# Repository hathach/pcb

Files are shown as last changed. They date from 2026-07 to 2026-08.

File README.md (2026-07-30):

# pcb — PCB projects home

One repo, Adafruit-style: every board lives in its own directory here,
alongside the shared knowledge, footprints, and tooling that future
boards reuse. Board pico2_trace_motherboard's original 50-commit build
history is preserved on branch `archive/pico2-original`.

## Layout

| Entry | What |
| --- | --- |
| `pico2_trace_motherboard/` | Board #1: Pico 2 SWD+ETM trace carrier + TinyUSB dev/test bench (RP2350, 2-layer). Ordered: JLCPCB **W2026073018593887**, 2026-07-30, 5 PCB / 2 assembled, $81.27. |
| `docs/pipeline.md` | The netlist-driven KiCad pipeline + gate battery + how to bootstrap board #2. |
| `docs/kicad-pcbnew-facts.md` | Verified KiCad 9 scripting landmines (pcbnew API, kicad-cli, footprints). |
| `docs/parts-palette.md` | LCSC/JLC-verified parts with tiers + JLC fee behavior. |
| `docs/PICO2_TRACE_PCB_HANDOFF.md` | Origin brief for board #1 (fly-wire measurements, requirements). |
| `lib/pcb.pretty/` | Audited shared footprints: USB-C C165948 lands (power-only + USB2-device renumbers), FTSH-110/105 1.27mm headers. Copy into each board's local `.pretty`. |
| `tools/jlc-cdp/` | Chrome-DevTools JLCPCB ordering driver + wizard-trap playbook. |
| `tools/board_semantic_compare.py` | Prove two `.kicad_pcb` are geometrically identical (regen gate). |
| `tools/align_md_tables.py` | Markdown table column aligner (house style). |

## Starting a new board

Read `docs/pipeline.md` — short version: copy `pico2_trace_motherboard/hw/`
wholesale, gut the board-specific tables, keep every helper and gate, seed
footprints from `lib/pcb.pretty/`, and regenerate-never-hand-nudge.

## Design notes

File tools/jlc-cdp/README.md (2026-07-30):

# jlc-cdp — drive JLCPCB ordering via Chrome DevTools Protocol

Minimal CDP driver used to place the pico2_trace_motherboard order
(W2026073018593887, 2026-07-30) when the Claude-in-Chrome extension was
wedged. Works against a dedicated Chrome instance so the main browser is
untouched.

## Setup

```bash
# one-time: clone the main profile so logins (JLCPCB, 1Password) come along
pkill -TERM -f '^/opt/google/chrome/chrome'; sleep 4
cp -a ~/.config/google-chrome ~/.cache/jlc-cdp-profile
rm -f ~/.cache/jlc-cdp-profile/Singleton*
google-chrome &                                     # main browser back
google-chrome --user-data-dir=$HOME/.cache/jlc-cdp-profile \
  --remote-debugging-port=9222 --no-first-run \
  --new-window https://cart.jlcpcb.com/shopcart/cart &

python3 -m venv venv && venv/bin/pip install websocket-client
```

## Usage

```bash
venv/bin/python cdp.py tabs                       # list pages
venv/bin/python cdp.py eval  '<js>'               # run JS in the JLC tab
venv/bin/python cdp.py nav   '<url>'
venv/bin/python cdp.py shot  out.jpg [quality]    # screenshot (viewport)
venv/bin/python cdp.py click <css-x> <css-y>      # trusted click
venv/bin/python cdp.py files '<selector>' /path…  # attach to <input type=file>
```

Targets the first tab whose URL contains `jlcpcb` (else the first page).

## JLC-wizard lessons (hard-won, 2026-07-30 session)

- Re-uploading gerbers inside Edit Order DETACHES the PCBA section —
  re-enable it via the `.switch-box.cursor-pointer` toggle, then re-set
  PCBA qty and Confirm Parts Placement (a Confirm modal follows).
- Saving after a gerber re-upload forks a NEW cart item (Y(n+1)) next to
  the old one — delete the stale group (`i.icon-remove_icon`, then the
  `el-popconfirm` Delete button).
- BOM/CPL re-upload: two `input[type=file]`s (BOM first); the
  "Process BOM & CPL" button needs a real (trusted) click at its rect.
- The Product Description cascader clears on every re-walk: open the
  `input[placeholder=Select]`, dispatch pointer/mouse event sequences on
  the `li` items (plain .click() does not work), category
  "Reserch\Education\DIY\Entertainment" → "Development Board - HS 847330".
- Element-UI chip selection state is unreliable to read from classes —
  verify with a screenshot; state probes can lie while the click landed.
- WebGL pages (placement viewer) stall Page.captureScreenshot; canvas
  toDataURL returns black (no preserveDrawingBuffer). Verify placement in
  the visible window or via JLC's paid Confirm-Parts-Placement service.
- CPL convention JLC ingests: KiCad board frame (y-down, footprint
  anchor, KiCad rotation). Do NOT convert to the gerber/pos.csv frame.
- Deselecting a matched BOM line does NOT remove its Extended loading
  fee; any THT line present brings back the ~$7 hand-solder+manual block.

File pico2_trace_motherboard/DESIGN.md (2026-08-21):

# Pico 2 SWD + ETM-Trace Motherboard — Design Spec

- **Status:** design approved, pending implementation (KiCad schematic + layout)
- **Date:** 2026-07-24
- **Target probe:** SEGGER J-Trace PRO Cortex-M (V2 today; V3+ for full-rate RP2350 streaming)
- **Target module:** Raspberry Pi **Pico 2** (RP2350A) — also mechanically/pin compatible with the original **Pico** (RP2040); the design must not break RP2040 use.

## 1. Purpose

A carrier "motherboard" that a Pico / Pico 2 plugs into. It does two jobs:

1. **Trace/debug adapter** — presents a proper ARM Cortex **Debug+ETM MIPI-20** connector (SWD + 4-bit parallel trace) to a SEGGER J-Trace, replacing the fly-wire rig whose measured limits are in `PICO2_TRACE_PCB_HANDOFF.md`. It also offers a plain 2×5 Cortex-Debug header and two 3-pin JST-SH debug jacks, so a plain J-Link or a Raspberry Pi Debug Probe can drive the same SWD.
2. **TinyUSB dev/test bench** — exercises TinyUSB on both USB back-ends: the RP2350 **native** USB controller (the module's micro-USB, device or OTG-host) and **PIO-USB** (a USB-A host port and a micro-B device port on GPIOs), plus the peripherals and observability needed to develop and debug them.

Prior art consulted: SEGGER STM32H7/STM32F407 Trace Reference Board schematics (calibre library), the existing `metro_m7_1011_trace` KiCad board, the Adafruit `MBAdafruitBoards` Eagle libraries, and the RP2350 / Pico 2 datasheets.

## 2. Goals & non-goals

**Goals**
- 2 layers max. Solid bottom ground plane for trace return.
- Socket carrier: Pico 2 removable; its micro-USB and BOOTSEL stay accessible (recovery flow depends on both).
- One-probe-at-a-time debug hub: J-Trace (MIPI-20), plain J-Link (2×5), or Pi Debug Probe (JST-SH), all reaching the Pico's SWD.
- Full-rate-capable trace routing (source-terminated, short, guarded) — beat the fly-wire seating lottery.
- Two PIO-USB roles (host + device) + native USB, with power flexible enough to run each case.
- Bench observability: USB probe points, host VBUS switching + current sense, UART console independent of the USB-under-test.

**Non-goals (explicitly excluded, YAGNI)**
- No microSD / MSC storage (dropped by decision).
- No I2S audio codec (UAC2), no Ethernet PHY (net class), no RGB/NeoPixel.
- No second PIO-USB *host* port (GPIO32/33 don't exist on RP2350A anyway).

## 3. Form factor & stackup

- **PCB:** 2-layer FR4, 1.6 mm. Top = components + all signal routing; **bottom = solid GND pour** (continuous under the entire trace group). Approx. 60 × 30 mm (may grow; not size-constrained).
- **Socket carrier, "double-female" (Cytron Maker-Pi-Pico style):** per side, an **inner** 1×20 female socket the Pico plugs into, plus an **outer** 1×20 female **breakout** row net-tied pin-for-pin, so every one of the 40 pins is available for jumper wires. Placed on the KiCad `Module:RaspberryPi_Pico_Common_THT` outline (correct 0.1″ pitch, 0.7″ row spacing, USB/BOOTSEL silk). Inner sockets = `Connector_PinSocket_2.54mm:PinSocket_1x20_P2.54mm_Vertical` ×2; outer breakout = same. Concrete socket part: Sullins PPTC201LFBN-RC or equiv.
- Pico 2 keeps male 0.1″ headers (pins down) and lifts out. Micro-USB + BOOTSEL overhang the board edge.

## 4. Connectors & jumpers (reference designators)

| Ref | Part | Purpose |
| --- | --- | --- |
| J1, J2 | 1×20 female socket ×2 (inner) | Pico 2 socket |
| J1B, J2B | 1×20 female socket ×2 (outer) | per-pin breakout |
| J3 | MIPI-20 Cortex Debug+ETM, 2×10 1.27 mm shrouded/keyed (Samtec ASP-152705-01 / FTSH-110-01-L-DV-K) | J-Trace: SWD + 4-bit ETM |
| J4 | JST-SH 1.0 mm 3-pin, right-angle | cable to the Pico 2 DEBUG port (brings SWD onto the board) |
| J5 | USB-A receptacle, THT right-angle | PIO-USB **host** port |
| J6 | 2×5 1.27 mm Cortex Debug (Conn_ARM_JTAG_SWD_10 / FTSH-105-01-L-DV-K) | plain J-Link: SWD only |
| J7 | JST-SH 1.0 mm 3-pin, right-angle | Raspberry Pi **Debug Probe** ("pico-debug") jack, mirrors J4 |
| J8 | USB Type-C receptacle, **power-only** (as-built 2026-07-30; was micro-B) | 5 V input for host-stack work |
| J9 | USB Type-C receptacle (as-built 2026-07-30; was micro-B) | PIO-USB **device** port |
| JP1 | 3-pin header + shunt | board 5 V source select: VBUS-net ↔ J-Trace 5 V |
| JP2, JP3 | 2-pin header + shunt (default fitted) | GP0 / GP6 GND **guard** jumpers |
| JP4 | 2-pin header + shunt (default fitted) | native VBUS-detect tap enable → GP16 (§9) |
| SW1 | tactile button, top-mount, medium | RUN reset |

Debug connectors J3/J4/J6/J7 grouped on one board edge so the shared SWD fan-out stays short.

## 5. Debug/trace signal maps

### 5.1 MIPI-20 (J3), per the SEGGER J-Trace pinout (image-authoritative; verified against SEGGER STM32H7 ref board)

| Pin | Net | Source | | Pin | Net | Source |
| --- | --- | --- | --- | --- | --- | --- |
| 1 | VTref | Pico 3V3_OUT (pin 36) | | 2 | SWDIO | JST-SH DEBUG (as-built: J7/J10, see §5.3) |
| 3 | GND | | | 4 | SWCLK | JST-SH DEBUG (as-built: J7/J10, see §5.3) |
| 5 | GND | | | 6 | SWO | **NC** (RP2350 has none) |
| 7 | KEY | NC | | 8 | TDI | **NC** |
| 9 | GND | (GNDDetect → GND, per SEGGER ref board) | | 10  | nRESET | RUN (pin 30) |
| 11  | **5V-Supply** | J-Trace 5 V → JP1 | | 12  | TRACECLK | GP1 (pin 2) via Rterm |
| 13  | **5V-Supply** | J-Trace 5 V → JP1 | | 14  | TRACEDATA0 | GP2 (pin 4) via Rterm |
| 15  | GND | | | 16  | TRACEDATA1 | GP3 (pin 5) via Rterm |
| 17  | GND | | | 18  | TRACEDATA2 | GP4 (pin 6) via Rterm |
| 19  | GND | | | 20  | TRACEDATA3 | GP5 (pin 7) via Rterm |

### 5.2 Cortex Debug 2×5 (J6) — plain J-Link

Signals identical to MIPI-20 pins 1–10, wired in parallel on the shared SWD net: 1 VTref, 2 SWDIO, 3 GND, 4 SWCLK, 5 GND, 6 SWO(NC), 7 KEY, 8 TDI(NC), 9 GND, 10 nRESET. No 5 V pin.

### 5.3 SWD source (as-built: J7 / J10 — see "As-built deltas")

As-built, the connector originally planned as J4 (a second JST-SH jack) was
never populated; its role is filled by **J7** (JST-SH 3-pin, pinout
**SWCLK / GND / SWDIO**, accepts a Raspberry Pi Debug Probe cable) and
**J10** (3-pin THT dupont header, same pin order). Both are cabled to the
Pico 2's own onboard JST-SH DEBUG port — J7 via a JST-SH-to-JST-SH cable,
J10 via a JST-SH-to-dupont cable (both ship with the Debug Probe) — and
both land on the shared SWDIO/SWCLK/GND net that feeds J3 pin 2/4 and J6
pin 2/4. **One probe connected at a time.**

### 5.4 Trace signal integrity

- **Source series termination 27 Ω** (0402) on TRACECLK + TRACEDATA0–3, placed at the Pico socket pins (the breakout tap is on the socket-side of Rterm, so Rterm isolates it from the line).
- Traces ≈ 0.3 mm, **runs < 30 mm**, CLK↔data length-matched within a few mm, no stubs. Not chasing exact 50 Ω (impractical on 2-layer 1.6 mm); solid bottom GND + short length + source termination is sufficient for the J-Trace PRO V2's real ceiling (in-spec 100 MHz TRACECLK, ~120 MHz tuned — measured: 120 MHz passes on this board; the "150 MHz" an earlier revision cited here is the V3/V4 product-page figure) — the ~40 MHz cliff recorded against the original fly-wire rig was a fly-wire signal-integrity limit, not a V2 hardware limit (see `docs/BRINGUP.md` "Trace bring-up ladder").
- GND stitching vias around the trace group. MIPI-20 within ~3 cm of the socket.
- **GP1–GP5 carry nothing else** — no pulls, LEDs, or loading beyond a via/breakout. The five outer breakout females for GP1–GP5 are silk-marked **"unplug while tracing"** (a wire there is a fat antenna on a 40–75 MHz line).
- **Guard pins:** GP0 (pin 1, directly against TRACECLK, no GND between) and GP6 (pin 9) each have a 2-pin **removable jumper to GND** (JP2/JP3, default fitted). Fitted = grounded guard (GND on both sides of TRACECLK); their breakout females double as scope/sniffer GND next to the trace bus. Removed = pin freed. Rule: with a guard fitted, keep that GPIO an input.

## 6. GPIO pin map (Pico/Pico 2, RP2350A header)

| GPIO | Function | Notes |
| ---- | --- | --- |
| 0 | GND guard (JP2) | pin 1, next to TRACECLK; jumper to GND, default on |
| 1 | TRACECLK | funcsel 9 (CORESIGHT); also default UART0 RX — **not routed to UART** |
| 2–5  | TRACEDATA0–3 | funcsel 9 |
| 6 | GND guard (JP3) | pin 9, next to trace block; jumper to GND, default on |
| 7 | spare | |
| 8 | I2C0 SDA (STEMMA-QT) | moved off GP6/7 to keep active signals away from trace |
| 9 | I2C0 SCL (STEMMA-QT) | |
| 10 | user LED | |
| 11 | DEV_DP pull-up enable (soft-connect) | drive high = attach (1.5 kΩ to DEV_DP), Hi-Z = detach; decision input = GP27 |
| 12 | UART0 TX (console) | remapped off GP0/1 → **full-duplex console during trace** |
| 13 | UART0 RX (console) | |
| 14 | user button | to GND |
| 15 | host VBUS fault | load-switch open-drain flag; `OVERCURR_DETECT`-capable pin |
| 16 | native VBUS-detect tap | `VBUS_DETECT`-capable; 8.2k/8.2k from VBUS net via JP-gate |
| 17 | host VBUS enable | load-switch enable; `VBUS_EN`-capable pin |
| 18 | PIO-USB device D+ (J9) | |
| 19 | PIO-USB device D− (J9) | |
| 20 | PIO-USB host D+ (J5) | |
| 21 | PIO-USB host D− (J5) | |
| 22 | spare | |
| 26 | VBUS current-sense (ADC) | shunt + INA181 amp output |
| 27 | J9 device VBUS-detect | plain GPIO, 8.2k/8.2k divider |
| 28 | spare | ADC-capable |

Module-internal pins (not on header, unusable by the carrier): GP23 (SMPS PS), GP24 (VBUS sense), GP25 (LED), GP29 (VSYS/3 ADC).

Placement rationale for USB-mux pins: GP15/16/17 sit on `OVERCURR_DETECT` / `VBUS_DETECT` / `VBUS_EN`-capable pins (funcsel `0x0a`, which rotates by GPIO mod 3), so the native controller's hardware VBUS enable/detect/overcurrent can be funcsel-tested later — while normally serving as plain GPIOs.

## 7. Power architecture

- **VBUS net = Pico pin 40** = the module's micro-USB VBUS = J8 power-USB = external-5V breakout injection. All one node (the micro-USB VBUS is an *input* as device / *output* as OTG host, so it must be a hard bidirectional tie — cannot be diode-isolated or switch-broken).
- **JP1 (3-pin)** selects the board 5 V: **USB side (VBUS net) ↔ J-Trace 5 V (MIPI-20 pins 11/13).**
  - `JP1 = USB`: board runs from the module micro-USB (device), or J8, or external-VBUS.
  - `JP1 = JTRACE`: J-Trace 5 V drives the VBUS net; the module micro-USB is freed to be an **OTG host** (its VBUS is now sourced from pin 40); Pico powered via pin 40 → onboard VBUS→VSYS diode → VSYS → 3V3.
- **Rule:** exactly one hard 5 V source on the VBUS net at a time (module-USB-from-PC, J8, external-VBUS, or J-Trace). JP1 keeps J-Trace off the USB side; the user avoids doubling the USB-side sources.
- **J-Trace 5 V is current-limited** (a few hundred mA) — hungry downstream devices → use J8 or a strong USB supply.
- The VBUS net also feeds the **PIO-USB host (J5) VBUS** through the host load switch (§8.1).
- **VSYS** remains reachable on the breakout female for independent bench powering — used when testing native VBUS-detect transitions (§9).

## 8. USB ports

### 8.1 PIO-USB host (J5) — GPIO20 (D+) / GPIO21 (D−)
- 22 Ω series (0 Ω option) at the GPIOs; **15 kΩ pulldowns** on D+/D− at the receptacle; **ESD array** (USBLC6-2SC6 class).
- **VBUS via a current-limited load switch** (TPS2051B / AP22653 / MIC2005 class): enable = GP17, open-drain fault = GP15, 10–22 µF bulk + 0.1 µF at the connector. (Replaces the earlier plain polyfuse; the switch's current limit + fault flag give host over-current control/observability.)
- **Probe points:** TP pads on D+/D− + GND at the port for the ataradov sniffer / scope.

### 8.2 PIO-USB device (J9; USB Type-C as-built 2026-07-30) — GPIO18 (D+) / GPIO19 (D−)
- Series R + **ESD array** on D+/D−.
- **1.5 kΩ D+ pull-up, firmware-driven soft-connect:** 1.5 kΩ from DEV_DP to **GP11**; firmware drives GP11 high (3.3 V) to present the pull-up ("attached") or reconfigures it to Hi-Z input to soft-disconnect, so the board only signals "attached" when a host's VBUS is present (board is often self-powered, so 3V3 is up regardless). Gate decision input is **GP27** VBUS-detect. (A gate FET driven from the VBUS-detect divider midpoint was rejected: as a source-follower it can only pull D+ to ~Vgate−Vth, below the FS-attach threshold.)
- **VBUS-detect:** 8.2 kΩ/8.2 kΩ divider from J9 VBUS → **GP27** (plain GPIO, read by the PIO-USB stack). Divider chosen so the pin sees ~2.5 V (logic-high, < 3.3 V so RP2040-safe, < 3.63 V so within the RP2350 unpowered-failsafe for hot-plug-while-off; R_bottom = 8.2 kΩ satisfies the RP2350-E9 external-pulldown requirement).
- Default **detect-only** (self-powered). Optional (DNP) diode from J9 VBUS to the VBUS net if bus-powered device operation is ever wanted.

### 8.3 Native USB (module micro-USB)
- Device (into a PC) or OTG host (§7, `JP1 = JTRACE`). VBUS = pin 40. VBUS-detect for the native *device* controller is handled on-module (GP24 SIO + R10/R1) / by `USB_PWR` override — nothing added.

## 9. Native VBUS-detect hardware test tap

To exercise the RP2350 native controller's **hardware** VBUS_DETECT (`SIE_STATUS.VBUS_DETECTED` + interrupt), not just the software override:
- **8.2 kΩ/8.2 kΩ divider from the VBUS net → GP16** (a `VBUS_DETECT`-capable pin, funcsel `0x0a`), through **JP4** (2-pin header, default fitted) to enable the tap (keeps GP16 free otherwise).
- Firmware sets GP16 funcsel = `0x0a`; the controller then senses VBUS in hardware.
- **Test methodology:** power the board from **VSYS** (breakout female), `JP1` off J-Trace and J8 unplugged, then plug/unplug the module micro-USB to a host to drive pin 40 (= VBUS net) high/low and confirm the detect + interrupt follow. (Powering from VBUS instead would make VBUS un-droppable without killing the board.)
- Note the RP2350 quirk this exercises: on the module, GP24 (wired to VBUS) funcsel `0x0a` = `OVERCURR_DETECT`, and GP25 (which can do `VBUS_DETECT`) is the LED with no VBUS — so the module can't hardware-detect VBUS on its own pins; this header tap is what makes the test possible.

## 10. Peripherals / bench aids

- **UART0 console header** — 3-pin TX/RX/GND on GP12/13 (funcsel `0x02` = UART0). Matches the SDK default `uart0`, full-duplex during trace.
- **STEMMA-QT / Qwiic I2C** — JST-SH 4-pin on I2C0 GP8/9 (Adafruit `STEMMAQT` footprint).
- **1 user button** (GP14 → GND), **1 user LED** (GP10), **1 power LED** on the 5 V rail.
- **VBUS current-sense** — high-side shunt (~0.1 Ω) + INA181/INA180 amp → GP26 (ADC). (Alt, DNP option: INA219 on the I2C bus — richer, frees GP26.)

## 11. Firmware / BSP implications (`hw/bsp/rp2040/boards/raspberry_pi_pico2`, branch `claude/add-etm-trace-skill`)
- UART0 remapped: `PICO_DEFAULT_UART=0`, `..._TX_PIN=12`, `..._RX_PIN=13`. GP0/GP1 no longer UART; GP1 = TRACECLK only.
- Trace on GP1–GP5 (funcsel 9) owned by the J-Link built-in RP2350 script; **no custom JLinkScript**. Keep GP1 unrouted to non-trace functions (satisfied).
- GP0 / GP6 are GND-guard pins: keep as inputs (do not drive).
- PIO-USB host on GP20/21; PIO-USB device on GP18/19.
- Host VBUS: enable GP17, fault GP15 (usable as plain GPIO or funcsel `VBUS_EN`/`OVERCURR_DETECT`).
- Native VBUS-detect test: GP16 funcsel `0x0a`.
- J9 device VBUS-detect on GP27; gate the D+ pull-up on it.
- Existing TRACE_ETM firmware (clears TIMER0/1 DBGPAUSE, TX-only console) still applies, except the console is now full-duplex on GP12/13.

## 12. Deliverables & files

Project root: `~/code/jtrace/pico2_trace_motherboard/` (its own git repo; siblings are per-board).
- KiCad 9 project (`.kicad_pro/.kicad_sch/.kicad_pcb`) + a local `.pretty` for converted Adafruit / metro footprints.
- BOM (`docs/BOM.csv`).
- One-page bring-up note (`docs/BRINGUP.md`).
- Final schematic PDF + bring-up note also archived to the calibre library when done.

Footprint sources: KiCad stock (MIPI-20 = `PinHeader_2x10_P1.27mm_Vertical_SMD` refined to FTSH-110/ASP-152705; 2×5 = `PinHeader_2x05_P1.27mm_Vertical_SMD`; USB-A, JST-SH, PinSocket, USB micro-B); Adafruit Eagle `.lbr` (STEMMA-QT, load switch, ESD, tactile) imported into the local `.pretty`; metro_m7 `.pretty` (boxed 2×5, JST-SH) for reuse.

## 13. Validation plan (per handoff, on the J-Trace rig, ~30 min)
1. Continuity + SEGGER demo: `~/code/jtrace/RaspBerryPi_RP2350_M33_0_TraceExample`.
2. Ladder blinky 48 → 80 MHz core (→120/150 on V3), one `etm_capture.py` each.
3. Dense data: TRACE_ETM cdc_msc ×3 per passing rung (USB-enumeration burst = the killer test).
4. Wire/line bisect on failure (`--trace-width 1/2/4`, `--trace-timing`).
5. Accept: 3/3 full-total captures at target clock; update `board.cmake` + `ozone/rp2350.jdebug` + the SKILL.md board row together.
6. USB bench checks: native device enum (cafe:*), PIO-USB host enum of a plugged device, PIO-USB device enum into a PC, native OTG host (JP1=JTRACE), host VBUS switch on/off + over-current flag, native hardware VBUS-detect (§9), UART0 console, I2C peripheral.

## 14. Open / DNP items
- Optional DNP 1×6 100-mil test header on the five trace nets (the outer breakout females already serve this).
- INA219-over-I2C as an alternative to the analog current-sense (DNP footprint).
- J9 bus-power diode (DNP).
- 22 Ω PIO-host series resistors may be populated 0 Ω if signalling is clean.

## As-built deltas (added post-implementation, do not edit the sections above)

This spec's intent is preserved above as originally approved. The board
is now implementation-complete and frozen at commit `6d67559` in the
`kicad-build` branch; the divergences below are where the built board
departs from what this document specifies. Treat `docs/BRINGUP.md` as
the as-built source of truth for behavior, and `docs/BOM.csv`/
`fab/MANIFEST.txt` for what's actually orderable.

- **§3 Form factor**: board is **92 × 64 mm**, not the "approx. 60 × 30 mm
  (may grow)" placeholder. Bottom is **not** a solid GND pour — see
  `docs/BRINGUP.md` "Board summary" for the measured F.Cu/B.Cu split
  (F.Cu is the near-plane layer; B.Cu carries ~49% of signal routing and
  is fragmented into pour islands).
- **§3/§4 Socket carrier**: the inner Pico sockets are **not** separate
  `J1`/`J2` refs — that pair of land patterns is a single footprint
  under the ref **`PICO`** (stock `Module:RaspberryPi_Pico_Common_THT`).
  `J1`/`J2` never existed as populated parts.
- **§4 Connectors**: `J4` (the second JST-SH SWD cable-in jack) was
  **removed**; its role is filled by **`J10`**, a 3-pin THT dupont
  header (SWCLK/GND/SWDIO), added instead — see §5.3 above, corrected
  in place.
- **§4 `J5`**: built as an **SMD** GCT USB1046 (signal pads) + 2 THT
  mechanical mounting posts, not the THT right-angle part originally
  specified.
- **§4 `J3`/`J6`**: use locally-converted footprints
  (`pico2_trace:FTSH-110-01-DV` / `FTSH-105-01-DV`) drawn from the
  Samtec FTSH mechanical drawings for pad geometry, but `docs/BOM.csv`
  sourcing prefers a **generic 1.27 mm-pitch SMD shrouded-header clone**
  (LCSC-stocked) over the premium Samtec part, which is kept only as
  the documented alternate — see `docs/PARTS.md` §5.
- **§5.1/§5.3 SWD source**: fixed in place above (was "J4", now
  "J7/J10").
- **§7 Power architecture**: `JP1 = JTRACE` no longer just powers the
  host port — it now feeds the **Pico itself** through the added
  `D_VSYS` Schottky diode-OR into `VSYS`, instead of the originally
  specified hard tie between J-Trace's 5 V pins and pin 40/`VBUS_NET`.
  See `docs/BRINGUP.md` "Power rules" for the full as-built behavior
  (this is a safer arrangement than the hard tie this section
  describes, not a regression).
- **§14 DNP test header**: the optional DNP 1×6 100-mil trace test
  header was **removed outright** (not just left DNP) on signal-
  integrity grounds — it would have sat as a stub on the length-matched
  trace bundle, which §5.4 itself forbids ("no other loading"). The
  outer breakout females still serve the same probing purpose.
- **Four parts added in `6d67559`**, none in this spec: `D_VSYS`
  (the VSYS feed above), `C_P3V3_1`/`C_P3V3_2` (P3V3 decoupling),
  `C_HSW_IN` (load-switch input bypass). See `docs/BRINGUP.md`
  "As-built additions" for placement and the two GND-pour-island fixes
  they required.
- **§4 `J8` (2026-07-30, at order time)**: the power-only micro-B was
  replaced by a **USB Type-C receptacle** (HRO TYPE-C-31-M-12 land,
  LCSC C165948, JLC Basic) with **`R_CC1`/`R_CC2`** 5.1 kΩ CC
  pull-downs added (a compliant Type-C source presents no VBUS without
  Rd). Same electrical role (5 V into `VBUS_NET`), same flush-lip
  position on the top edge. One deliberate quirk: the connector's
  second VBUS pad column (pins A9/B4) is **board-NC** — the footprint's
  NPTH alignment peg geometrically blocks every legal escape from that
  column, and the mating plug parallels all four VBUS beams anyway, so
  the fed A4/B9 column (2 × 1.25 A contacts) carries the input with
  full margin. Board regenerated from scratch by the `hw/` pipeline
  (proven byte-equivalent first); DRC/ERC/netlist-parity/pour gates all
  green.
- **§4 `J9` (2026-07-30, same order session)**: the PIO-USB device
  micro-B was also replaced by a **USB Type-C receptacle** (same HRO
  land, LCSC C165948) with **`R_CC3`/`R_CC4`** Rd pull-downs (a Type-C
  host does not detect a device without them). The USB2 D+/D- pad pairs
  (A6/B6, A7/B7) are bridged on-board (interleaved pads force a
  two-layer weave); SBU and the second VBUS column are NC. The
  VBUS-detect divider (`R_J9VD_T/B`) moved from beside the old micro-B
  to the open band SOUTH of the connector. Same gates re-run, all
  green.

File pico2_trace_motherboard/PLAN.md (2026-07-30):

# Pico 2 Trace Motherboard — Implementation Plan

> **For agentic workers:** REQUIRED SUB-SKILL: Use superpowers:subagent-driven-development (recommended) or superpowers:executing-plans to implement this plan task-by-task. Steps use checkbox (`- [ ]`) syntax for tracking.

**Goal:** Produce a manufacturable KiCad 9 project (schematic + 2-layer PCB, DRC-clean, with gerbers/BOM/bring-up note) for the Pico 2 SWD+ETM trace motherboard specified in `DESIGN.md`.

**Architecture:** Connectivity is authored **once** as a Python single-source-of-truth (`hw/netlist.py`: a parts table + a nets table transcribed from `DESIGN.md`). That model (a) drives `pcbnew` scripting to instantiate footprints, nets, board outline, stackup, net classes, placement, the SI-critical routing, and the ground pour, and (b) emits a KiCad `.net` netlist used for ERC/BOM cross-checks and to draw the schematic. Verification is by `kicad-cli sch erc`, `kicad-cli pcb drc --format json` (parsed in Python — never grep stdout), and Python assertions over the model/board. The visual schematic is drawn in eeschema from the netlist + the Adafruit reference schematics; Task 1 first attempts to automate it via SKiDL's `KICAD9` target in a venv, and if that yields a KiCad-9-clean schematic it supersedes the manual draw.

**Tech Stack:** KiCad 9.0.2 (`kicad-cli`, `pcbnew` Python API), Python 3 + pytest, KiCad stock symbol/footprint libraries, Adafruit `MBAdafruitBoards` Eagle libraries (reference), a project venv for optional schematic automation.

## Verified environment facts (from review, KiCad 9.0.2 — obey these)

- `Module:RaspberryPi_Pico_Common_THT` has 40 THT pads numbered **"1"–"40" by physical header pin** (1–20 left column, 21–40 right). This footprint **is** the inner-socket land pattern — do **not** add separate inner-socket footprints on top of it.
- `pcbnew.SaveBoard` does **not** persist net classes (they live in `.kicad_pro`) — after setting them call `pcbnew.GetSettingsManager().SaveProject()`.
- `ZONE_FILLER(b).Fill()` **segfaults on an in-memory board** — only fill a board freshly `LoadBoard`-ed from disk.
- `kicad-cli pcb drc --exit-code-violations` returns **exit 5** on *any* violation including warnings and `unconnected_items` and the empty-board `invalid_outline`. Gate on a **parsed JSON report**, not the exit code or stdout text.
- `--schematic-parity` is a **bare boolean flag** (no `=yes/no`); parity needs a fully-annotated schematic with footprint↔symbol UUID links that pcbnew-scripted footprints don't have — treat parity as advisory and rely on the Task-9 netlist compare instead.
- `VECTOR2I.Distance()` raises `TypeError`; use `(p1 - p2).EuclideanNorm()`. `GetUnconnectedCount(False)` requires the arg. `pcbnew.AddHole` does not exist (use `MountingHole` footprints). `b.GetNetClasses()` iterates **wxString keys** (`{str(k) for k in b.GetNetClasses()}`). `LoadBoard` returns `None` (no raise) on a bad path — assert non-None. DRC violation exit code is **5**, never 1.

## Global Constraints

- **2 layers max**, FR4 1.6 mm. Bottom copper = continuous GND pour under the whole trace group.
- Target modules: **Pico 2 (RP2350A) and original Pico (RP2040)** — nothing may exceed RP2040 limits (no bare 5 V on a GPIO; VBUS-sense uses an 8.2 k/8.2 k divider).
- **Trace nets (GP1–GP5):** 27 Ω source series at the socket pins, runs < 30 mm, CLK↔data length-matched within a few mm, no other loading; MIPI-20 within ~3 cm of the socket. GP0/GP6 are GND-guard pins (removable jumpers).
- Pin map, connector list, and net topology are **exactly** as in `DESIGN.md` §4–§10 — that document is authoritative; this plan implements it. **All 40 Pico pins** get a net (function nets, or breakout-only nets) — none may be left unassigned.
- Every table written into any doc is column-aligned (`tools/align_md_tables.py`).
- Deliverables land in `~/code/jtrace/pico2_trace_motherboard/`; final schematic PDF + bring-up note also archived to the calibre library.

## File structure

| Path | Responsibility |
| --- | --- |
| `pico2_trace.kicad_pro` | KiCad project file (generated by `SaveBoard`/`SaveProject` — never hand-write) |
| `pico2_trace.kicad_sch` | Schematic (root + hierarchical sheets) |
| `pico2_trace.kicad_pcb` | Board |
| `pico2_trace.pretty/` | Local footprint library (custom shroud footprints) |
| `sym/pico2_trace.kicad_sym` | Local symbol library (Pico module, MIPI-20, etc.) |
| `hw/__init__.py` | Makes `hw/` a package (import + `python3 -m hw.x` both work) |
| `hw/netlist.py` | Single source of truth: `PARTS` + `NETS`; helpers; emits `.net` |
| `hw/fp_lib.py` | Footprint resolution table (part class → `library:footprint`) |
| `hw/build_board.py` | `pcbnew` driver: footprints, nets, stackup, classes, outline |
| `hw/place.py` | Placement coordinate table |
| `hw/route_trace.py` | `pcbnew` driver: SI-critical routing + GND pour |
| `hw/checks.py` | pytest assertions + `--compare-netlists` + `--drc-gate` helpers |
| `tools/align_md_tables.py`  | (exists) markdown table aligner |
| `docs/BOM.csv` | Bill of materials (generated) |
| `docs/BRINGUP.md` | One-page bring-up note |
| `fab/` | Generated gerbers, drill, position files, 3D render |

---

### Task 1: Project scaffold, toolchain verification, SKiDL spike

**Files:** Create `pico2_trace.kicad_pcb` (with placeholder outline), `fp-lib-table`, `sym-lib-table`, `hw/__init__.py`; create `.venv/` (gitignored); modify `.gitignore` (add `.venv/`, `fab/`).

**Interfaces:** Produces a valid project `kicad-cli` accepts and a recorded `SCHEMATIC_MODE ∈ {auto, gui}` in `docs/BRINGUP.md`.

- [ ] **Step 1: Create the board (with a placeholder outline so DRC is meaningful) + lib tables**

```bash
cd ~/code/jtrace/pico2_trace_motherboard && mkdir -p pico2_trace.pretty sym hw fab docs && touch hw/__init__.py
python3 - <<'PY'
import pcbnew
b = pcbnew.BOARD()
# placeholder 65x34 mm Edge.Cuts rectangle (Task 11 replaces it)
for (x1,y1,x2,y2) in [(0,0,65,0),(65,0,65,34),(65,34,0,34),(0,34,0,0)]:
    s=pcbnew.PCB_SHAPE(b); s.SetShape(pcbnew.SHAPE_T_SEGMENT); s.SetLayer(pcbnew.Edge_Cuts)
    s.SetStart(pcbnew.VECTOR2I(pcbnew.FromMM(x1),pcbnew.FromMM(y1)))
    s.SetEnd(pcbnew.VECTOR2I(pcbnew.FromMM(x2),pcbnew.FromMM(y2))); b.Add(s)
b.SetCopperLayerCount(2)
pcbnew.SaveBoard("pico2_trace.kicad_pcb", b)   # also writes a full .kicad_pro/.kicad_prl
print("board saved")
PY
printf '(fp_lib_table\n  (lib (name "pico2_trace")(type "KiCad")(uri "${KIPRJMOD}/pico2_trace.pretty")(options "")(descr ""))\n)\n' > fp-lib-table
printf '(sym_lib_table\n  (lib (name "pico2_trace")(type "KiCad")(uri "${KIPRJMOD}/sym/pico2_trace.kicad_sym")(options "")(descr ""))\n)\n' > sym-lib-table
```
Do **not** hand-write `.kicad_pro` — `SaveBoard` produced a complete one.

- [ ] **Step 2: Baseline DRC (JSON, parsed — establishes the gate pattern)**

```bash
kicad-cli pcb drc --format json -o /tmp/drc.json pico2_trace.kicad_pcb >/dev/null 2>&1
python3 -c "import json;v=json.load(open('/tmp/drc.json'))['violations'];print('violations:',[x['type'] for x in v])"
```
Expected: `violations: []` (placeholder outline present, empty board). If you skipped the outline you'd instead see `['invalid_outline']` at exit 5 — that is the reason for the placeholder.

- [ ] **Step 3: SKiDL spike — actually generate a KiCad-9 schematic (not just `import skidl`)**

```bash
python3 -m venv .venv && . .venv/bin/activate
pip install -q skidl kinet2pcb kinparse 2>&1 | tail -2 || echo "PIP_FAILED"
KICAD9_SYMBOL_DIR=/usr/share/kicad/symbols python3 - <<'PY' 2>&1 | tail -6
try:
    import skidl
    from skidl import Part, Net, set_default_tool, KICAD9, generate_schematic
    set_default_tool(KICAD9)
    r1=Part("Device","R",value="8.2k",footprint="Resistor_SMD:R_0402_1005Metric")
    n=Net("N1"); n += r1[1]
    generate_schematic()          # writes ./*.kicad_sch
    print("SKIDL_GEN_OK", __import__('glob').glob('*.kicad_sch'))
except Exception as e:
    print("SKIDL_UNAVAILABLE", type(e).__name__, e)
PY
deactivate
```

- [ ] **Step 4: Smoke-test any generated schematic + record the decision**

If Step 3 printed `SKIDL_GEN_OK`, run `kicad-cli sch erc <that>.kicad_sch; echo exit=$?` — if ERC runs (exit 0/5, not a parse crash) set `SCHEMATIC_MODE=auto`, else `gui`. If Step 3 failed (`PIP_FAILED`/`SKIDL_UNAVAILABLE`) set `SCHEMATIC_MODE=gui`. Write the mode + evidence into `docs/BRINGUP.md` under `## Toolchain`. (Known SKiDL caveats to note: flat output, crude placement, output filename fixed to `./*.kicad_sch`, custom symbols must pre-exist.)

- [ ] **Step 5: Commit** — `git add -A && git commit -m "scaffold: KiCad project + placeholder outline + SKiDL spike result"`

---

### Task 2: Local footprint & symbol libraries

**Files:** Create `hw/fp_lib.py`; custom footprints in `pico2_trace.pretty/`; `sym/pico2_trace.kicad_sym`.

**Interfaces:** Produces `FP: dict[part_class -> (lib, footprint)]` resolving every part class in `PARTS`; a symbol lib covering custom parts.

Footprint sourcing (KiCad stock unless noted; Adafruit `.lbr`/`.sch` are references only):

| Part class | Footprint | Source |
| --- | --- | --- |
| `pico_socket` (PICO) | `Module:RaspberryPi_Pico_Common_THT` (40 THT pads = inner sockets) | stock (IS the socket land pattern — BL-1) |
| `breakout_1x20` (J1B,J2B) | `Connector_PinSocket_2.54mm:PinSocket_1x20_P2.54mm_Vertical` | stock |
| `mipi20` (J3) | `pico2_trace:FTSH-110-01-DV` (2×10 1.27, keyed shroud) | derive from `PinHeader_2x10_P1.27mm_Vertical_SMD` |
| `cortex10` (J6) | `pico2_trace:FTSH-105-01-DV` (2×5 1.27, keyed) | derive from `PinHeader_2x05_P1.27mm_Vertical_SMD` |
| `jst_sh3` (J4, J7) | `Connector_JST:JST_SH_SM03B-SRSS-TB_1x03-1MP_P1.00mm_Horizontal` | stock |
| `jst_sh4` (J_STEMMA) | `Connector_JST:JST_SH_SM04B-SRSS-TB_1x04-1MP_P1.00mm_Horizontal` | stock (= Adafruit STEMMA-QT) |
| `usb_a` (J5) | `Connector_USB:USB_A_Molex_67643_Horizontal` | stock |
| `usb_microb` (J8, J9) | `Connector_USB:USB_Micro-B_Molex_47346-0001` | stock |
| `hdr_1x03` (J_UART, JP1) | `Connector_PinHeader_2.54mm:PinHeader_1x03_P2.54mm_Vertical` | stock |
| `hdr_1x02` (JP2,JP3,JP4) | `Connector_PinHeader_2.54mm:PinHeader_1x02_P2.54mm_Vertical` | stock |
| `loadswitch` (U_HSW) | `Package_TO_SOT_SMD:SOT-23-5` | stock; ref `adafruit_power.lbr` |
| `esd6` (ESD_H, ESD_D) | `Package_TO_SOT_SMD:SOT-23-6` (USBLC6-2SC6) | stock |
| `isense` (U_ISNS, INA181) | `Package_TO_SOT_SMD:SOT-23-5` | stock |
| `fet3` (Q_DPU) | `Package_TO_SOT_SMD:SOT-23` (D+ pull-up gating FET) | stock (fixes G-5) |
| `button` (SW1) | `Button_Switch_SMD:SW_SPST_B3S-1000` | stock; ref `adafruit_electromech.lbr` |
| `testpoint` (TP1..TP3) | `TestPoint:TestPoint_Pad_D1.5mm` | stock (fixes G-3) |
| `mounthole` | `MountingHole:MountingHole_3.2mm_M3` | stock (fixes BL-10) |
| `r0402`,`c0402`,`led0603`,`shunt` | stock `Resistor_SMD:R_0402_1005Metric`, `C_0402_1005Metric`, `LED_SMD:LED_0603_1608Metric`, `R_1206_3216Metric` | stock |

- [ ] **Step 1:** Write `hw/fp_lib.py` with `FP = {...}` (one entry per row).
- [ ] **Step 2:** Create the two shroud footprints in `pico2_trace.pretty/` by copying the stock 1.27 mm SMD pin-header `.kicad_mod` and adding a keyed-shroud silk/courtyard + pin-1 marker (keep pad numbering 1–20 / 1–10).
- [ ] **Step 3: Verify every footprint resolves**

```bash
python3 - <<'PY'
import os
from hw.fp_lib import FP
for cls,(lib,fp) in FP.items():
    p = f"pico2_trace.pretty/{fp}.kicad_mod" if lib=="pico2_trace" else f"/usr/share/kicad/footprints/{lib}.pretty/{fp}.kicad_mod"
    assert os.path.exists(p), f"MISSING {cls}: {p}"
print("all", len(FP), "footprint classes resolve")
PY
```
Expected: `all N footprint classes resolve` (fix MISSING via `ls /usr/share/kicad/footprints/<lib>.pretty/`).

- [ ] **Step 4:** Author custom symbols in `sym/pico2_trace.kicad_sym` (40-pin Pico module by physical pin; MIPI-20; 2×5 Cortex). This is scripted s-expr authoring, **not** a GUI step; verify with `kicad-cli sym export svg sym/pico2_trace.kicad_sym -o /tmp/sym.svg` (must not error). Stock symbols cover R/C/LED/USB/JST/FET/SOT.
- [ ] **Step 5: Commit** — `git commit -am "lib: footprint resolution map + shroud footprints + custom symbols"`

---

### Task 3: Connectivity model — parts + helper functions

**Files:** Create `hw/netlist.py` (`PARTS` + helpers); `hw/checks.py::test_parts`.

**Interfaces / Produces:**
- `PARTS: dict[ref -> Part(ref, value, fp_class, pins:dict[padname -> netname|None], nc:set[padname], dnp:bool)]`.
- `net_pins(net) -> set[(ref, pad)]` — all pads on a net.
- `series_between(net_a, net_b, r_ref=None) -> bool` — True iff a single 2-pin resistor bridges `net_a` and `net_b` (any R if `r_ref is None`, else exactly that ref).
- `divider_ratio(top_net, mid_net) -> (r_top_ohms, r_bot_ohms)` — follows `top_net`→R→`mid_net` and `mid_net`→R→`GND`, returning the two resistor values; transparently traverses a fitted jumper (e.g. JP4) in the top leg.
- `PINMAP: dict[gpio_int -> label_str]` — GPIO→function label ("TRACECLK","TD0","GUARD","I2C0_SDA","LED_USER","BTN_USER","NATIVE_VBUS_DET",…), derived from `PARTS["PICO"].pins`.

- [ ] **Step 1:** Write `PARTS` for every component in `DESIGN.md` §4/§6: `PICO` (fp_class `pico_socket`, pins "1".."40"); breakout `J1B`,`J2B` (`breakout_1x20`); `J3`–`J9`, `J_UART`, `J_STEMMA`, `JP1`–`JP4`, `SW1`; `U_HSW`, `ESD_H`, `ESD_D`, `U_ISNS`, `Q_DPU`, `R_SHUNT`; `Rt1`–`Rt5` (27 Ω), the 22 Ω USB series, 15 kΩ pulldowns, 1.5 kΩ pull-up, the four 8.2 kΩ divider resistors, LED resistors; `TP1`–`TP3`; the user/power LEDs. Mark DNP parts (`dnp=True`, fixes G-7): `U_INA219_ALT`, `D_J9_BUSPWR`, `J_TRACE_TP` (1×6). Implement the four helper functions.
- [ ] **Step 2: Write the failing test**

```python
# hw/checks.py
from hw.netlist import PARTS
from hw.fp_lib import FP
def test_parts():
    need = {"PICO","J1B","J2B","J3","J4","J5","J6","J7","J8","J9","J_UART","J_STEMMA",
            "JP1","JP2","JP3","JP4","SW1","U_HSW","Q_DPU","U_ISNS","TP1","TP2","TP3"}
    assert need <= set(PARTS), f"missing refs: {need - set(PARTS)}"
    assert len(PARTS["PICO"].pins) == 40
    for ref,p in PARTS.items():
        assert p.fp_class in FP, f"{ref}: unknown fp_class {p.fp_class}"
```

- [ ] **Step 3:** `python3 -m pytest hw/checks.py::test_parts -q` → FAIL, iterate to PASS. **Step 4:** commit `"netlist: parts table + graph helpers"`.

---

### Task 4: Power & ground nets (all Pico power/ground pins)

**Files:** Modify `hw/netlist.py`; `hw/checks.py::test_power_nets`.

**Produces:** `GND, VBUS_NET, V5_JTRACE, VSYS, P3V3, HOST_VBUS`, plus nets for Pico pins **35 (ADC_VREF)** and **37 (3V3_EN)** (fixes G-2).

- [ ] **Step 1:** Per `DESIGN.md` §7/§8.1: JP1 selects `VBUS_NET`↔`V5_JTRACE`; `VBUS_NET`→`U_HSW` VIN, `HOST_VBUS`=`U_HSW` VOUT→J5 VBUS (+bulk C); MIPI-20 pins 11/13→`V5_JTRACE`; PICO "40"→`VBUS_NET`, "39"→`VSYS`, "36"→`P3V3`, "35"→`AREF`, "37"→`P3V3_EN`; power LED on `VBUS_NET`; all grounds (PICO 3/8/13/18/23/28/33/38; MIPI-20 3/5/9/15/17/19; every connector GND)→`GND`.
- [ ] **Step 2: Failing test**

```python
def test_power_nets():
    from hw.netlist import net_pins, PARTS
    assert net_pins("V5_JTRACE") >= {("J3","11"),("J3","13"),("JP1","1")}
    assert ("J5","VBUS") in net_pins("HOST_VBUS") and ("U_HSW","VOUT") in net_pins("HOST_VBUS")
    assert ("PICO","40") in net_pins("VBUS_NET")
    for pad in ("35","37"):                       # no orphan power pins (G-2)
        assert PARTS["PICO"].pins[pad] is not None, f"PICO pin {pad} unassigned"
```

- [ ] **Step 3:** run → fix. **Step 4:** commit `"netlist: power & ground nets (incl. pins 35/37)"`.

---

### Task 5: Debug & trace nets

**Files:** Modify `hw/netlist.py`; `hw/checks.py::test_trace_nets`.

**Produces:** `SWDIO, SWCLK, NRESET, VTREF, TRACECLK, TD0..TD3`, source-side `GP1..GP5`.

- [ ] **Step 1:** Per `DESIGN.md` §5 (with the corrected `series_between` signature): SWDIO/SWCLK from J4+J7 fan to J3-2/4 and J6-2/4; `NRESET`=PICO "30"→J3-10, J6-10, SW1; `VTREF`=PICO "36" region net→J3-1, J6-1. Trace: PICO "2"=`GP1`→Rt1→`TRACECLK`→J3-12; "4"/"5"/"6"/"7"=`GP2..GP5`→Rt2..Rt5→`TD0..TD3`→J3-14/16/18/20. Guards: JP2 (GP0↔GND), JP3 (GP6↔GND).
- [ ] **Step 2: Failing test**

```python
def test_trace_nets():
    from hw.netlist import net_pins, series_between
    for gp,td,rt,pin in [("GP1","TRACECLK","Rt1","12"),("GP2","TD0","Rt2","14"),
                         ("GP3","TD1","Rt3","16"),("GP4","TD2","Rt4","18"),("GP5","TD3","Rt5","20")]:
        assert series_between(gp, td, rt), f"{rt} not in series {gp}->{td}"
        assert ("J3",pin) in net_pins(td)
    for probe in ("SWDIO","SWCLK"):
        refs = {r for r,_ in net_pins(probe)}
        assert {"J3","J4","J6","J7"} <= refs, f"{probe} not on all debug conns: {refs}"
    assert ("SW1","1") in net_pins("NRESET")
```

- [ ] **Step 3:** run → fix. **Step 4:** commit `"netlist: debug & trace nets"`.

---

### Task 6: USB host, USB device, VBUS-detect taps

**Files:** Modify `hw/netlist.py`; `hw/checks.py::test_usb_nets`.

**Produces:** `HOST_DP,HOST_DM` (GP20/21), `DEV_DP,DEV_DM` (GP18/19), `NATIVE_VBUS_DET` (GP16), `DEV_VBUS_DET` (GP27), `J9_VBUS`, and the D+ gating FET wiring.

- [ ] **Step 1:** Per `DESIGN.md` §8/§9: host J5 D+=GP20/D−=GP21 via 22 Ω, 15 kΩ pulldowns to GND, `ESD_H`; TP1/TP2/TP3 on `HOST_DP`/`HOST_DM`/`GND` (fixes G-3); host VBUS via `U_HSW` (EN=GP17, FLG=GP15). Device J9 D+=GP18/D−=GP19 via series, `ESD_D`; 1.5 kΩ D+ pull-up switched by `Q_DPU` gated on `DEV_VBUS_DET`; `J9_VBUS`→8.2k/8.2k→`DEV_VBUS_DET`(GP27). Native tap: `VBUS_NET`→JP4→8.2k/8.2k→`NATIVE_VBUS_DET`(GP16). Shunt `R_SHUNT` in `HOST_VBUS`→`U_ISNS`→`ISENSE`(GP26).
- [ ] **Step 2: Failing test** (net names now consistent with `PINMAP`)

```python
def test_usb_nets():
    from hw.netlist import net_pins, series_between, divider_ratio
    assert divider_ratio("VBUS_NET","NATIVE_VBUS_DET") == (8200,8200)   # via JP4
    assert divider_ratio("J9_VBUS","DEV_VBUS_DET") == (8200,8200)
    assert series_between("GP20","HOST_DP")                              # 22R series (any R)
    assert ("U_HSW","EN") in net_pins("HOST_VBUS_EN") and ("U_HSW","FLG") in net_pins("HOST_VBUS_FLT")
    assert {("TP1",_) for _ in [1]} & set() or ("TP1","1") in net_pins("HOST_DP")   # probe point present
    assert ("Q_DPU","G") in net_pins("DEV_VBUS_DET")                     # gating FET controlled by detect
```

- [ ] **Step 3:** run → fix. **Step 4:** commit `"netlist: USB host/device, VBUS-detect taps, probe points, D+ gate FET"`.

---

### Task 7: Peripherals, breakout ties, full pin-map lock

**Files:** Modify `hw/netlist.py`; `hw/checks.py::{test_pinmap,test_breakout}`.

**Produces:** console/I2C/LED/button nets; the **J1B/J2B breakout pin-for-pin ties** (fixes G-1); completed `PINMAP`.

- [ ] **Step 1:** Per `DESIGN.md` §6/§10: UART0 GP12(TX)/GP13(RX)→`J_UART`; I2C0 GP8(SDA)/GP9(SCL)→`J_STEMMA`; user LED GP10→R→`GND`; user button GP14→`GND`; GP0/GP6=guards; GP7/11/22/28 breakout-only.
- [ ] **Step 2: Breakout ties** — for `n` in 1..40: set `J1B` pad `n` **and** `J2B` pad `n` (whichever row that physical pin lands on) to the **same net as `PICO` pad `n`**. Implement as a loop over `PARTS["PICO"].pins`.
- [ ] **Step 3: Failing tests**

```python
def test_pinmap():
    from hw.netlist import PINMAP
    expect = {0:"GUARD",1:"TRACECLK",2:"TD0",3:"TD1",4:"TD2",5:"TD3",6:"GUARD",
              8:"I2C0_SDA",9:"I2C0_SCL",10:"LED_USER",12:"UART0_TX",13:"UART0_RX",
              14:"BTN_USER",15:"HOST_VBUS_FLT",16:"NATIVE_VBUS_DET",17:"HOST_VBUS_EN",
              18:"DEV_DP",19:"DEV_DM",20:"HOST_DP",21:"HOST_DM",26:"ISENSE",27:"DEV_VBUS_DET"}
    for gp,fn in expect.items():
        assert PINMAP[gp]==fn, f"GP{gp}: {PINMAP.get(gp)} != {fn}"

def test_breakout():
    from hw.netlist import PARTS
    pico=PARTS["PICO"].pins
    for n in map(str,range(1,41)):
        b = PARTS["J1B"].pins.get(n) or PARTS["J2B"].pins.get(n)
        assert b == pico[n] and b is not None, f"breakout pad {n} not tied to PICO {n}"
```

- [ ] **Step 4:** run → fix until both pass. **Step 5:** commit `"netlist: peripherals + breakout ties + pin-map lock"`.

---

### Task 8: Emit KiCad netlist + connectivity lint

**Files:** Modify `hw/netlist.py` (`emit_netlist`); `hw/checks.py::test_lint`; output `pico2_trace.net`.

- [ ] **Step 1:** `emit_netlist(path)` writes `(export (version "E") (components…) (nets…))` from `PARTS`/`NETS`, skipping `dnp` parts' population but keeping refs.
- [ ] **Step 2: Failing lint**

```python
def test_lint():
    from hw.netlist import PARTS, NETS
    for name,pins in NETS.items():
        assert len(pins) >= 2, f"net {name} has {len(pins)} pin(s)"
    for ref,p in PARTS.items():
        for pad,net in p.pins.items():
            assert net is not None or pad in p.nc, f"{ref}.{pad} unconnected (not in nc)"
```

- [ ] **Step 3:** run → fix (mark true NC: MIPI-20 "6"/"7"/"8", J8 D+/D−). **Step 4:** `python3 -c "import hw.netlist as n; n.emit_netlist('pico2_trace.net')"` then `test $(grep -c '(net ' pico2_trace.net) -gt 30`. **Step 5:** commit `"netlist: emit .net + lint"`.

---

### Task 9: Schematic (ERC-clean, netlist-matched)

**Files:** Create `pico2_trace.kicad_sch` (+ hierarchical sheets).

- [ ] **Step 1 (auto):** if `SCHEMATIC_MODE=auto`, run the venv SKiDL generator (`set_default_tool(KICAD9)`, `KICAD9_SYMBOL_DIR` set) to emit `.kicad_sch`; note it writes `./skidl.kicad_sch` and is flat — move/rename to `pico2_trace.kicad_sch`.
- [ ] **Step 1 (gui):** if `SCHEMATIC_MODE=gui`, draw four hierarchical sheets in eeschema (power / debug_trace / usb / periph) using `sym/pico2_trace.kicad_sym` + stock symbols, following `stemmaqt_shift.sch`, `adafruit_power.lbr`, `adafruit_electromech.lbr`; label nets with exact `NETS` names.
- [ ] **Step 2: ERC** — `kicad-cli sch erc --exit-code-violations pico2_trace.kicad_sch -o /tmp/erc.rpt; echo exit=$?` → report shows 0 errors (intentional-NC warnings OK).
- [ ] **Step 3: Netlist parity (the authoritative cross-check, not pcb schematic-parity)**

```bash
kicad-cli sch export netlist -o /tmp/sch.net pico2_trace.kicad_sch
python3 hw/checks.py --compare-netlists /tmp/sch.net pico2_trace.net   # prints "netlists match" or the diff
```
Expected: `netlists match`.

- [ ] **Step 4:** `kicad-cli sch export pdf -o docs/schematic.pdf pico2_trace.kicad_sch`. **Step 5:** commit `"sch: ERC-clean schematic matched to netlist + PDF"`.

---

### Task 10: PCB — instantiate footprints, nets, net classes, stackup

**Files:** Create `hw/build_board.py`.

- [ ] **Step 1:** `build_board.py`: `b=pcbnew.LoadBoard("pico2_trace.kicad_pcb"); assert b is not None`. For each non-DNP `PARTS` entry: `fp=pcbnew.FootprintLoad(dir, name); fp.SetReference(ref); b.Add(fp)`; create nets via `ni=pcbnew.NETINFO_ITEM(b,net); b.Add(ni)`; `pad.SetNet(...)` per `p.pins`. `b.SetCopperLayerCount(2)`. `pcbnew.SaveBoard(...)`.
- [ ] **Step 2: Net classes (persisted via SaveProject, per BL-4)**

```python
ds = b.GetDesignSettings(); ns = ds.m_NetSettings
def nc(name,w,c):
    k=pcbnew.NETCLASS(name); k.SetTrackWidth(pcbnew.FromMM(w)); k.SetClearance(pcbnew.FromMM(c)); ns.SetNetclass(name,k)
nc("Power",0.5,0.2); nc("Trace",0.3,0.25)
for n in ["GND","VBUS_NET","V5_JTRACE","VSYS","P3V3","HOST_VBUS"]: ns.SetNetclassPatternAssignment(n,"Power")
for n in ["TRACECLK","TD0","TD1","TD2","TD3"]: ns.SetNetclassPatternAssignment(n,"Trace")
pcbnew.SaveBoard("pico2_trace.kicad_pcb", b)
pcbnew.GetSettingsManager().SaveProject()      # <-- required or classes are lost
```

- [ ] **Step 3: Verify**

```bash
python3 hw/build_board.py && python3 - <<'PY'
import pcbnew
b=pcbnew.LoadBoard("pico2_trace.kicad_pcb"); assert b
fps={f.GetReference() for f in b.GetFootprints()}
assert {"PICO","J1B","J3","J5","J9","JP1","SW1","TP1"} <= fps, fps
classes={str(k) for k in b.GetNetClasses()}        # wxString keys (BL-4b)
print("footprints",len(fps),"nets",b.GetNetCount(),"classes",classes)
assert "Trace" in classes and "Power" in classes
PY
```
Expected: footprints present, `GetNetCount()==len(NETS)+1`, classes include Trace+Power. **Step 4:** commit `"pcb: footprints, nets, net classes (persisted), 2-layer stackup"`.

---

### Task 11: PCB — board outline, mounting holes, Pico socket edge

**Files:** Modify `hw/build_board.py` (replace the Task-1 placeholder outline).

- [ ] **Step 1:** Redraw a ~65 × 34 mm `Edge_Cuts` outline (rounded corners); add 4× `MountingHole:MountingHole_3.2mm_M3` footprints (fixes BL-10 — no `AddHole`); place `PICO` with its USB/BOOTSEL end at a board edge (keepout notch so the module clears).
- [ ] **Step 2: Verify outline closed + size**

```bash
python3 - <<'PY'
import pcbnew
b=pcbnew.LoadBoard("pico2_trace.kicad_pcb"); assert b
edges=[d for d in b.GetDrawings() if d.GetLayer()==pcbnew.Edge_Cuts]; assert edges,"no edge cuts"
bb=b.GetBoardEdgesBoundingBox(); print("board mm:", round(pcbnew.ToMM(bb.GetWidth()),1), round(pcbnew.ToMM(bb.GetHeight()),1))
assert {"MH1","MH2","MH3","MH4"} <= {f.GetReference() for f in b.GetFootprints()}
PY
```
Expected: ≈ 65 × 34 mm, 4 mounting holes. **Step 3:** commit `"pcb: outline, mounting holes, Pico socket edge"`.

---

### Task 12: PCB — constrained placement + trace silk

**Files:** Create `hw/place.py`; modify `hw/build_board.py`.

- [ ] **Step 1:** `POS = {ref:(x,y,rot)}`: J3 within 30 mm of PICO trace pins (2/4/5/6/7 side); J4/J6/J7 grouped on that edge; Rt1–Rt5 hard against the socket trace pins; JP2/JP3 flanking; J1B/J2B outboard of each socket row; J5/J8/J9 on the opposite edge (load switch + ESD by J5, TP1–3 at the port); J_STEMMA/J_UART/button/LED on the free edge; JP1 near the power pins.
- [ ] **Step 2: Trace silk (fixes G-4)** — add `PCB_TEXT` "unplug while tracing" on the silk near the GP1–GP5 breakout pads.
- [ ] **Step 3: Apply + verify no courtyard overlaps (JSON report, not stdout grep — fixes BL-2/BL-9)**

```bash
python3 hw/build_board.py --place
kicad-cli pcb drc --format json -o /tmp/drc.json pico2_trace.kicad_pcb >/dev/null 2>&1
python3 -c "import json;v=json.load(open('/tmp/drc.json'))['violations'];c=[x['type'] for x in v if x['type'] in('courtyards_overlap','holes_co_located')];print('placement violations:',c);assert not c"
```
Expected: `placement violations: []`.

- [ ] **Step 4: Verify trace-pin → MIPI-20 span < 30 mm (EuclideanNorm — fixes BL-7)**

```bash
python3 - <<'PY'
import pcbnew
b=pcbnew.LoadBoard("pico2_trace.kicad_pcb"); assert b
def pad(ref,pn):
    f=b.FindFootprintByReference(ref); return next(p.GetPosition() for p in f.Pads() if p.GetNumber()==pn)
d=pcbnew.ToMM((pad("PICO","2")-pad("J3","12")).EuclideanNorm())
print("CLK span mm:", round(d,1)); assert d < 30
PY
```
Expected: span < 30 mm. **Step 5:** commit `"pcb: constrained placement + trace silk"`.

---

### Task 13: PCB — route the SI-critical nets

**Files:** Create `hw/route_trace.py`.

- [ ] **Step 1:** Route TRACECLK+TD0–TD3 as short top-layer `PCB_TRACK` runs socket-pin → Rt → MIPI-20 on the `Trace` class; keep parallel + length-equalized (small trombone if needed). Route SWDIO/SWCLK/NRESET/VTREF to J3+J6. `SaveBoard`.
- [ ] **Step 2: Verify matched + short**

```bash
python3 - <<'PY'
import pcbnew
b=pcbnew.LoadBoard("pico2_trace.kicad_pcb"); assert b
def length(net):
    nc=b.GetNetcodeFromNetname(net)
    return pcbnew.ToMM(sum(t.GetLength() for t in b.GetTracks() if t.GetNetCode()==nc))
L={n:round(length(n),1) for n in ["TRACECLK","TD0","TD1","TD2","TD3"]}
print(L); assert max(L.values())-min(L.values())<3 and all(v<30 for v in L.values())
PY
```
Expected: all < 30 mm, spread < 3 mm. **Step 3:** commit `"pcb: length-matched trace bundle + SWD"`.

---

### Task 14: PCB — route power, USB pairs, guards, and finish bulk nets

**Files:** Modify `hw/route_trace.py`.

- [ ] **Step 1:** Route power nets (Power class, wide); route each USB D± pair tightly coupled GPIO-series-R → ESD → receptacle; tie JP2/JP3 guard pins to `GND`. `SaveBoard`.
- [ ] **Step 2: Interactive finish (the one non-scripted step, done here BEFORE the DRC gate — fixes BL-3 ordering)** — in pcbnew GUI (or Freerouting via exported `.dsn`) route the remaining low-speed peripheral nets (I2C, UART, LED, button, ISENSE) and the breakout rows. Record it in `docs/BRINGUP.md`.
- [ ] **Step 3: Verify unconnected count trends to zero (arg required — fixes BL-8)**

```bash
python3 - <<'PY'
import pcbnew
b=pcbnew.LoadBoard("pico2_trace.kicad_pcb"); assert b; b.BuildConnectivity()
un=b.GetConnectivity().GetUnconnectedCount(False)
print("unconnected pads:", un)
PY
```
Expected: `0` after Step 2 (or a listed remainder you consciously defer). **Step 4:** commit `"pcb: route power, USB pairs, guards; finish bulk nets"`.

---

### Task 15: PCB — bottom ground pour + stitching

**Files:** Modify `hw/route_trace.py`.

- [ ] **Step 1 (fill only on a file-loaded board — fixes FR-1 segfault):**

```python
import pcbnew
b=pcbnew.LoadBoard("pico2_trace.kicad_pcb"); assert b     # MUST be loaded from disk, not in-memory
gnd=b.GetNetcodeFromNetname("GND")
for layer in (pcbnew.B_Cu, pcbnew.F_Cu):
    z=pcbnew.ZONE(b); z.SetLayer(layer); z.SetNet(b.FindNet(gnd))
    z.SetOutline(<board_outline_polygon>); b.Add(z)
# add GND stitching vias in the trace region here
pcbnew.ZONE_FILLER(b).Fill(b.Zones())
pcbnew.SaveBoard("pico2_trace.kicad_pcb", b)
```

- [ ] **Step 2: Verify bottom GND filled**

```bash
python3 - <<'PY'
import pcbnew
b=pcbnew.LoadBoard("pico2_trace.kicad_pcb"); assert b
z=[z for z in b.Zones() if z.GetNetname()=="GND" and z.GetLayer()==pcbnew.B_Cu]
assert z and z[0].GetFilledArea()>0, "bottom GND not filled"
print("bottom GND filled mm2:", round(pcbnew.ToMM(pcbnew.ToMM(z[0].GetFilledArea())),1))  # double-ToMM = area in mm^2
PY
```
Expected: nonzero area. **Step 3:** commit `"pcb: bottom GND pour + stitching vias"`.

---

### Task 16: Full DRC gate (JSON-parsed, error-severity)

**Files:** `hw/checks.py::drc_gate`.

- [ ] **Step 1: Run DRC to JSON and gate in Python (never exit-code/stdout — fixes BL-3/BL-5)**

```bash
kicad-cli pcb drc --format json -o docs/drc.json pico2_trace.kicad_pcb >/dev/null 2>&1
python3 - <<'PY'
import json
v=json.load(open("docs/drc.json"))
errs=[x for x in v["violations"] if x.get("severity")=="error"]
un=v.get("unconnected_items",[])
print("errors:",len(errs),"unconnected:",len(un))
for x in errs[:20]: print(" -",x["type"],x.get("description",""))
assert not errs and not un, "DRC not clean"
print("DRC CLEAN")
PY
```
Expected: `DRC CLEAN`. Warnings are reviewed and either fixed or explicitly waived in `docs/BRINGUP.md`; **parity is advisory** (Task 9's netlist compare is the real check).

- [ ] **Step 2:** fix any errors in `place.py`/`route_trace.py`, re-run. **Step 3:** commit `"pcb: DRC clean"`.

---

### Task 17: Fabrication outputs, BOM, 3D render, bring-up note

**Files:** `docs/BOM.csv`, `docs/BRINGUP.md`, `fab/*`, `docs/board.png`.

- [ ] **Step 1: Gerbers + drill + position**

```bash
kicad-cli pcb export gerbers -o fab/ pico2_trace.kicad_pcb
kicad-cli pcb export drill   -o fab/ pico2_trace.kicad_pcb
kicad-cli pcb export pos -o fab/pos.csv --format csv --units mm pico2_trace.kicad_pcb
```
Expected: `fab/` has `.gbr`/`.drl`/`pos.csv`.

- [ ] **Step 2: BOM** — `kicad-cli sch export bom -o docs/BOM.csv pico2_trace.kicad_sch` (auto mode) or generate from `PARTS` (gui mode); mark DNP parts DNP.
- [ ] **Step 3: 3D render** — `kicad-cli pcb render -o docs/board.png --side top --quality high pico2_trace.kicad_pcb`
- [ ] **Step 4: Bring-up note** — write `docs/BRINGUP.md`: `## Toolchain` (Task-1 result), power-up order, JP1–JP4 defaults, the §9 native-VBUS-detect test recipe, the trace validation ladder (`DESIGN.md` §13), and the Task-14 interactive-routing record.
- [ ] **Step 5:** archive `docs/schematic.pdf` + `docs/BRINGUP.md` to the calibre library. **Step 6:** commit `"fab: gerbers, drill, pos, BOM, 3D render, bring-up note"`.

---

## Self-review notes (author)

- **Review fixes folded in:** BL-1 (PICO=Module footprint, no separate inner sockets) · BL-2/BL-9 (DRC via parsed JSON, not stdout grep / bad flag) · BL-3/BL-5 (DRC gate = JSON error-severity + unconnected, interactive finish before the gate, placeholder outline) · BL-4 (`SaveProject()` + `{str(k) …}`) · BL-6/FR-3 (SKiDL spike uses `kinet2pcb`/`kinparse`, `KICAD9`, actually calls `generate_schematic`) · BL-7 (`EuclideanNorm`) · BL-8 (`GetUnconnectedCount(False)`) · BL-10 (MountingHole footprints) · FR-1 (fill only on file-loaded board) · FR-4 (helpers defined in Task 3, consistent signatures) · FR-6 (`hw/__init__.py`). Gaps: G-1 (breakout ties, Task 7 Step 2) · G-2 (pins 35/37) · G-3 (probe TPs) · G-4 (trace silk) · G-5 (D+ gate FET fp) · G-6 (J_UART/J_STEMMA refs) · G-7 (DNP parts enumerated).
- **Spec coverage:** §3→T2/11/12, §4→T2/3, §5→T5/13, §6→T7, §7→T4/14, §8→T6/14, §9→T6, §10→T7/14, §11 BSP→BRINGUP (firmware, out of PCB scope), §12→T17, §13→BRINGUP, §14→T3 (DNP parts).
- **Known non-automated steps:** Task 14 Step 2 (bulk low-speed routing) and, if the Task-1 spike fails, Task 9 gui schematic draw — both flagged; all SI-critical work is scripted and verified first.

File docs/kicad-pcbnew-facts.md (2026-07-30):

# KiCad 9.0.2 scripting — verified facts (obey these)

Hard-won on pico2_trace_motherboard (2026-07); every item was hit for real.
Re-verify only if the KiCad version changes.

## pcbnew API landmines

- `pcbnew.SaveBoard` does **not** persist net classes (they live in
  `.kicad_pro`) — after setting them call
  `pcbnew.GetSettingsManager().SaveProject()`.
- `ZONE_FILLER(b).Fill()` **segfaults on an in-memory-mutated board** — only
  fill a board freshly `LoadBoard`-ed from disk, in its own process.
- `BOARD.Remove()` on a populated board corrupts it — design scripts to be
  idempotent (skip-if-present) instead of removing and re-adding.
- `VECTOR2I.Distance()` raises `TypeError`; use `(p1 - p2).EuclideanNorm()`.
- `GetUnconnectedCount(False)` requires the arg.
- `pcbnew.AddHole` does not exist — use `MountingHole` footprints.
- `b.GetNetClasses()` iterates **wxString keys**:
  `{str(k) for k in b.GetNetClasses()}`.
- `LoadBoard` returns `None` (no raise) on a bad path — assert non-None.
- `PCB_VIA.GetWidth()` needs a layer argument in v9.
- Board-level silk text is not exposed as `PCB_TEXT` via SWIG in all paths —
  parse `gr_text` from the file when auditing silk.
- Footprint rotation: for 0402 passives, rot 90 puts pad 1 **south**,
  rot 270 puts it **north** (probe, never assume).

## kicad-cli

- `pcb drc --exit-code-violations` returns **exit 5** on *any* violation
  including warnings, `unconnected_items`, and the empty-board
  `invalid_outline`. Gate on a **parsed `--format json` report**, never exit
  codes or stdout text.
- `--schematic-parity` is a bare boolean flag and needs footprint↔symbol
  UUID links that scripted footprints don't have — treat as advisory; rely
  on a netlist compare instead.
- Gerber export emits drawing items in container order — a regenerated
  board produces textual gerber diffs with identical geometry. Compare
  semantically (`tools/board_semantic_compare.py`), not textually.

## Stock footprint facts

- `Module:RaspberryPi_Pico_Common_THT` = the inner-socket land pattern, 40
  THT pads numbered "1"–"40" by physical pin. Do not add separate inner
  sockets on top of it.
- `PinSocket_1x20_P2.54mm_Vertical` (and the PinHeader THT families) anchor
  at **pin 1**; the `_SMD_Pin1Left` variants anchor at the row centre —
  re-derive placement when switching.
- Schematic generators keyed to numeric pads require local renumbered
  copies of any stock footprint with alphanumeric pads (USB-C `A1..B12`,
  etc.) — see `lib/pcb.pretty/` for audited examples.

## WebGL / browser caveats (JLC viewers)

- Heavy WebGL pages stall CDP `Page.captureScreenshot`; canvas
  `toDataURL` returns black without `preserveDrawingBuffer`. Verify
  placement in a visible window or via JLC's Confirm-Parts-Placement
  service.

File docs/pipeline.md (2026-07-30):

# Netlist-driven KiCad pipeline — how to start the next board

The reference implementation is `pico2_trace_motherboard/hw/` (proven: the
board regenerates from an empty file byte-equivalently, survived a
three-reviewer pre-order audit, and shipped as JLC W2026073018593887).

## Architecture

One Python model drives everything:

```
hw/netlist.py     PARTS (Part dataclass: ref/value/fp_class/pins/nc/dnp/padmap)
                  + net assignments + graph helpers (series_between,
                  divider_ratio, net_pins) + emit_netlist() -> .net
hw/fp_lib.py      part class -> (library, footprint) resolution table
hw/build_board.py pcbnew driver: footprints, net wiring (per-pad assert),
                  outline, mounting holes, netclasses (+ SaveProject!)
hw/place.py       placement coordinate table + silk labels
hw/route_trace.py probe-based routing (helpers: _pad/_pos/_add_track/
                  _add_via/_add_path_once/_track_exists)
hw/pour.py        GND zones both layers + stitching vias; fill in own process
hw/gen_sch.py     schematic generator (generic N-pin symbols, ERC-clean)
                  -- REQUIRES numeric pad names everywhere
hw/checks.py      pytest gates + --compare-netlists (semantic differ)
```

## Bootstrapping board #2

1. `mkdir <board> && cd <board> && git init`; copy `hw/` wholesale from
   pico2_trace_motherboard plus `fp-lib-table`, `sym-lib-table`,
   `.gitignore`, `tools/align_md_tables.py`.
2. Gut the board-specific content: PARTS/net tables in `netlist.py`, the
   POS/FUNC_LABELS tables in `place.py`, every routing function in
   `route_trace.py` below the helper layer, the via lists in `pour.py`,
   the assertions in `checks.py`.
3. Keep: all helpers, the pipeline `main()`s, the gate structure,
   `gen_sch.py` untouched.
4. Shared audited footprints: point `fp-lib-table` at a local `.pretty`
   seeded from `~/code/pcb/lib/pcb.pretty/` (copy, keep the board
   self-contained).
5. Regenerate loop (identical for every board):

```bash
rm <board>.kicad_pcb && python3 -c "import pcbnew; pcbnew.SaveBoard('<board>.kicad_pcb', pcbnew.NewBoard('<board>.kicad_pcb'))"
python3 hw/build_board.py --place
python3 hw/route_trace.py
python3 hw/pour.py && python3 hw/pour.py --fill
```

## Gate battery (run after every change)

1. DRC: `kicad-cli pcb drc --format json` → parse JSON; record the board's
   own warning baseline explicitly; unconnected must be 0.
2. `python3 -m pytest hw/checks.py -q` — put net-level regression guards
   here (e.g. `series_between("J8_CC1","GND","R_CC1")`).
3. Netlist parity: `emit_netlist()` + `python3 -m hw.gen_sch` +
   `kicad-cli sch export netlist` + `hw/checks.py --compare-netlists`.
4. GND-pour union-find: ring-sampled (radius+0.45mm) over vias + tracks +
   pads edge classes; must be exactly 1 component. Centre-point sampling
   false-negatives on thermal gaps — always ring-sample.
5. Regen-equivalence when refactoring scripts:
   `python3 ~/code/pcb/tools/board_semantic_compare.py old.kicad_pcb new.kicad_pcb`
   → must print IDENTICAL.

## Non-negotiables learned the expensive way

- Regenerate, never hand-nudge: any hand edit dies on the next regen.
- Read `docs/kicad-pcbnew-facts.md` before writing any pcbnew script.
- Probe pad positions in routing code (`_pos(_pad(...))`) — never
  hardcode a pad position that the footprint defines.
- Multi-pad numbers (shield legs, stacked USB-C contacts) are legal and
  useful; `_pad()` returns the first match — select deterministically
  when it matters.
- Before ordering: adversarial multi-agent review of (a) footprint pad
  maps vs datasheet, (b) live-board pad→net dump, (c) BOM/CPL/gerber
  package freshness. Template: pico2_trace_motherboard commit `0218f22`'s
  audit. The user clicks Pay.

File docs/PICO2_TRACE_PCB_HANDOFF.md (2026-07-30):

# Handoff: Pico 2 SWD + ETM-Trace Adapter PCB

Design a small PCB that a Raspberry Pi Pico 2 plugs into (or that plugs onto a
Pico 2) and presents a single ARM Cortex **Debug+ETM MIPI-20** connector
(Samtec FTSH-110, 0.05") carrying SWD + 4-bit parallel trace to a SEGGER
J-Trace. It replaces a fly-wire rig whose measured limits are documented
below — every number in this handoff was obtained on real hardware
(J-Trace PRO Cortex-M **V2**, nickname `jtrace`, Pico 2, TinyUSB cdc_msc).

## Why

Fly-wires cap the usable trace clock far below the chip's capability and
degrade with every handling cycle. Community consensus (Raspberry Pi forum
t=383655) and SEGGER's Pico 2 KB page agree: full-rate RP2350 trace needs a
proper trace board. SEGGER also state RP2350 streaming trace requires
**J-Trace PRO V3.0+**; our V2 measurements below are consistent with that.

## Electrical map (validated end-to-end on this rig)

RP2350 trace is **fixed** to these GPIOs (funcsel 9, bank 0 — no alternatives):

| Signal | RP2350 GPIO | Pico 2 40-pin header pin | MIPI-20 pin |
|---|---|---|---|
| TRACECLK | GPIO1 | 2 | 12 |
| TRACEDATA0  | GPIO2 | 4 | 14 |
| TRACEDATA1  | GPIO3 | 5 | 16 |
| TRACEDATA2  | GPIO4 | 6 | 18 |
| TRACEDATA3  | GPIO5 | 7 | 20 |
| SWDIO | dedicated | 3-pin JST-SH DEBUG conn (center-right) | 2 |
| SWCLK | dedicated | 3-pin JST-SH DEBUG conn  | 4 |
| nRESET | RUN | 30 | 10 |
| VTref 3V3 | 3V3_OUT | 36 | 1 |
| GND | any GND | 3, 8, 13, 18, 23, 28, 38 | 3,5,9,11,13,15,17,19 |
| SWO | — none on RP2350 — leave MIPI-20 pin 6 NC | | 6 (NC) |

- MIPI-20 pin 7 is the connector key (NC), pin 8 NC (no TDI).
- **Route nRESET**: the bring-up relied on hardware pin reset (RESETPIN) to
  recover from states SYSRESETREQ cannot; J-Trace must be able to yank RUN.
- SWD comes from the Pico 2's JST-SH DEBUG connector (SWCLK/GND/SWDIO) — a
  JST-SH-3 footprint + short cable, or pogo pins, or solder pads. Do NOT
  share the trace ground return path exclusively; give SWD its own ground.

## Signal-integrity requirements (from measured failures)

Trace port is **DDR**: data on both edges of TRACECLK = clk_sys/2 (datasheet:
"the TPIU is a DDR output at half of clk_sys"). At the 150 MHz default that
is 75 MHz TRACECLK, 150 Mtransfer/s per pin, ~600 Mb/s total on 4 bits.

Measured on fly-wires (what the PCB must beat):

| TRACECLK | Result on fly-wires |
|---|---|
| 24 MHz (48 MHz core) | solid, any seating, full-width dense data |
| 30–36 MHz (60–72 core) | seating lottery: one seating did 72 5/5, the next failed |
| 40 MHz (80 core) | idle code only; dense data dies (width 4). Width 1 passes dense |
| 42+ MHz (84+ core) | dead at any sample timing (±6 ns global AND per-pin), any pad drive (2–12 mA, slow/fast slew), any width, any SWD speed — instant decode failure |

Failure modes to design against:
1. **Transition-density sensitivity**: deaths correlate with the USB
   enumeration burst (max data-line switching). One weak line (D1 in our
   rig, twice) drags the whole port down; per-line quality matters.
2. **Crosstalk/ground-return**: unshielded bundle without interleaved
   grounds was the core defect. The MIPI-20's alternating ground pins must
   be honored with a solid plane and short return loops.
3. **Edge rate**: J-Link programs the trace pads to 0x56 = 4 mA, slow slew,
   schmitt, pull-down, IE — and re-programs them at **every resume**, so the
   PCB must work with 4 mA/slow drive into its load. Do not design for a
   boosted drive; firmware pad overrides get overwritten mid-session.

Layout guidance (designer to verify): 50 Ω single-ended microstrip over a
continuous ground plane; series termination (~22–33 Ω, placed at the RP2350
end — i.e., as close to the Pico 2 header pins as the adapter can get) on
TRACECLK and D0–D3; length-match CLK vs data within a few mm (UI at 75 MHz
DDR is 6.7 ns — generous, but the fly-wire experience says don't spend the
margin); no stubs (the Pico 2 header pin itself is already a stub — keep
adapter traces minimal); keep the MIPI-20 within ~3 cm of the header.
SEGGER's own Pico 2 flywire guide and their trace-adapter reference designs
are the prior art to check.

## Probe constraints — set expectations

- **J-Trace PRO V2 (current rig)**: hard cliff just above 40 MHz TRACECLK
  regardless of signal quality levers we could test. On a clean PCB, expect
  reliable **width-4 dense-data at 40 MHz TRACECLK (80 MHz core)** — the PCB
  removes the seating lottery and the per-line weakness, not the cliff.
- **J-Trace PRO V3+** (SEGGER-required for RP2350 streaming): design target
  is full **75 MHz TRACECLK / 150 MHz core** (and the chip is commonly
  overclocked to 180 → 90 MHz TRACECLK; leave SI margin for it).
- SWD verified fine at 25 MHz (and 50 MHz) on the current rig; the PCB
  should treat 50 MHz SWD as routine.

## Firmware/BSP interface (already in the TinyUSB branch `claude/add-etm-trace-skill`)

- `-DTRACE_ETM=1` builds pin clk_sys via `board.cmake`
  (`hw/bsp/rp2040/boards/raspberry_pi_pico2/board.cmake`) — currently 48 MHz
  (fly-wire-safe). With the PCB, bump to 80 MHz on V2 (`SYS_CLK_KHZ=80000`,
  VCO 1440 MHz, postdiv 6/3) or 150 MHz on V3 (drop the block entirely).
  The clock must be pinned **from crt0** — any clock change after trace
  arms desyncs the decoder mid-stream.
- J-Link's **built-in** RP2350 script owns all chip-side trace config
  (ETM/funnel/TPIU/pin mux + pads) and re-arms at every resume. Never use a
  custom JLinkScript on RP2350 (it silently replaces the built-in one →
  "Required trace components for pin trace not found", zero trace).
- Firmware does only two things under TRACE_ETM (`hw/bsp/rp2040/family.c`):
  clears TIMER0/1 DBGPAUSE (else sleep_ms hangs after debug sessions) and
  keeps the UART console TX-only (GPIO1 = default UART0 RX = TRACECLK; the
  PCB must likewise not route GPIO1 to anything).
- GPIO1–5 must be completely free on the adapter: no pull resistors, no
  LEDs, no test-point loading beyond a via.

## Validation plan (run on this rig, ~30 min)

Tools already in the repo (`.claude/skills/etm-trace/`, use the skill):

1. Continuity + SEGGER demo sanity: `~/code/jtrace/RaspBerryPi_RP2350_M33_0_TraceExample`.
2. Ladder: idle counting-loop blinky at 48 → 80 (→ 120/150 if V3), one
   capture each: `etm_capture.py --board raspberry_pi_pico2 --probe jtrace
   --elf <blinky> --core-clock <N>`.
3. Dense data: TRACE_ETM cdc_msc ×3 at each passing rung (USB enumeration
   burst is the killer test; `lsusb -d cafe:` must stay up).
4. Wire/line bisect if anything fails: `--trace-width 1` (CLK+D0) vs `2` vs
   `4` isolates a bad line; per-line deskew exists via
   `--trace-timing d0,d1,d2,d3` (ps).
5. Accept: 3/3 default-flag captures with full totals at the target clock,
   then update `board.cmake` + `ozone/rp2350.jdebug` (VAR_TRACE_CORE_CLOCK)
   + the SKILL.md board table row together — they must agree.

## Deliverables

- Schematic + layout (KiCad preferred; schematics land in the calibre
  library when done), BOM, and a one-page bring-up note.
- Form factor decision (ask the user): (a) socket carrier the Pico 2 plugs
  into (two 1×20 female headers), (b) shield that plugs onto a
  male-pinned Pico 2, or (c) castellated-solder daughterboard. Keep the
  Pico 2's USB connector and BOOTSEL button accessible — the recovery flow
  (J-Link erase → BOOTSEL 2e8a:000f → picotool) depends on both.
- Optional extras worth asking about: JST-SH DEBUG passthrough, RUN button,
  a 100 mil test header on the five trace nets (unloaded — DNP by default).

## Reference material

- RP2350 datasheet (calibre library): TPIU DDR statement, funcsel 9 table,
  pads (0x56 decode: IE|4mA|schmitt|PDE|slow).
- SEGGER KB "Raspberry Pi Pico 2": V3.0+ requirement, "proper trace board".
- Forum thread forums.raspberrypi.com t=383655: community fly-wire failures
  at 75 MHz, pad-drive tuning advice, Digilent capture attempts.
- github.com/czietz/etm-trace-rp2350: DMA-based capture alternative (no
  pins) — useful cross-check that ETM config itself is sane.
- TinyUSB branch `claude/add-etm-trace-skill` (LOCAL): commits 11a4dd11d,
  d2df67187, f1b89b5b3, 55f5948eb, 01aa79c00 tell the full story; SKILL.md
  board note has the condensed lessons.

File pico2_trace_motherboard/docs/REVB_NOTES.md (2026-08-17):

# REV B — change log and open items

**REV A is the fabricated hardware** (JLCPCB `W2026073018593887`, 2026-07-30,
5 PCB / 2 assembled). Those boards are on the bench and match git tag
**`rev-a-pico2`**. The working tree has since advanced to REV B, which has
**not been ordered**. The silkscreen revision string tracks this
(`hw/place.py: BOARD_REV_TEXT`), so the two are never confusable in hand.

## Fixed in REV B

### J5 USB-A mouth was 6.61 mm inboard of the board edge

Found on the REV A hardware at bring-up. The receptacle opening sat 6.61 mm
inside the x=92 edge (F.Fab east 85.39), leaving a ledge of bare board in
front of it, so a cable's overmold fouls before the plug seats. Only pour
and two stitching vias occupied that strip, so REV A boards can be rescued
by filing a notch from x≈85.4 to the edge across y≈11–29 (no signals, no
mounting holes there — MH2 is at y=4, J9 at y=40–50).

Root cause: J5's anchor was derived from its **pad rows** (to line up with
the R_HDP/R_HDM/TP/ESD_H chain at y=19.0/21.0) and the mouth-to-edge
dimension was never asserted. J8 and J9 were placed with explicit flush-lip
arithmetic; J5 predated that convention. Nothing caught it: DRC has no such
rule, and the pre-order checklist's "openings must face off the board edge"
was a human eyeball on the fab's render.

Fix: anchor `78.615 → 85.225` (its own anchor→F.Fab-east offset is 6.775,
so 92.00 − 6.775). Mouth now lands exactly at 92.00. The change is
surgical — semantic diff vs `rev-a-pico2` shows **only**: J5 moved, 7
tracks re-routed on HOST_DP/HOST_DM/HOST_VBUS, one GND stitching via
relocated (78.0,22.0)→(75.0,26.0) because J5's HOST_DM pad landed 1.0 mm
from it, and the REV silk string.

Regression guard added: `hw/checks.py::test_edge_connector_mouths` asserts
every edge-facing receptacle's F.Fab mouth is within 1.0 mm of its board
edge. Verified non-vacuous — it fires on REV A's J5 (6.61 mm) and passes
J8/J9 (0.45 mm each).

## Cost reduction for the next order — where the money actually is

Board **area is not a lever**: JLC's 2-layer prototype price is one flat
tier up to 100 × 100 mm, and 92 × 64 mm sits inside it. The REV A invoice
line was `PCB $2.00` for 5 pieces, with `Panel: $0.00` and
`Large Size: $0.00`. Shrinking the outline saves exactly $0.

The real drivers, from the REV A quote (PCBA $79.47 of the $81.27 total):

| Line item | REV A  | Lever |
| --- | --- | --- |
| Extended components fee | $42.98 | ~15 Extended lines × ~$3 — swap lines to Basic |
| Components (26 items, ×2)  | $17.65 | scales with assembly qty |
| Setup + stencil | $9.71  | fixed per order — amortize over more boards |
| Hand-solder + manual (THT) | $7.01  | fixed once any THT line is assembled |

**Biggest lever — assemble 5 instead of 2.** The setup, stencil and the
whole $42.98 Extended fee are charged *per order*, not per board. Quoted
during the REV A session: qty 2 = $82.17 ($41.09/board), qty 5 = $105.43
($21.09/board). Nearly half the per-board cost for 28% more money.

**Second lever — Extended → Basic swaps.** Candidates to re-check on the
live parts page at order time (tiers drift; verify, don't assume):

| Line | Current | Note |
| --- | --- | --- |
| 27R 0402 (RT1–RT5) | C25100 | plain E24 value — a Basic 0402 27R is likely available |
| 8.2k 0402 (VBUS dividers) | C413094 | Basic C25924 was industry-dry at REV A time; re-check  |
| LED green 0603 | C12624 | JLC stocks Basic 0603 LEDs; hue may differ |
| 1x20 socket / headers | C124410 / C124376 / C124375 | check Basic THT equivalents with identical land |

Do **not** chase these: the 0.1 Ω 1206 shunt (C844896 — tolerance feeds
current-sense accuracy), the B3S-1000 button (C2733655 — land-pattern
specific), and the ICs/connectors (USBLC6, INA180, TPS2051B, USB-C, USB-A,
JST-SH, 1.27 mm headers), which have no Basic equivalents.

## Open advisories (from the pre-order audit, not defects)

- **DEV_DP bridge asymmetry** — J9's D+ orientation bridge is ~6.3 mm over
  two vias on B.Cu while D− is a ~3.1 mm F.Cu rail, because the Type-C
  D+/D− pad pairs interleave. Irrelevant at PIO-USB full speed; would
  matter at 480 Mbps.
- **VBUS_NET necks to 0.2 mm for 3.4 mm at J8** — forced by the 0.25 mm gap
  to the adjacent netless pad. Fine below ~1.5 A; widen the B.Cu side or
  add a parallel via if the bench load grows.
- **J8/J9 mouths sit 0.45 mm inside their edges** (the connector body, not
  the courtyard, is what's flush). No problem observed on REV A hardware;
  the new guard's 1.0 mm tolerance accepts it deliberately.
- **`PICO1`/`PICO2` exist only in the BOM/CPL**, not on the board or silk —
  they are the two halves of the single `PICO` socket footprint, split so
  JLC assembles both 1×20 rows. An assembler cannot locate them by silk.
  Consider real per-row footprints in a future revision.
- **U_INA219_ALT, D_J9_BUSPWR, C_NRESET are DNP by design** and correctly
  absent from the JLC BOM. The empty footprints on REV A hardware are
  expected, not assembly errors. Host current sensing runs through the
  populated R_SHUNT → U_ISNS (INA180A1, ×20) → GP26 path, scale 2.0 V/A.

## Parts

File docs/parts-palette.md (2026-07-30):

# Verified parts palette (LCSC / JLCPCB)

Every part below was sourced, tier-checked, and assembled (or explicitly
audited) for pico2_trace_motherboard, JLC order W2026073018593887
(2026-07-30). Stock and tier drift — the live parts page arbitrates — but
these are proven starting points. Basic tier = no per-line loading fee;
Extended ≈ $3/line.

## Connectors

| Part | LCSC | Tier  | Notes |
| --- | --- | ----- | --- |
| USB Type-C 16P receptacle | C165948 | Basic | HRO TYPE-C-31-M-12; audited lands in `lib/pcb.pretty/` (PWR + DEV renumbers); 5A across paralleled VBUS beams |
| USB-A receptacle (host) | C6307429 | Ext | GCT USB1046, SMD signals + 2 THT posts |
| JST-SH 3-pin horizontal | C160403 | Ext | debug-probe jack (SM03B-SRSS-TB) |
| JST-SH 4-pin horizontal | C51940130 | Ext | STEMMA-QT (XYECONN clone, measured fit); C160404 = JST genuine alt |
| 2x10 1.27mm bare header | C41360882 | Ext | XUNPU, measured fit for FTSH-110 land (MIPI-20); Samtec C20728453 +$16 |
| 2x5 1.27mm bare header | C3975188 | Ext | HCTL, measured fit for FTSH-105 land; Samtec C448647 +$7 |
| 1x20 socket 2.54 THT | C124410 | Ext | Ckmtw B-2200S20P; carrier sockets |
| 1x03 / 1x02 header THT | C124376 / C124375 | Ext | Ckmtw jumper/UART/SWD headers |

## ICs

| Part | LCSC | Tier | Notes |
| --- | --- | ---- | --- |
| TPS2051B load switch | C24593  | Ext  | host VBUS switching, active-high EN, FLG |
| INA180A1 sense amp | C122228 | Ext  | 20V/V, with 0.1Ω 1206 shunt C844896 |
| USBLC6-2SC6 ESD | C7519 | Ext  | ST genuine; UMW clone C2687116 (pin1 unverified) |

## Passives / misc (0402 unless noted)

| Value | LCSC | Tier  | Notes |
| --- | --- | ----- | --- |
| 100n 16V | C1525 | Basic | C307331 Samsung 50V alt |
| 22u 0805 | C45783 | Basic | |
| 22R | C25092 | Basic | USB series |
| 27R | C25100 | Ext | trace source-series |
| 1k / 1.5k | C11702 / C25867 | Basic | |
| 5.1k | C25905 | Basic | Type-C CC Rd (±10% allowed by spec) |
| 8.2k | C413094 | Ext | Panasonic; Basic C25924 was industry-dry |
| 15k / 100k | C25756 / C25741 | Basic | |
| LED 0603 green | C12624 | Ext | C2289 = yellow-green hue alt |
| B3S-1000 button | C2733655 | Ext | C180420 = same part, other packaging |
| B5819W schottky SOD-123 | C8598 | Basic | diode-OR feeds |
| 1N4148W SOD-123 | — | — | DNP bus-power option slot |

## JLC fee behavior (proven 2026-07-30)

- Deselecting a matched BOM line does NOT remove its Extended loading fee.
- ANY THT line present brings back the hand-solder (~$3.6) + manual
  assembly (~$2.6-3.4) block — partial THT deselection saves almost
  nothing once one THT line is in.
- Economic PCBA requires green solder mask (red had no compatible
  material type).
- PCBA qty 2 vs 5 is chosen in the assembly form / cart, not the PCB qty.

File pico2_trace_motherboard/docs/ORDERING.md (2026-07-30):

# JLCPCB Ordering Guide — Pico 2 Trace Motherboard REV A

Full assembly (SMT + through-hole). Board revision: see `fab/MANIFEST.txt`
(authoritative source rev + zip sha256 — the Type-C swaps of 2026-07-30
superseded the original `6d67559` freeze). The three upload files are staged
in `~/Desktop/jlcpcb-order/` and live in the repo at
`fab/pico2_trace_gerbers.zip`, `docs/BOM_jlc.csv`, `docs/CPL_jlc.csv`.

## 1. PCB quote

1. jlcpcb.com → **Order now** → drag `pico2_trace_gerbers.zip` onto the upload box.
2. Wait for the preview render, then confirm it detected: **2 layers, 92 × 64 mm**,
   rounded-rect outline, 4 mounting holes.
3. Settings (everything not listed stays default):

| Setting | Value | Note |
| --- | --- | --- |
| Base material | FR-4 | |
| Layers | 2 | auto |
| PCB Qty | 5 | minimum/cheapest tier |
| Thickness | **1.6 mm** | design assumes it |
| Outer copper weight | **1 oz** | trace ampacity was computed for 1 oz |
| Surface finish | HASL (lead-free) | ENIG optional, cosmetic |
| Via covering | Tented | |
| Solder mask / silk  | any colour | green ships fastest |
| Remove order number | "Specify location" is free | or pay to remove |

## 2. PCB Assembly

1. Toggle **PCB Assembly**. Assembly side = **Top** (all 55 placements are top-side).
   Assembly qty **2 or 5** (2 = JLC minimum, halves part cost; 5 = all boards).
   If the UI distinguishes Economic vs Standard: these THT parts are listed by
   JLC as wave-solder compatible under both — accept whatever it selects, the
   live price is authoritative.
2. Next page → upload **BOM** = `BOM_jlc.csv`, **CPL** = `CPL_jlc.csv`.
3. **Parts matching page** — all 28 lines carry verified LCSC numbers and
   should auto-match. Check these specifically:
   - **Low-stock risks** (numbers seen at lookup, 2026-07-29): J_STEMMA
     `C160404` (~59), J5 GCT USB-A `C6307429` (~54). If any shows
     out-of-stock:
     deselect that line and hand-solder it later, or use JLC **Global
     Sourcing** for it.
   - J3/J6 are **genuine Samtec** (`C20728453` / `C448647`, ~$5–8 ea). A cheap
     1.27 mm SMD keyed clone is acceptable ONLY if its drawing checks out:
     SMD termination (not THT), body small enough for the 0.67–0.70 mm
     neighbour gaps, keyed shroud.
   - ~20 Extended lines ⇒ ~$3/reel one-time setup ≈ $60. To trim, deselect
     connector lines and hand-solder those (each deselect saves $3 + part cost).
4. **Component placement preview — the critical screen.** JLC's rotation
   conventions differ from KiCad's; their preview is authoritative. Verify
   against `docs/board renders` / the repo renders:
   - `U_HSW`, `U_ISNS` (SOT-23-5), `ESD_H`, `ESD_D` (SOT-23-6): pin-1 corner.
   - `D_VSYS`, `D_J9_BUSPWR` (SOD-123): **cathode bar must match the silk bar**.
     D_VSYS cathode faces VSYS (toward the Pico row); D_J9_BUSPWR cathode
     faces VBUS_NET (away from J9).
   - `LED_PWR`, `LED_USER` (0603): cathode toward its GND resistor side.
   - `J5`/`J8`/`J9` receptacles: openings must face OFF the board edge.
   - `PICO1`/`PICO2`/`J1B`/`J2B` sockets and all pin headers: symmetric,
     rotation mechanically harmless — just confirm they sit ON their rows.
   Rotate anything wrong in their editor (it saves per-order).
5. Solder-paste/stencil and other assembly defaults: accept.

## 3. Checkout

- Review the order summary: bare-PCB ≈ $2–5, assembly fee + parts + Extended
  setup fees on top; shipping choice is yours.
- Save to cart → **you** click Buy/Pay.

## 4. Order separately (not assembly items)

| Item | Note |
| --- | --- |
| 4× jumper shunts, 2.54 mm | JP1–JP4 (fit JP2/JP3/JP4 by default; JP1 to taste) |
| JST-SH cable | JST-SH→dupont (for J10) or JST-SH→JST-SH (for J7); ships with RPi Debug Probe |
| M3 screws/standoffs ×4 | MH1–MH4 |

Assembly-config history (2026-07-29/30 order sessions): deselecting ALL THT
header lines cut the Economic PCBA quote $82.17 → $71.63 per 2 boards (parts
−$3.53, hand-solder labor −$3.58, manual assembly −$3.43; lead time 2-3 d →
1-2 d; the $42.98 Extended-parts fee did NOT change — JLC charges it on
matched lines regardless of deselection). Interim config had sockets in
and pin headers out ($83.27); final user decision: **EVERYTHING assembled**
(headers-out saved only ~$1.4 once the sockets' labor fees were back — "not
worthy"). With both Type-C swaps the full-assembly PCBA landed at **$79.47**
per 2 boards, cheaper than the original all-micro-B config ($82.17).

All are LCSC items too — add to the same cart to combine shipping.

## 5. After ordering

- Ordered 2026-07-30: **W2026073018593887** (Y14, 5 PCB / 2 assembled,
  $81.27) — recorded in `fab/MANIFEST.txt`.
- On arrival: `docs/BRINGUP.md` — first-power checklist, jumper table, then
  the trace bring-up ladder (48 → 80 → 120 → 150 MHz core).

## 6. Order-time part decisions (stock fluctuates — the live parts page arbitrates)

BOM primaries are the preferred parts. If the parts page shows a primary
out-of-stock, search the fallback (magnifier icon on that row). Prefer
primary whenever both are buyable.

| Line | Primary (preferred) | Fallback (verified) | Rule |
| --- | --- | --- | --- |
| J3 2x10 1.27mm | C41360882 XUNPU (measured fit) | C20728453 Samtec (+$16) | primary; Samtec only if XUNPU dry (360) |
| J6 2x5 1.27mm | C3975188 HCTL (measured fit) | C448647 Samtec (+$7) | primary |
| 100n 0402 | C1525 (Basic) | C307331 Samsung 50V (Basic) | either |
| 22u 0805 | C45783 (Basic) | C6119898 HRE (Ext) | primary if buyable |
| 22R 0402 | C25092 (Basic) | C114765 Yageo (Ext) | primary if buyable |
| 1.5k 0402 | C25867 (Basic) | C114759 Yageo (Ext) | primary if buyable |
| 15k 0402 | C25756 (Basic) | C114761 Yageo (Ext) | primary if buyable |
| 100k 0402 | C25741 (Basic) | C60491 Yageo (Ext) | primary if buyable |
| 1k 0402 | C11702 (Basic) | C106235 Yageo (Ext) | primary if buyable |
| 8.2k 0402 | C413094 Panasonic (Ext) | C25924 (Basic, if recovered) | fallback preferred if back in stock |
| ESD SOT-23-6 | C7519 ST genuine (Ext) | C2687116 UMW clone (Ext, pin-1 unverified) | primary |
| LED 0603 green | C12624 (Ext) | C2289 yellow-green (Ext, hue differs) | primary |
| Buttons B3S-1000 | C2733655 Omron (Ext) | C180420 Omron B3S-1000P (same land) | either (same part, diff packaging) |
| 1x03 header | C124376 Ckmtw (Ext) | C49257 BOOMELE (Ext) | either |
| 1x20 socket x4 | C124410 Ckmtw (Ext) | C2905423 Kinghelm 8.5mm (Ext) | either |
| Type-C J8/J9 | C165948 HRO (Basic, measured)  | any TYPE-C-31-M-12-land clone | primary (both ports since 2026-07-30) |
| STEMMA | C51940130 XYECONN (measured) | C160404 JST genuine (if recovered) | either; genuine preferred if buyable |

## 7. Live-session substitutions (2nd parts-page snapshot, 11 flagged rows)

The UI's part picker (magnifier per row) shows live warehouse stock inline —
it outranks every external lookup. Universal escape: DESELECT the row and
hand-solder that part (recommended outright for J8/J9 — no verified clone).

| Flagged row | Take in picker |
| --- | --- |
| 100n C1525 | C307331 (Samsung 50V, Basic) or any 0402 X7R 100n |
| 22R C25092 | C114765 Yageo |
| 15k C25756 | C114761 Yageo |
| 1k C11702 | C106235 Yageo |
| 8.2k C413094 | search "8.2k 0402 1%", any in stock |
| LED C12624 | any green 0603 (C2289 = yellow-green hue) |
| ESD C7519 | C2687116 UMW clone |
| 1x03 C124376 | C49257 BOOMELE |
| Sockets C124410  | C2905423 Kinghelm 8.5mm |
| Buttons C2733655 | C180420 Omron B3S-1000P (same land) |
| J8/J9 C165948 | any exact TYPE-C-31-M-12 land-pattern part |

Before substituting, hover one ⚠ icon: if the tooltip says "confirm"/"check"
rather than out-of-stock, those rows may only need their checkbox ticked.

## 8. Micro-B → USB Type-C swaps (2026-07-30, pre-order board changes)

Both micro-B ports were rebuilt as USB Type-C before ordering (LCSC
**C165948**, HRO TYPE-C-31-M-12, JLC **Basic** — cheaper than the Molex
micro-B it replaces; no micro-B remains on the board):

- **J8** (5V-IN, power-only) + `R_CC1`/`R_CC2` 5.1 kΩ Rd pull-downs (LCSC
  **C25905**, Basic; any in-stock 5.1k 0402 substitutes — the Type-C spec
  allows ±10%). Without Rd a compliant Type-C source supplies no VBUS.
- **J9** (PIO-USB device port) + `R_CC3`/`R_CC4` Rd (host never detects a
  device without them). The USB2 D+/D− pad pairs are bridged on-board; the
  VBUS-detect divider `R_J9VD_T`/`R_J9VD_B` moved to the band south of the
  connector.

Each swap regenerated the fab zip + BOM_jlc/CPL_jlc — re-upload ALL THREE
files when re-ordering; older Y-revisions in the JLC cart predate these
changes. Gates at each regeneration: DRC 0 unconnected + the 2 known silk
warnings only, checks 7/7, ERC warnings-only, model↔schematic netlists
match, GND pour union-find = 1 component.

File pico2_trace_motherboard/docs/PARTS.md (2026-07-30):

# Parts Evaluation Notes

Per user directive: reuse Adafruit components for similar circuits where
possible (source: `MBAdafruitBoards/SCHEMATIC_LAYOUT_RULES_AND_TOOLS.md`,
read + extracted during Task 14). This note records the three circuit
blocks surveyed against Adafruit's typical part choices, the sourcing
policy that survey pulled in, and a fab-cost alternate for the Samtec
debug-header shrouds. Verdicts below were ruled during the survey and are
carried into `hw/netlist.py`/`hw/fp_lib.py` as committed; this file just
documents *why*.

## 1. Host-VBUS load switch: TPS2051B (kept) vs Adafruit's AP22802

| Part | Vendor | Package  | Open-drain fault/flag output | Verdict |
| --- | --- | --- | --- | --- |
| TPS2051B | TI | SOT-23-5 | Yes (`FLG`, active-low) | **Kept** — used as `U_HSW` |
| AP22802  | Diodes Inc. | SOT-23-5 | No — `EN`/`IN`/`OUT`/`GND` only | Rejected |

AP22802 is the load switch Adafruit uses in most of their own USB-host/hub
boards, and is otherwise a fine fit (current-limited, thermal-shutdown,
same SOT-23-5 footprint as `U_HSW`'s `loadswitch` fp_class). It was
rejected here because it has no fault/flag pin: DESIGN §8.1 requires GP15
to read the host port's over-current condition (open-drain fault flag),
which is a hard functional requirement, not a nice-to-have. TPS2051B (and
the TPS2052B/TPS2053B family, and AP2211/MIC2005-class parts with a flag
output) keep that pin; AP22802-class parts don't. **TPS2051B stays.**

## 2. USB ESD protection: USBLC6-2SC6 (kept) vs Adafruit's PRTR5V0U2X

| Part | Vendor | Package  | D+/D− pin layout | Verdict |
| --- | --- | --- | --- | --- |
| USBLC6-2SC6 | ST | SOT-23-6 | Flow-through (`IO1`/`IO1B` opposite sides)  | **Kept** — used as `ESD_H`/`ESD_D` |
| PRTR5V0U2X  | NXP | SOT-23-6 | Not flow-through (I/O in and out same side) | Documented alt, not used |

Both are common USB2 ESD-protection arrays in the same SOT-23-6 footprint
(`esd6` fp_class); PRTR5V0U2X is the part Adafruit reaches for most often.
USBLC6-2SC6 was kept because its pinout lets the D+/D− trace pass straight
through the package (see the `_ESD_PADMAP` comment in `hw/netlist.py`:
`IO1`/`IO1B` are the same internal channel, i.e. feed-through pads) instead
of doubling back to the same side — better signal integrity at USB2 full/
high speed, with no cost or availability penalty. PRTR5V0U2X remains a
documented alternate (drop-in footprint-compatible) if USBLC6-2SC6 ever
goes out of stock.

## 3. VBUS current sense: INA180 (analog, populated) + INA219 adopted as a realized DNP option

The populated part (`U_ISNS`, INA180A1DBVR, SOT-23-5, analog output to
GP26/ADC) is unchanged — DESIGN §10 already names INA180/INA181 as the
default. The survey's job here was the DNP alternative: INA219 (I2C
current/power monitor) is Adafruit's signature current-sense part (they
sell it as a standalone breakout and use it across many of their own
boards), and DESIGN §10/§14 already called it out as an optional
I2C-bus alternative that frees GP26. Task 14b **adopted** it as a fully
realized DNP part (`U_INA219_ALT`) instead of the earlier placeholder
(borrowed `isense` footprint, all 5 pins no-connect):

| Aspect | Before (Task 3-14a) | After (Task 14b) |
| --- | --- | --- |
| Footprint | `isense` (SOT-23-5) stand-in — wrong package | `sot23-8` (`Package_TO_SOT_SMD:SOT-23-8`) — real INA219 package |
| Pins | All 5 pins `nc` | All 8 pins wired (IN+/IN− across `R_SHUNT`, GND/VS on the rails, SDA/SCL on I2C0, A0/A1 grounded → address 0x40) |
| `dnp` | `True` | `True` (unchanged — never populated) |

Pinout source: TI SBOS448 (INA219 datasheet), Figure 8-1, "DCN Package
8-Pin SOT-23, Top View": pad1=IN+, pad2=IN−, pad3=GND, pad4=VS, pad5=SCL,
pad6=SDA, pad7=A0, pad8=A1; address-pin table (same datasheet) gives 0x40
for A0=A1=GND.

## 4. Sourcing policy: LCSC-first, JLC Basic-parts priority

Per the fab-cost user directive: prefer parts that are easy to find and
cheap to source. Concretely, for every part choice going forward:

- Check LCSC stock/price first, before any other distributor.
- Prefer JLCPCB "Basic Parts" library selections over "Extended" parts —
  Basic parts carry no per-part assembly fee on a JLC SMT order.
- This is the same priority order Adafruit's own rulebook (§13) recommends
  for its community-manufacturable boards, which is why it's adopted here
  alongside the Adafruit component-reuse survey above.
- None of the three parts surveyed above are blocked by this policy —
  TPS2051B, USBLC6-2SC6, and INA219 (DNP) are all common, multi-distributor
  parts with LCSC stock under multiple manufacturers' equivalents.

## 5. Samtec FTSH ↔ cheap LCSC 1.27 mm keyed-shroud alternate (J3/J6)

`J3` (MIPI-20) and `J6` (Cortex Debug 10) use locally-converted footprints
(`pico2_trace:FTSH-110-01-DV` / `pico2_trace:FTSH-105-01-DV`, `hw/fp_lib.py`)
drawn from Samtec's FTSH-110-01-*-DV / FTSH-105-01-*-DV mechanical
drawings — Samtec parts are the known-good reference for pad geometry and
keying, so the *footprint* stays Samtec-drawn. For BOM sourcing, though,
Samtec is a premium/low-volume-friendly distributor; generic 1.27 mm-pitch
keyed/shrouded box headers (2×10 for J3, 2×5 for J6) from other
manufacturers are commonly stocked on LCSC at a fraction of the cost and
are pin/mechanically compatible with the same footprint, since the shroud
keying and 1.27 mm pitch are the only geometric constraints that matter
for our pads. Carried forward from Task 2's review note: **verify the
chosen LCSC alternate's pad drawing against the Samtec drawing before
fab** (mechanical fit, not just pinout) — this is a Task 17 BOM action
(picking and recording the specific LCSC part number), not resolved here.

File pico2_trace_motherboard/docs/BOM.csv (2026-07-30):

Ref(s) | Qty | Value | Footprint | Type(SMT/THT) | DNP | Notes
C_HSW_IN, C_HVBUS_100n, C_P3V3_1, C_P3V3_2 | 4 | 100 nF / 16V | Capacitor_SMD:C_0402_1005Metric | SMT | No | 100 nF/16V 0402 decoupling/bypass caps, four instances: C_HVBUS_100n (HOST_VBUS bulk-cap companion at J5), C_P3V3_1 (near PICO pin 36/3V3), C_P3V3_2 (at J_STEMMA's 3V3 tap), C_HSW_IN (at U_HSW pin 5/IN, TI-recommended). Generic commodity part; JLC Basic-preferred (Extended Preferred, then Extended, only if no Basic match); LCSC P/N C1525 (see docs/PARTS.md SS4).
C_HVBUS_BULK | 1 | 22 µF / 10V | Capacitor_SMD:C_0805_2012Metric | SMT | No | Generic commodity part; JLC Basic-preferred (Extended Preferred, then Extended, only if no Basic match); LCSC P/N C6119898 (HRE CGA0805X5R226M160MT, 22uF/16V X5R -- MANDATORY swap, genuine Samsung C45783 (22uF/25V X5R) is out of stock; 16V rating still clears the 10V design requirement with margin, just less margin than the outgoing 25V part; see .superpowers/sdd/task-22-report.md SS11).
C_NRESET | 1 | 100 nF / 16V | Capacitor_SMD:C_0402_1005Metric | SMT | Yes | DO NOT POPULATE. Reset-debounce cap across SW1/NRESET; board works without it. Fit only if RUN-button contact bounce is observed in practice.
D_J9_BUSPWR | 1 | 1N4148W | Diode_SMD:D_SOD-123 | SMT | Yes | DO NOT POPULATE. Optional J9-VBUS -> board-VBUS bus-power diode (anode on J9_VBUS); only needed if J9 should ever power the board from a bus-powered-device host. Default is J9 detect-only, self-powered board.
D_VSYS | 1 | B5819W | Diode_SMD:D_SOD-123 | SMT | No | Always populated. Diode-ORs the JP1-selected board rail (VBUS_SEL) into the Pico's VSYS pin, so JP1=JTRACE powers the Pico via VSYS while leaving pin 40/VBUS_NET free for the module's own micro-USB to act as an OTG host. Combined with the Pico's own internal VBUS→VSYS Schottky this forms a diode-OR: no jumper/cable combination can back-feed either supply. ~0.3V drop on VSYS is harmless (Pico VSYS accepts 1.8-5.5V). Generic commodity part; JLC Basic-preferred (Extended Preferred, then Extended, only if no Basic match); LCSC P/N C8598 (see docs/PARTS.md SS4).
ESD_D, ESD_H | 2 | USBLC6-2SC6 | Package_TO_SOT_SMD:SOT-23-6 | SMT | No | ST USBLC6-2SC6 or pin-identical equiv, SOT-23-6. Flow-through pinout required (IO1/IO1B same channel, IO2/IO2B same channel) -- do not substitute a non-flow-through ESD array (e.g. PRTR5V0U2X) without re-verifying the pin function mapping. Generic commodity part; JLC Basic-preferred (Extended Preferred, then Extended, only if no Basic match); LCSC P/N C2687116 (UMW USBLC6-2SC6, cost-swapped from genuine ST C7519 -- same MPN/flow-through pinout, ~$0.13/ea cheaper, both Extended tier; see docs/PARTS.md SS4 and .superpowers/sdd/task-22-report.md SS4).
J10 | 1 | SWD | Connector_PinHeader_2.54mm:PinHeader_1x03_P2.54mm_Vertical | THT | No | THT 2.54mm pin header, 3-pin header, dupont SWD (SWCLK/GND/SWDIO), same order as J7. JLC-assembled (THT hand-solder service) -- see docs/BOM_jlc.csv (LCSC C124376, Ckmtw B-2100S03P-A110); hand-soldering by the user only applies if ordering bare boards. Shunt/jumper cap sourced separately (generic, ~$0.05 each, user-purchased -- not a JLC assembly item). GND pads use thermal relief.
J1B, J2B | 2 | BREAKOUT | Connector_PinSocket_2.54mm:PinSocket_1x20_P2.54mm_Vertical | THT | No | Outer breakout row (per-pin access), 1x20 THT female socket, 2.54mm pitch. JLC-assembled (THT hand-solder service) -- see docs/BOM_jlc.csv (LCSC C124410, Ckmtw B-2200S20P-A120). The hand-solder note below only applies if ordering bare boards.
J3 | 1 | MIPI-20 | pico2_trace:FTSH-110-01-DV | SMT | No | Primary: generic 1.27mm-pitch SMD shrouded box header (2x10, 20-pin), ~$0.50-1.50 on LCSC. Alternate: Samtec FTSH-110-01-L-DV-K (~$5-8), the part the footprint is drawn from. Three checks before ordering: (1) MUST be SMD, not THT -- many cheap 1.27mm shrouded headers are THT and will not fit this land pattern at all; (2) shroud/plastic body size varies between clones -- ours is dimensioned from the FTSH-110, a larger body can foul neighbouring connectors on the debug edge. Measured mechanical margin: J6↔J10 courtyard gap is 0.700 mm and J10↔J7 is 0.670 mm, so an oversize clone shroud will foul its neighbours. (3) prefer the keyed shroud so the J-Trace ribbon cannot be inserted backwards. Land: pads 2.4 x 0.74mm, pin pitch 1.27mm, pad-row centres 3.90mm apart. Do not pin a specific LCSC part number here -- verify against the Samtec drawing before ordering (docs/PARTS.md SS5). Keyed shroud requirement dropped (2026-07-29): plain unshrouded 1.27mm SMD header now acceptable, so cheap clones were re-evaluated -- but every in-stock candidate found (BOOMELE 1.27-2*10P, XUNPU PH1.27-02-10PWS) carries a listing-attribute \Row Spacing: 1.27mm\" | far short of our required 3.90mm row-centre spacing; none could be verified to land on our copper. Verified LCSC part unchanged: C20728453 (Samtec FTSH-110-01-L-DV-K-TR) | genuine | in stock (see docs/PARTS.md SS5 and .superpowers/sdd/task-22-report.md SS2)."
J5 | 1 | USB-A HOST | Connector_USB:USB_A_Receptacle_GCT_USB1046 | SMT | No | GCT USB1046 or pin/footprint-compatible equiv: SMD signal pads + 2 THT mounting posts (mechanical only, hand-solder after reflow or with the THT parts). Pad 5 (both mounting-post instances) is tied to GND. Generic commodity part; JLC Basic-preferred (Extended Preferred, then Extended, only if no Basic match); LCSC P/N C6307429 (see docs/PARTS.md SS4).
J6 | 1 | CORTEX-10 | pico2_trace:FTSH-105-01-DV | SMT | No | Primary: generic 1.27mm-pitch SMD shrouded box header (2x5, 10-pin), ~$0.50-1.50 on LCSC. Alternate: Samtec FTSH-105-01-L-DV-K (~$5-8), the part the footprint is drawn from. Three checks before ordering: (1) MUST be SMD, not THT -- many cheap 1.27mm shrouded headers are THT and will not fit this land pattern at all; (2) shroud/plastic body size varies between clones -- ours is dimensioned from the FTSH-110, a larger body can foul neighbouring connectors on the debug edge. Measured mechanical margin: J6↔J10 courtyard gap is 0.700 mm and J10↔J7 is 0.670 mm, so an oversize clone shroud will foul its neighbours. (3) prefer the keyed shroud so the J-Trace ribbon cannot be inserted backwards. Land: pads 2.4 x 0.74mm, pin pitch 1.27mm, pad-row centres 3.90mm apart. Do not pin a specific LCSC part number here -- verify against the Samtec drawing before ordering (docs/PARTS.md SS5). Keyed shroud requirement dropped (2026-07-29): plain unshrouded 1.27mm SMD header now acceptable, so cheap clones were re-evaluated -- but every in-stock candidate found (HCTL PZ127-2-05-S/2-10-S family) carries a listing-attribute \Row Spacing: 1.27mm\" | far short of our required 3.90mm row-centre spacing; none could be verified to land on our copper. Verified LCSC part unchanged: C448647 (Samtec FTSH-105-01-L-DV-K-TR) | genuine | in stock (see docs/PARTS.md SS5 and .superpowers/sdd/task-22-report.md SS2)."
J7 | 1 | JST-SH-3 DEBUG_PROBE | Connector_JST:JST_SH_SM03B-SRSS-TB_1x03-1MP_P1.00mm_Horizontal | SMT | No | JST SM03B-SRSS-TB or equiv, right-angle, 1.0mm pitch. Pinout SWCLK/GND/SWDIO -- mates with a Raspberry Pi Debug Probe cable. Generic commodity part; JLC Basic-preferred (Extended Preferred, then Extended, only if no Basic match); LCSC P/N C160403 (genuine, still in stock -- a cheaper HCTL HC-1.0-3PWT clone (C2845362) was investigated but its mechanical-tab pad-edge alignment vs. the genuine SM03B-SRSS-TB drawing could not be independently confirmed and conflicting claims arose across research passes, so kept genuine per the no-guess rule since this line isn't stock-forced; see docs/PARTS.md SS4 and .superpowers/sdd/task-22-report.md SS3).
J8 | 1 | USB-C PWR | pico2_trace:USB_C_PWR_HRO_TYPE-C-31-M-12 | SMT | No | USB Type-C receptacle, power-only 5V input (micro-B -> Type-C swap 2026-07-30). HRO TYPE-C-31-M-12 land pattern; D+/D-/SBU NC; second VBUS column (A9/B4) board-NC -- plug parallels all four VBUS beams, A4/B9 alone carries the input. LCSC P/N C165948 (JLC Basic).
R_CC1, R_CC2, R_CC3, R_CC4 | 4 | 5.1 kΩ | Resistor_SMD:R_0402_1005Metric | SMT | No | Type-C CC Rd pull-downs, J8 power port + J9 device port (UFP, ±10% tolerance per spec -- any 1%/5% 0402 5.1k works). LCSC P/N C25905.
J9 | 1 | USB-C DEV | pico2_trace:USB_C_DEV_HRO_TYPE-C-31-M-12 | SMT | No | USB Type-C receptacle, PIO-USB device port (micro-B -> Type-C swap 2026-07-30). HRO TYPE-C-31-M-12 land; D+/D- pad pairs bridged on board; SBU + second VBUS column NC. LCSC P/N C165948 (JLC Basic).
JP1 | 1 | 5V SEL | Connector_PinHeader_2.54mm:PinHeader_1x03_P2.54mm_Vertical | THT | No | THT 2.54mm pin header, 3-pin header + shunt, board 5V source select (silk 5V SEL / JTRACE / VBUS). With D_VSYS added, JTRACE now also powers the Pico via VSYS -- see docs/BRINGUP.md "Power rules". JLC-assembled (THT hand-solder service) -- see docs/BOM_jlc.csv (LCSC C124376, Ckmtw B-2100S03P-A110); hand-soldering by the user only applies if ordering bare boards. Shunt/jumper cap sourced separately (generic, ~$0.05 each, user-purchased -- not a JLC assembly item). GND pads use thermal relief.
JP2 | 1 | GP0 GUARD | Connector_PinHeader_2.54mm:PinHeader_1x02_P2.54mm_Vertical | THT | No | THT 2.54mm pin header, 2-pin header + shunt, GP0 GND guard, default fitted. JLC-assembled (THT hand-solder service) -- see docs/BOM_jlc.csv (LCSC C124375, Ckmtw B-2100S02P-A110); hand-soldering by the user only applies if ordering bare boards. Shunt/jumper cap sourced separately (generic, ~$0.05 each, user-purchased -- not a JLC assembly item). GND pads use thermal relief.
JP3 | 1 | GP6 GUARD | Connector_PinHeader_2.54mm:PinHeader_1x02_P2.54mm_Vertical | THT | No | THT 2.54mm pin header, 2-pin header + shunt, GP6 GND guard, default fitted. JLC-assembled (THT hand-solder service) -- see docs/BOM_jlc.csv (LCSC C124375, Ckmtw B-2100S02P-A110); hand-soldering by the user only applies if ordering bare boards. Shunt/jumper cap sourced separately (generic, ~$0.05 each, user-purchased -- not a JLC assembly item). GND pads use thermal relief.
JP4 | 1 | VBUS_DET EN | Connector_PinHeader_2.54mm:PinHeader_1x02_P2.54mm_Vertical | THT | No | THT 2.54mm pin header, 2-pin header + shunt, native VBUS-detect tap enable, default fitted. JLC-assembled (THT hand-solder service) -- see docs/BOM_jlc.csv (LCSC C124375, Ckmtw B-2100S02P-A110); hand-soldering by the user only applies if ordering bare boards. Shunt/jumper cap sourced separately (generic, ~$0.05 each, user-purchased -- not a JLC assembly item). GND pads use thermal relief.
J_STEMMA | 1 | STEMMA-QT | Connector_JST:JST_SH_SM04B-SRSS-TB_1x04-1MP_P1.00mm_Horizontal | SMT | No | JST SM04B-SRSS-TB or equiv, right-angle, 1.0mm pitch, Adafruit STEMMA-QT/Qwiic pinout (GND/3V3/SDA/SCL). Generic commodity part; JLC Basic-preferred (Extended Preferred, then Extended, only if no Basic match); LCSC P/N C51940130 (XYECONN XY-SM04B-SRSS-TB -- MANDATORY swap, genuine JST C160404 is out of stock; confirmed 4-pin/1.0mm-pitch/right-angle SMD match and MPN explicitly mirrors the genuine JST part number (drop-in-clone naming convention); mechanical/ground-tab pad-edge alignment vs. the genuine drawing was claimed favorable in one research pass and unfavorable for a rival HCTL candidate in another, with conflicting numbers between passes -- tabs are mechanical/ground-only, not signal-critical, so accepted with residual doubt flagged; visually check tab solder coverage on arrival. See docs/PARTS.md SS4 and .superpowers/sdd/task-22-report.md SS4).
J_UART | 1 | UART0 | Connector_PinHeader_2.54mm:PinHeader_1x03_P2.54mm_Vertical | THT | No | THT 2.54mm pin header, 3-pin header, UART0 console TX/RX/GND. JLC-assembled (THT hand-solder service) -- see docs/BOM_jlc.csv (LCSC C124376, Ckmtw B-2100S03P-A110); hand-soldering by the user only applies if ordering bare boards. Shunt/jumper cap sourced separately (generic, ~$0.05 each, user-purchased -- not a JLC assembly item). GND pads use thermal relief.
LED_PWR, LED_USER | 2 | LED | LED_SMD:LED_0603_1608Metric | SMT | No | 0603 LED, colour to taste (suggest green=power, any=user). LED_PWR sits on VBUS_SEL, so it now indicates whichever rail JP1 has selected. Generic commodity part; JLC Basic-preferred (Extended Preferred, then Extended, only if no Basic match); LCSC P/N C12624 (see docs/PARTS.md SS4).
PICO | 1 | Pico2 | Module:RaspberryPi_Pico_Common_THT | THT | No | This footprint IS the pair of inner sockets the Pico 2 plugs into: 2x 1x20 THT female socket strips, 2.54mm pitch. JLC-assembled (THT hand-solder service) -- since JLC's CPL needs one designator per physical part, this footprint's two rows are ordered as separate placements PICO1 (pads 21-40 row) and PICO2 (pads 1-20 row) in docs/BOM_jlc.csv/CPL_jlc.csv (LCSC C124410, Ckmtw B-2200S20P-A120). Hand-soldering by the user only applies if ordering bare boards.
R_DDM, R_DDP, R_HDM, R_HDP | 4 | 22 Ω | Resistor_SMD:R_0402_1005Metric | SMT | No | Generic commodity part; JLC Basic-preferred (Extended Preferred, then Extended, only if no Basic match); LCSC P/N C114765 (YAGEO RC0402FR-0722RL, ±1% 0402 -- MANDATORY swap, genuine UNI-ROYAL C25092 went out of stock during this pass; see .superpowers/sdd/task-22-report.md SS10).
R_DPU | 1 | 1.5 kΩ | Resistor_SMD:R_0402_1005Metric | SMT | No | Generic commodity part; JLC Basic-preferred (Extended Preferred, then Extended, only if no Basic match); LCSC P/N C114759 (YAGEO RC0402FR-071K5L, ±1% 0402 -- MANDATORY swap, genuine UNI-ROYAL C25867 went out of stock during this pass; see .superpowers/sdd/task-22-report.md SS10).
R_HDM_PD, R_HDP_PD | 2 | 15 kΩ | Resistor_SMD:R_0402_1005Metric | SMT | No | Generic commodity part; JLC Basic-preferred (Extended Preferred, then Extended, only if no Basic match); LCSC P/N C25756 (see docs/PARTS.md SS4).
R_HVEN_PD | 1 | 100 kΩ | Resistor_SMD:R_0402_1005Metric | SMT | No | Generic commodity part; JLC Basic-preferred (Extended Preferred, then Extended, only if no Basic match); LCSC P/N C60491 (YAGEO RC0402FR-07100KL, ±1% 0402 -- MANDATORY swap, genuine UNI-ROYAL C25741 went out of stock during this pass (its sister SKU C25086 also OOS); see .superpowers/sdd/task-22-report.md SS10).
R_J9VD_B, R_J9VD_T, R_NVD_B, R_NVD_T | 4 | 8.2 kΩ | Resistor_SMD:R_0402_1005Metric | SMT | No | Generic commodity part; JLC Basic-preferred (Extended Preferred, then Extended, only if no Basic match); LCSC P/N C413094 (Panasonic ERJ2RKF8201X, ±1% 0402 -- MANDATORY swap, genuine Basic-tier C25924 went out of stock with a 30-unit shortfall and no in-stock Basic 8.2k/0402 alternative exists industry-wide; this is Extended tier, unavoidable; see .superpowers/sdd/task-22-report.md SS1).
R_LED_PWR, R_LED_USER | 2 | 1 kΩ | Resistor_SMD:R_0402_1005Metric | SMT | No | Generic commodity part; JLC Basic-preferred (Extended Preferred, then Extended, only if no Basic match); LCSC P/N C106235 (YAGEO RC0402FR-071KL, ±1% 0402 -- MANDATORY swap, genuine UNI-ROYAL C11702 went out of stock during this pass; see .superpowers/sdd/task-22-report.md SS10).
R_SHUNT | 1 | 0.1 Ω (1%, current-sense shunt) | Resistor_SMD:R_1206_3216Metric | SMT | No | Generic commodity part; JLC Basic-preferred (Extended Preferred, then Extended, only if no Basic match); LCSC P/N C844896 (see docs/PARTS.md SS4).
Rt1, Rt2, Rt3, Rt4, Rt5 | 5 | 27 Ω | Resistor_SMD:R_0402_1005Metric | SMT | No | Generic commodity part; JLC Basic-preferred (Extended Preferred, then Extended, only if no Basic match); LCSC P/N C25100 (see docs/PARTS.md SS4).
SW1 | 1 | RESET | Button_Switch_SMD:SW_SPST_B3S-1000 | SMT | No | SMD tactile switch (e.g. B3S-1000 or equiv), low-profile top-actuated. Generic commodity part; JLC Basic-preferred (Extended Preferred, then Extended, only if no Basic match); LCSC P/N C2733655 (see docs/PARTS.md SS4).
SW_USER | 1 | USER | Button_Switch_SMD:SW_SPST_B3S-1000 | SMT | No | SMD tactile switch (e.g. B3S-1000 or equiv), low-profile top-actuated. Generic commodity part; JLC Basic-preferred (Extended Preferred, then Extended, only if no Basic match); LCSC P/N C2733655 (see docs/PARTS.md SS4).
TP1 | 1 | TP | TestPoint:TestPoint_Pad_D1.5mm | N/A (bare pad) | No | Bare copper test pad -- no part to order.
TP2 | 1 | TP | TestPoint:TestPoint_Pad_D1.5mm | N/A (bare pad) | No | Bare copper test pad -- no part to order.
TP3 | 1 | TP | TestPoint:TestPoint_Pad_D1.5mm | N/A (bare pad) | No | Bare copper test pad -- no part to order.
U_HSW | 1 | TPS2051B | Package_TO_SOT_SMD:SOT-23-5 | SMT | No | TI TPS2051B, SOT-23-5 (DBV), needs the open-drain FLG fault output (rules out AP22802-class switches with no flag pin -- see docs/PARTS.md SS1). Generic commodity part; JLC Basic-preferred (Extended Preferred, then Extended, only if no Basic match); LCSC P/N C24593 (see docs/PARTS.md SS4).
U_INA219_ALT | 1 | INA219 | Package_TO_SOT_SMD:SOT-23-8 | SMT | Yes | DO NOT POPULATE. Alternate I2C current/power monitor (address 0x40, A0/A1 grounded), parallels U_ISNS across the same shunt -- fit instead of (not in addition to a working) U_ISNS if the analog path is undesired; frees GP26. See docs/PARTS.md SS3.
U_ISNS | 1 | INA180A1DBVR | Package_TO_SOT_SMD:SOT-23-5 | SMT | No | TI INA180A1DBVR, SOT-23-5, Pinout A (no external REF pin). Confirm the exact suffix when ordering -- other INA180/181 grades share the package but not always the pinout. Generic commodity part; JLC Basic-preferred (Extended Preferred, then Extended, only if no Basic match); LCSC P/N C122228 (see docs/PARTS.md SS4).
(extra) DEBUG CABLE | 1 | JST-SH<->dupont or JST-SH<->JST-SH | N/A (accessory) | N/A (accessory) | No | Ordering extra, not on the PCB and NOT a JLC assembly item -- user-purchased. Cables the Pico's own onboard JST-SH debug port out to whichever board-side SWD connector is in use: JST-SH-to-dupont for J10, or JST-SH-to-JST-SH for J7. Only one is needed. Both ship with the Raspberry Pi Debug Probe; either is also a common standalone LCSC/Adafruit item.
(extra) JUMPER SHUNTS | 4 | 2.54mm shunt/jumper cap | N/A (accessory) | N/A (accessory) | No | Ordering extra, not on the PCB and NOT a JLC assembly item -- user-purchased. One 2.54mm shunt per JP1-JP4 (JP1 is 3-pin, JP2-JP4 are 2-pin -- any generic 2.54mm shunt fits both). Generic, ~$0.05 each; a handful of spares are cheap insurance.
(extra) MH1-MH4 HARDWARE | 4 | M3 screw + standoff | N/A (accessory) | N/A (accessory) | No | Ordering extra, not on the PCB and NOT a JLC assembly item -- user-purchased. M3 screws/standoffs (or nuts) for the 4 mounting holes MH1-MH4; length/standoff height depends on the enclosure, not specified here.
(extra) SOCKET STRIPS | 4 | 1x20 2.54mm THT female socket | N/A (accessory) | N/A (accessory) | No | Superseded now that full assembly is JLC-ordered: the 4 total 1x20 THT female socket strips (2 populate the PICO footprint's inner sockets as PICO1/PICO2, 2 populate J1B/J2B's outer breakout row) are JLC-assembled parts (LCSC C124410, see docs/BOM_jlc.csv) -- not a separate user purchase. This line is kept only as a historical cross-reference for bare-board orders; no action needed when ordering the fully-assembled board.

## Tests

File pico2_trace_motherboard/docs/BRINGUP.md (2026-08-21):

# Pico 2 Trace Motherboard — Bring-Up Note

## Board summary

92.0 × 64.0 mm (`Edge.Cuts` centreline; the 92.1 × 64.1 mm figure quoted
in earlier drafts is the bounding box, 0.1 mm bigger on each axis because
the outline is drawn with a 0.1 mm-wide stroke that extends 0.05 mm past
the centreline on every side), 2-layer FR4, 1.6 mm. Design-complete,
DRC-clean (0 unconnected; see "First-power checklist" below for the 2
accepted pre-existing silk violations).

**"Top = all signal routing, bottom = solid GND pour" is not what got
built — corrected here.** Measured directly off the board (`pcbnew`,
per-net/per-layer track length):

- **F.Cu is the one that's nearly a solid plane**: 3657.30 mm² of GND
  pour, 3430.96 mm² of it (94%) in one single island. Component
  placement and the five trace signals (`TRACECLK`/`TD0`–`TD3`) also
  live here.
- **B.Cu carries roughly half of all signal routing** — 1090.63 mm of
  the board's 2229.53 mm total track length (48.9%), including several
  of the "important" nets: `P3V3` 223.53 mm, `VBUS_NET` 131.19 mm,
  `NRESET` 99.81 mm, `VBUS_SEL` 80.25 mm, `I2C0_SDA`+`I2C0_SCL` 148.02 mm
  combined, `SWDIO` 67.39 mm. B.Cu's GND pour is correspondingly
  fragmented — 3730.16 mm² split across 18 islands, the largest only
  2328.38 mm² (62%) — a patchwork, not a plane.
- **What does hold**: the five trace nets are **100% F.Cu, with the
  nearest non-trace B.Cu track 1.27 mm away** (an `NRESET` segment) —
  zero B.Cu tracks pass within 1 mm of the bundle. The trace group's
  return-path reference is intact even though the "solid bottom plane"
  framing for the rest of the board was wrong.

| Ref | Purpose |
| --- | --- |
| `PICO` | Pico 2 / Pico socket (2× inner 1×20 THT female, hand-soldered) |
| `J1B`, `J2B` | Per-pin breakout rows, pin-for-pin with the Pico header |
| `J3` | MIPI-20 Cortex Debug+ETM — SEGGER J-Trace (SWD + 4-bit parallel trace) |
| `J5` | USB-A receptacle — PIO-USB **host** port (GP20/21) |
| `J6` | Cortex Debug 2×5 — plain J-Link (SWD only, no trace) |
| `J7` | JST-SH 3-pin — Raspberry Pi Debug Probe ("pico-debug") jack |
| `J8` | USB **Type-C**, power-only — 5 V input for host-stack work |
| `J9` | USB **Type-C** — PIO-USB **device** port (GP18/19) |
| `J10` | 3-pin dupont header — SWD (SWCLK/GND/SWDIO) |
| `J_UART` | UART0 console (GP12 TX / GP13 RX / GND) |
| `J_STEMMA` | STEMMA-QT / Qwiic I2C0 (GP8 SDA / GP9 SCL) |
| `JP1`–`JP4`  | Jumpers — see the jumper table below |
| `SW1` | RUN reset button |
| `SW_USER` | User button (GP14 → GND) |
| `TP1`–`TP3`  | Probe points on the PIO-USB host D+/D−/GND |
| `MH1`–`MH4`  | M3 mounting holes |

## Jumper settings

| Jumper | Silk | Fitted position  | Meaning |
| --- | --- | --- | --- |
| `JP1`  | `5V SEL` / `JTRACE` / `VBUS` | `1-2` = `JTRACE` | J-Trace's MIPI-20 5 V pins power `VBUS_SEL` — **and, via `D_VSYS`, the Pico itself** (`VBUS_SEL`→`D_VSYS`→`VSYS`); pin 40/`VBUS_NET` stays free, so the module's own micro-USB can act as an **OTG host** |
| | | `2-3` = `VBUS` | The board's own `VBUS_NET` (module micro-USB / J8 / ext-5 V) powers `VBUS_SEL` and the Pico (via pin 40, as before) — **this is the 5 V source select** |
| `JP2`  | `GUARD GP0` | fitted (default) | GP0 tied to GND (grounded guard next to TRACECLK) |
| | | removed | GP0 freed for other use |
| `JP3`  | `GUARD GP6` | fitted (default) | GP6 tied to GND (grounded guard next to the trace block) |
| | | removed | GP6 freed for other use |
| `JP4`  | `VBUS DET` | fitted (default) | Enables the native VBUS-detect tap (VBUS_NET → divider → GP16) |
| | | removed | GP16 freed, tap disconnected |

## Power rules

- **Exactly one hard 5 V source on `VBUS_NET` at a time.** `VBUS_NET` is
  a single hard-tied node (Pico pin 40 = module micro-USB VBUS = J8 =
  external-5 V injection) — it cannot be diode-isolated or
  switch-broken, so doubling up sources on it (e.g. the module's own
  micro-USB plugged into a PC *and* J8 powered) is a real short between
  two supplies. This is unchanged by the additions below.
- **`D_VSYS` (added, always populated)** diode-ORs the JP1-selected rail
  (`VBUS_SEL`) into the Pico's `VSYS` pin, in parallel with the Pico
  module's own internal VBUS→VSYS Schottky. The two diodes form a
  genuine diode-OR into `VSYS`: whichever supply (module micro-USB via
  pin 40, or the JP1-selected rail via `D_VSYS`) is actually present
  wins, and neither can back-feed the other — **no jumper position or
  cable combination can make two supplies fight**, which is a safer
  arrangement than the original `DESIGN.md` §7 spec (a hard tie between
  J-Trace 5 V and `VBUS_NET`). The ~0.3 V Schottky forward drop on
  `VSYS` is harmless — the Pico's `VSYS` input accepts 1.8–5.5 V.
- **`JP1 = JTRACE`**: J-Trace's MIPI-20 5 V pins feed `VBUS_SEL` (and,
  through the host load switch, `J5`) **and now power the Pico via
  `D_VSYS`→`VSYS`**, while `VBUS_NET`/pin 40 stays free — which **frees
  the Pico's own micro-USB to act as an OTG host** (its VBUS is then
  sourced from pin 40 instead of being an input).
- **`JP1 = VBUS`**: the board runs from the module micro-USB (device),
  J8, or an external-VBUS injection; `VBUS_SEL` and `VBUS_NET` are the
  same node in this position (shorted by the jumper), so `D_VSYS` and
  the Pico's own internal diode simply conduct in parallel from the same
  source — harmless. J-Trace's 5 V pins are disconnected from
  `VBUS_SEL`.
- J-Trace's 5 V rail is current-limited (a few hundred mA) — for
  anything power-hungry downstream, use J8 or a strong USB supply
  instead.
- `LED_PWR` (the power LED) sits on `VBUS_SEL`, so it indicates
  whichever rail JP1 has selected — **this reading is now correct** for
  both jumper positions, since JP1=JTRACE actually powers the whole
  board (Pico included) rather than just the host port.

## As-built additions (commit `6d67559`)

Four parts added, none of them change any existing net's *function*,
only add feed/bypass paths:

- **`D_VSYS`** (B5819W Schottky, SOD-123): pad 1 (cathode) = `VSYS`,
  pad 2 (anode) = `VBUS_SEL`. See "Power rules" above.
- **`C_P3V3_1`**, **`C_P3V3_2`** (100 nF/16 V, 0402): `P3V3` → `GND`
  decoupling — one near Pico pin 36 (the 3V3 output), one at
  `J_STEMMA`'s 3V3 tap.
- **`C_HSW_IN`** (100 nF/16 V, 0402): `HOST_5V_IN` → `GND`, at `U_HSW`
  pin 5 (IN) — TI's recommended input bypass for the TPS2051B load
  switch.
- **`J5` pad 5** (the USB-A receptacle's 2 mechanical mounting-post
  pads) is now tied to `GND` (previously unconnected) — proper shield
  grounding for the host port.

Adding the 4 new footprints reshaped the ground pour enough to strand
**two GND-pour islands** from the main plane (caught by DRC
`unconnected_items`, not by visual inspection — see the comments around
`_STITCH_VIAS_FRAGMENT_FIX`/`_STITCH_VIAS_PAD_ESCAPE` in `hw/pour.py`
for the full graph-connectivity diagnosis). Healed with:
- a stitching via at `(45.39, 32.0)` — grounds copper directly under the
  seated Pico module, near PICO pin 23;
- a 3-segment F.Cu bridge stub with transition vias at `(52.0, 15.0)`
  and `(49.205, 16.9)` — near `J_STEMMA`/`J_UART`/`R_NVD`/`C_P3V3_2`.

Both mechanisms live in `hw/pour.py` (`_STITCH_VIAS_FRAGMENT_FIX`,
`_GND_STUBS`, `_STITCH_VIAS_PAD_ESCAPE`). Verified with a union-find
over all GND copper (vias, same-layer tracks, and pads, since THT/plated
pads bridge F.Cu↔B.Cu just like vias do): **connected components = 1**
(38 F.Cu+B.Cu islands, 7387.46 mm² combined).

## The 5 SWD entry points

Five connectors reach the same shared SWDIO/SWCLK/GND net: `J3` (MIPI-20),
`J6` (Cortex 2×5), `J7` (JST-SH), `J10` (3-pin dupont) — plus the Pico's own
onboard JST-SH debug port, which is the *source* the other four fan out
from, not a redundant sixth entry point.

- **One probe at a time.** All four board-side connectors are wired in
  parallel on the same net — driving two probes simultaneously is a bus
  fight, not a "pick either" situation.
- **`J10` or `J7` must be cabled to the Pico's own onboard JST-SH debug
  port for any of the four connectors to reach the target at all.** The
  board only fans the SWD signals *out*; nothing on the board generates
  them. Without that one jumper cable in place, `J3`/`J6`/`J7`/`J10` are
  all dead.
- The Pico's onboard debug port is JST-SH 1.0 mm — so a `J10` (dupont) →
  Pico cable needs a **JST-SH-to-dupont** cable (this ships with the
  Raspberry Pi Debug Probe). A `J7` → Pico cable is JST-SH-to-JST-SH
  (also ships with the Debug Probe).

## Assembly notes

- **Full assembly (SMT + THT) is the chosen JLC ordering option.** JLCPCB's
  hand-soldering ("plug-in") service places the THT parts — the Pico
  socket rows (`PICO1`/`PICO2`), `J1B`, `J2B`, `JP1`–`JP4`, `J_UART`,
  `J10` — alongside the SMT reflow parts in one JLC assembly order. See
  `docs/BOM_jlc.csv`/`docs/CPL_jlc.csv` for the full assembly BOM/CPL and
  `docs/BOM.csv` for per-part sourcing notes.
- The hand-solder list below now only applies **if ordering bare boards**
  (no assembly service) instead:
  - All THT parts (`PICO` socket, `J1B`, `J2B`, `JP1`–`JP4`, `J_UART`,
    `J10`, + `J5`'s 2 mechanical mounting posts) would be hand-soldered by
    the user — see `docs/BOM.csv` for per-part sourcing.
- GND pads on THT parts use thermal relief spokes rather than a solid
  copper flood, so they solder normally with a hand iron (a solid-flood tie
  into the ground plane would act as a heatsink and make hand-soldering
  those pads difficult or impossible) — this also helps JLC's hand-solder
  line for the same reason.
- Everything else is SMT, reflow or hand-soldered as the assembler prefers.
- If JLC's ordering UI forces **Standard** (not Economic) PCBA once THT
  parts are in the BOM, that's expected on some JLC configurations —
  proceed with Standard. (JLCPCB's own parts-library listing for the three
  new THT connectors marks them wave-solder-compatible under both Economic
  and Standard PCBA, so Economic may also be offered; either way, confirm
  whichever assembly type JLC selects at checkout.)

## First-power checklist

1. **Visual inspection** — no solder bridges, especially on the 1.27 mm
   `J3`/`J6` shroud pads and the 0.1 Ω `R_SHUNT` (1206). Confirm the 2
   accepted `silk_edge_clearance` DRC violations are cosmetic only (silk
   text clipped by the board edge — re-verify with `kicad-cli pcb drc
   --format json` if in doubt; expect exactly those 2 and 0 unconnected).
2. **Continuity check** — VBUS_NET, GND, P3V3 not shorted to each other
   before powering.
3. Seat the Pico (or Pico 2) in the socket, `JP1 = VBUS`, `JP2`/`JP3`
   fitted (guards on), `JP4` fitted (VBUS-detect tap enabled).
4. Power from the module's own micro-USB (device, from a PC). Confirm the
   power LED (`LED_PWR`) lights.
5. Probe `P3V3` at a breakout pin — expect 3.3 V.
6. Attach a probe to `J7` or `J10` (cabled to the Pico's onboard debug
   port, per above) and read the SWD target ID (e.g.
   `JLinkExe -device RP2350 -if SWD -speed 4000` → `id`, or `openocd`
   equivalent). Confirms SWD fan-out end to end before trusting `J3`/`J6`.
7. Confirm USB enumeration: plug the module micro-USB into a PC and check
   `lsusb`/Device Manager for the expected VID:PID of whatever firmware is
   loaded.

## Trace bring-up ladder

**This section supersedes stale guidance in `DESIGN.md`.** The J-Trace PRO
V2 is **in-spec to 100 MHz TRACECLK, ~120 MHz achievable with sampling-delay
tuning** (SEGGER's own published V2 best; the 150 MHz on current product
pages is V3/V4 hardware). The ~40 MHz cliff recorded in the
original fly-wire handoff (`PICO2_TRACE_PCB_HANDOFF.md`) was a *fly-wire
signal-integrity limit, not a probe limit*. This PCB (source-terminated,
short, GND-guarded — see DESIGN.md §5.4) should be pushed well past that
old cliff.

Run the ladder at **48 → 80 → 120 → 150 MHz core** (TRACECLK = core/2, so
24/40/60/75 MHz TRACECLK), capturing at each rung with the repo's
`etm-trace` skill:

1. Idle blinky first at each rung — confirms the link is alive before
   loading it.
2. Then `TRACE_ETM` `cdc_msc` at each passing rung — **the USB enumeration
   burst is the killer test** (dense, bursty trace data; far more demanding
   than blinky's steady low rate).
3. On failure, bisect with `--trace-width 1/2/4` and `--trace-timing` (per
   DESIGN.md §13's validation plan) before concluding the rung is bad —
   narrow the fault to a specific trace line or a timing margin instead of
   a blanket "clock too high."
4. Accept a rung at 3/3 full-total captures; record the final achieved
   rate here and in the `etm-trace` skill's board table.

### Result (2026-08-21, first bring-up)

**PASS at 180 MHz core / 90 MHz TRACECLK, width 4** — beyond the ladder's
top rung, on the same J-Trace PRO V2. The one required setting is **data
sampling +5 ns** (`Project.SetTraceTiming (5000, 5000, 5000, 5000)`,
committed in the TinyUSB ozone reference): under the cdc_msc enumeration
burst the eye passes at +4000..+5000 ps (3/3 each) and is dead at
<= +3000 ps; TD=0 (the fly-wire's working value at 24 MHz TRACECLK) does
not decode at 90 MHz. Zero overflow across all passing runs, 15M
fetches/10 s full-quality profiles. Intermediate rungs (80/120/150) were
skipped — 48 smoke-passed, then straight to the 180 MHz goal.

Known flake: an occasional *instant* unknown-packet death (offset
~0x10-0x6C) right as the stream arms, while the bootrom still runs on its
boot clock — retry the capture; it is not a board or timing fault. The
"Known SI limitation" below (J1B return-path gaps) never surfaced: no
mid-stream decode failures in any accepted run.

### TRACECLK ceiling (2026-08-21, same session)

The headroom ladder was run the same day: **120 MHz TRACECLK (240 MHz
core, vreg 1.15 V) is the maximum** — cdc_msc 3/3 at TD +3500 with 12 mA
fast-slew pads asserted pre-PLL-switch. **>= 125 MHz TRACECLK is a hard
probe wall**: 125/130/140/150 MHz TRACECLK all failed at every sample
delay (full-UI 500 ps sweep at 125), at trace width 1, and with fast
pads — a razor edge between 120 (≈2 ns open eye) and 125 MHz (closed)
consistent with the V2's real capability, not with this board's SI (which
the wall's sharpness exonerates: board-limited eyes close gradually).
Post-hoc spec check: SEGGER's in-spec max trace clock is 100 MHz, and
their only published faster V2 number is "up to 120 MHz ... with a slight
adjustment of sampling delays in J-Trace PRO V2" (J-Trace Isolator page)
— this rig reproduced that number exactly; the "150 MHz" this document's
earlier revision attributed to the V2 is the V3/V4 product-page figure.
A V3+ probe is the lever if >120 MHz TRACECLK is ever truly needed. The
board itself is clean at every rate the probe can sample.

### Fly-wire-era workaround re-validation (2026-08-21, same day)

Treating every fly-wire-era result as untrusted, each firmware workaround
was A/B-tested on this board (cdc_msc enumeration burst, 3/3 acceptance):

- **TIMER DBGPAUSE clear — removed.** Captures profile healthy running
  firmware without it; the fly-wire-era "sleep_ms spins forever" wedge
  does not reproduce on good hardware.
- **12 mA fast-slew trace pads — removed.** Default pads pass 3/3 at the
  same +1 ns sampling with a *wider* idle eye (−1000..+2000 ps).
- **"Runtime clock switch kills trace" — confirmed, refined.** A
  board_init-time 120→156 MHz step silently truncates the capture at the
  switch (decode ends inside `check_sys_clock_khz`, no decoder error,
  3/3) — hence the clock stays pinned from crt0.

Final firmware trace footprint on RP2350: one conditional (TX-only UART
console, GPIO1 = TRACECLK). Everything else is J-Link's built-in device
script plus the committed Ozone reference (156 MHz, +1 ns sampling).

## Known SI limitation (document honestly)

The bottom GND pour has **~0.9–1.2 mm gaps directly beneath all five trace
signals** where they cross `J1B`'s through-hole row: 1.7 mm THT pads at
2.54 mm pitch leave ~0.22 mm of pour between pads, below the 0.2 mm minimum
fill thickness, so the zone filler prunes that band rather than leaving a
sliver of unsupported copper.

This forces a return-path detour around each gap. Worst case is **TD2 at
≈5.25 mm**; TRACECLK/TD0 are ≈0.15–0.2 mm; TD1/TD3 are ≈2.7 mm. Assessed
**acceptable**: the crossing is perpendicular to the trace bundle (not a
running-parallel gap), and the worst-case detour is ~30 ps against 1–2 ns
signal edges. **Listed here as suspect #1 if high-rate trace decode fails**
— the fix, if ever needed, is to relocate or thin the `J1B` breakout row so
it no longer crosses the trace group.

Separately: the 2-layer stackup means **no controlled 50 Ω impedance**
anywhere on the board (a 4-layer stackup would be needed for that). The
trace runs are electrically short (~24 mm, ~144 ps one-way) so reflections
are dominated by the 27 Ω source termination at the Pico socket pins, not
by the uncontrolled-impedance trace geometry.

## Pre-fab checklist

Confirm before ordering:

- [ ] `J3`/`J6` shrouded-header sourcing: the chosen part is **SMD, not
      THT** — many cheap 1.27 mm shrouded headers are THT and will not fit.
- [ ] `J3`/`J6` shroud body size checked against the FTSH-110/FTSH-105
      drawing the footprint is dimensioned from — a larger clone body can
      foul neighbouring connectors on the debug edge (measured margin:
      `J6`↔`J10` courtyard gap is 0.700 mm, `J10`↔`J7` is 0.670 mm).
- [ ] `J3`/`J6` shroud is **keyed** so the J-Trace ribbon cannot be
      inserted backwards.
- [x] Board ≤100 mm on its longest edge (92.1 mm bbox / 92.0 mm
      centreline) — qualifies for JLC's cheap prototype tier.
- [x] 2-layer.

## Firmware / BSP interface

GPIO map (`hw/bsp/rp2040/boards/raspberry_pi_pico2`, see DESIGN.md §6/§11
for the full rationale):

| Function | GPIO(s) |
| --- | --- |
| Trace (TRACECLK/TD0–3, funcsel 9) | GP1–GP5 |
| GND guards (`JP2`/`JP3`) | GP0, GP6 |
| UART0 console (TX/RX) | GP12, GP13 |
| I2C0 (STEMMA-QT, SDA/SCL) | GP8, GP9 |
| PIO-USB host (D+/D−, `J5`) | GP20, GP21 |
| PIO-USB device (D+/D−, `J9`) | GP18, GP19 |
| `DEV_DP_PU_EN` — device D+ pull-up soft-connect | GP11 |
| Native VBUS-detect tap | GP16 |
| J9 device VBUS-detect | GP27 |

> GP27 threshold note (2026-07-30 review): with J9 unplugged, driving
> DEV_DP high (or enabling the GP11 pull-up) back-feeds `J9_VBUS` to
> ~2.6 V through ESD_D's I/O→VBUS steering diode, putting ~1.3 V on
> GP27. Treat "VBUS present" as `GP27 ≥ ~2 V` (divider gives 2.5 V at
> a real 5 V VBUS), never "nonzero".
| Host VBUS enable                                | GP17       |
| Host VBUS fault (open-drain)                    | GP15       |
| `ISENSE` — VBUS current-sense (ADC)             | GP26       |
| User LED                                        | GP10       |
| User button                                     | GP14       |

Keep GP0/GP6 as inputs whenever their guard jumper is fitted (driving them
against a grounded guard is a short). GP1–GP5 carry nothing else — no
pulls, LEDs, or other loading beyond the trace path.

`GP15` (`HOST_VBUS_FLT`) is the load switch's open-drain fault output
with **no external pull-up on the board** — the net ties only `PICO.20`
and `U_HSW.FLG`, nothing else. Firmware must enable the RP2350's
**internal** pull-up on this pin to read it; left as a bare input it will
float.

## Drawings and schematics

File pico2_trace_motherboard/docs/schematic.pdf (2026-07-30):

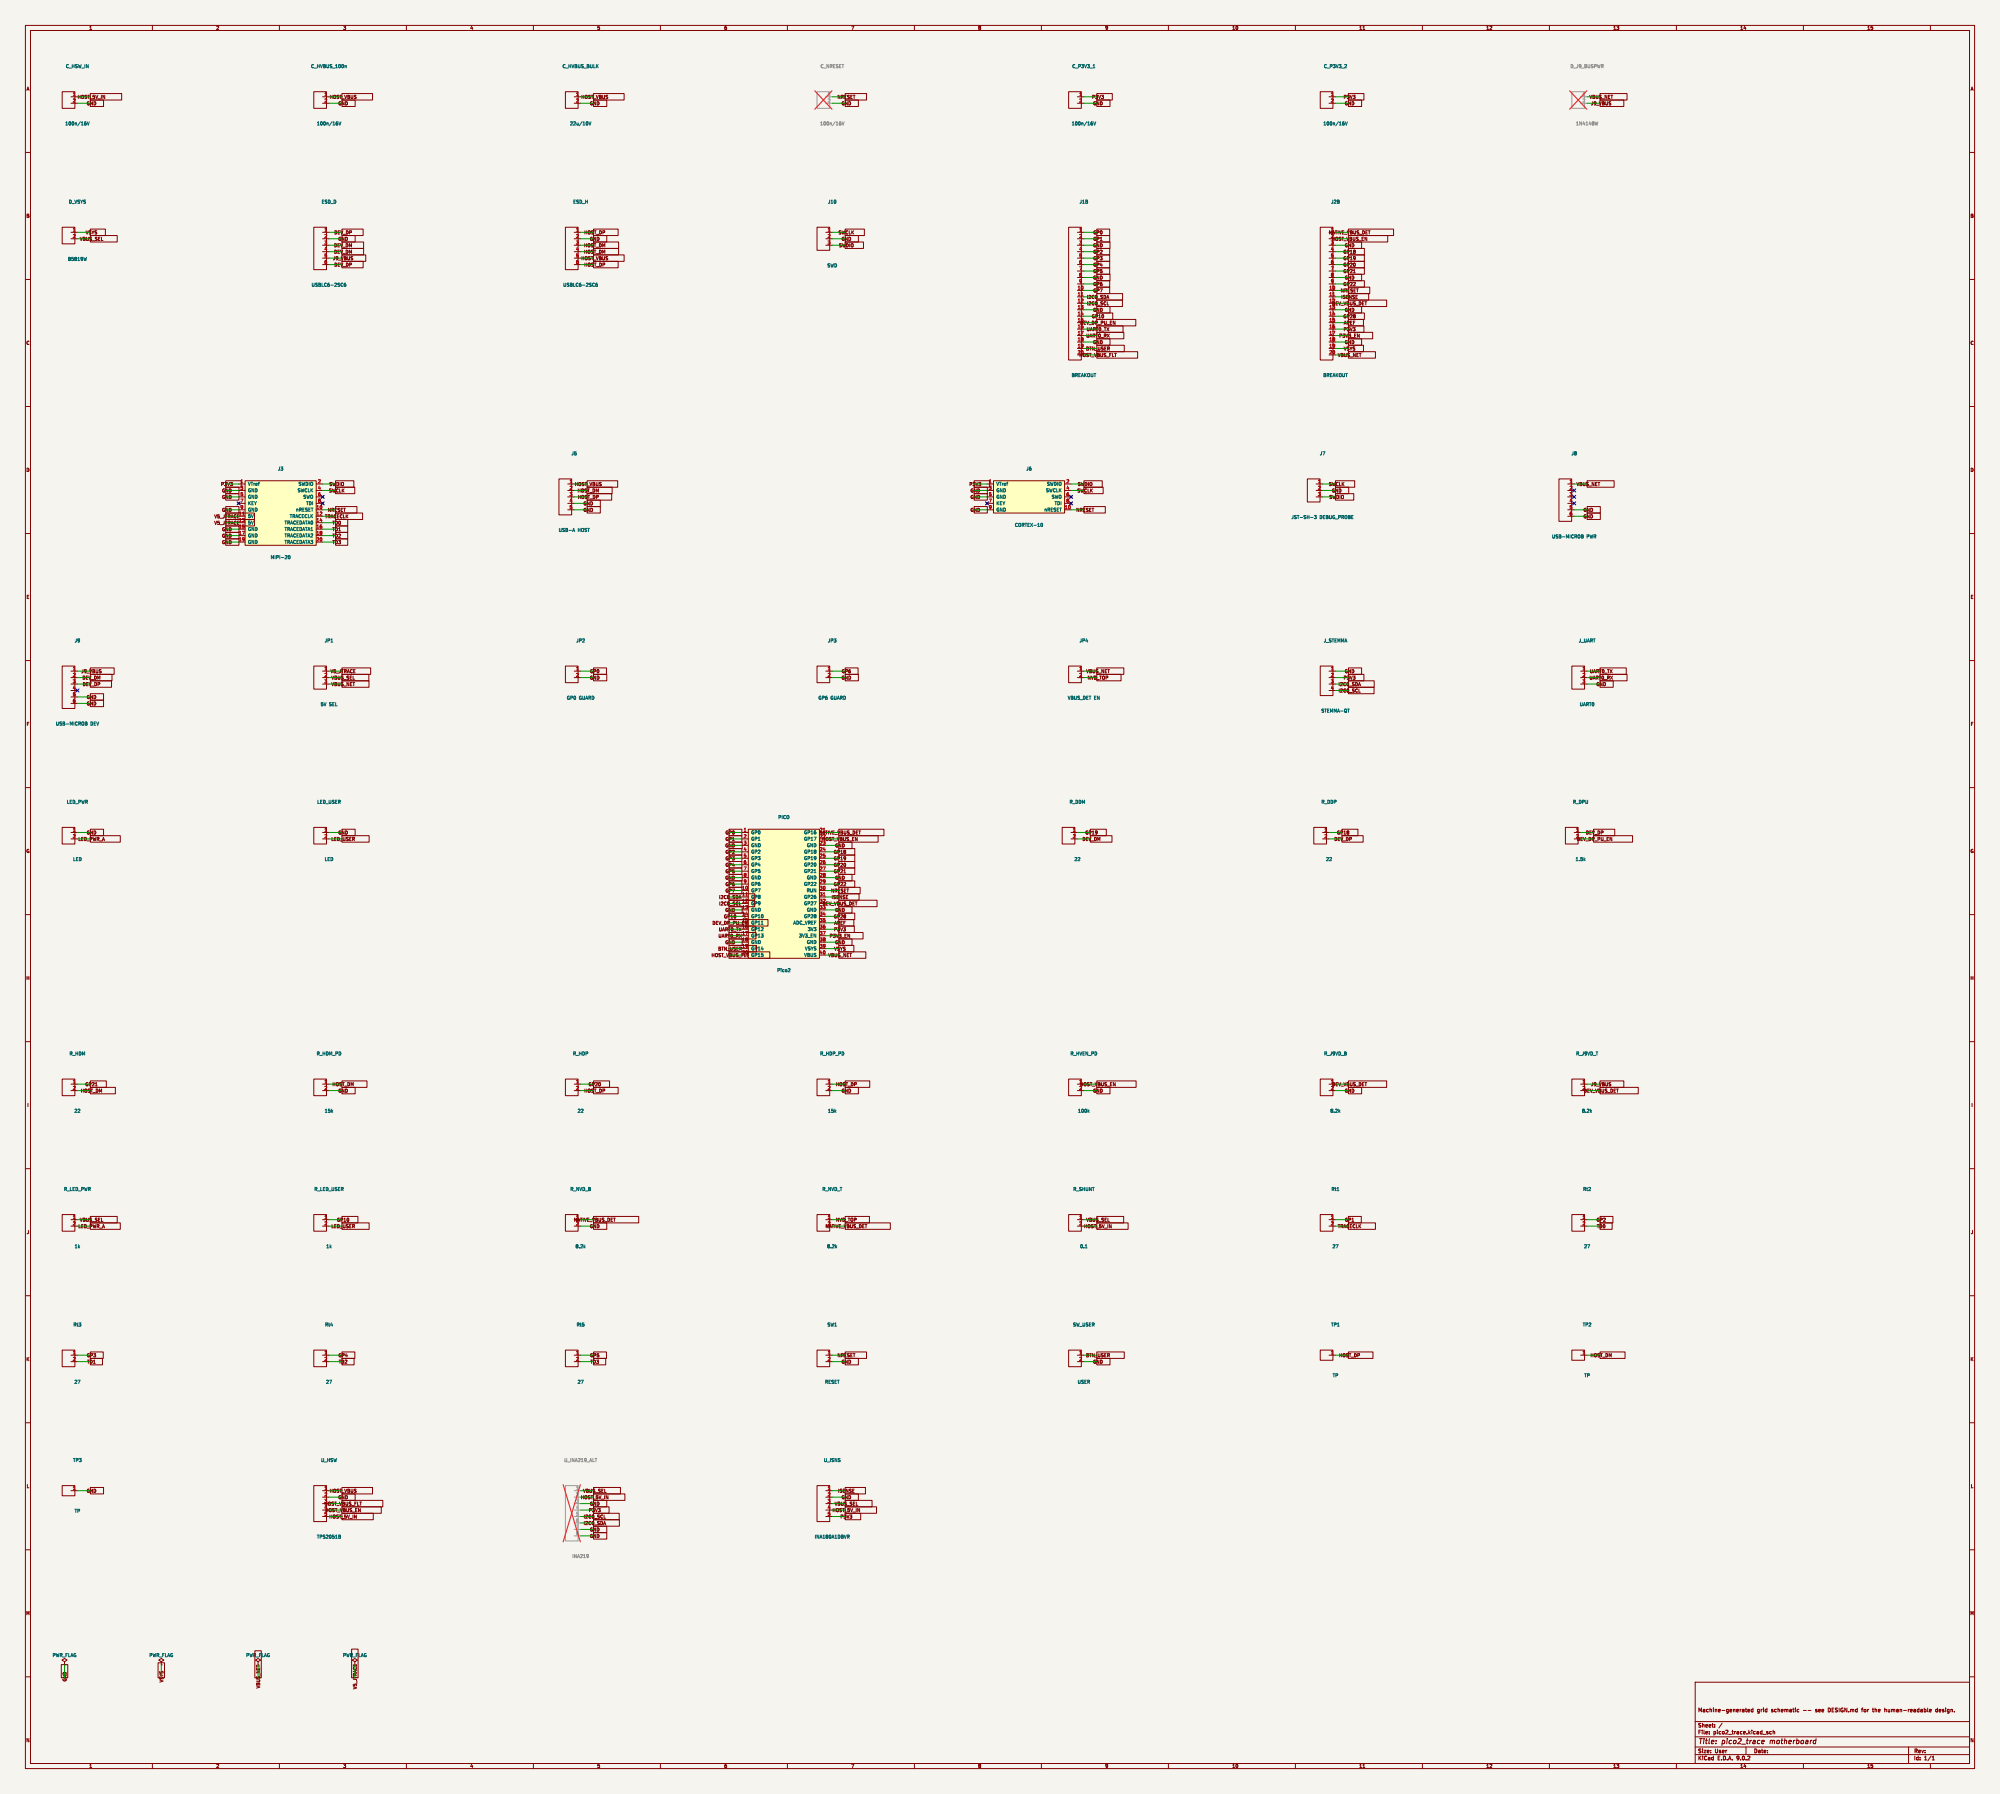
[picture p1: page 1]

VTref 1 GND 3 GND 5 KEY 7 GND 9

3V3_EN 37 GND 38 VSYS 39 VBUS 40 PICO

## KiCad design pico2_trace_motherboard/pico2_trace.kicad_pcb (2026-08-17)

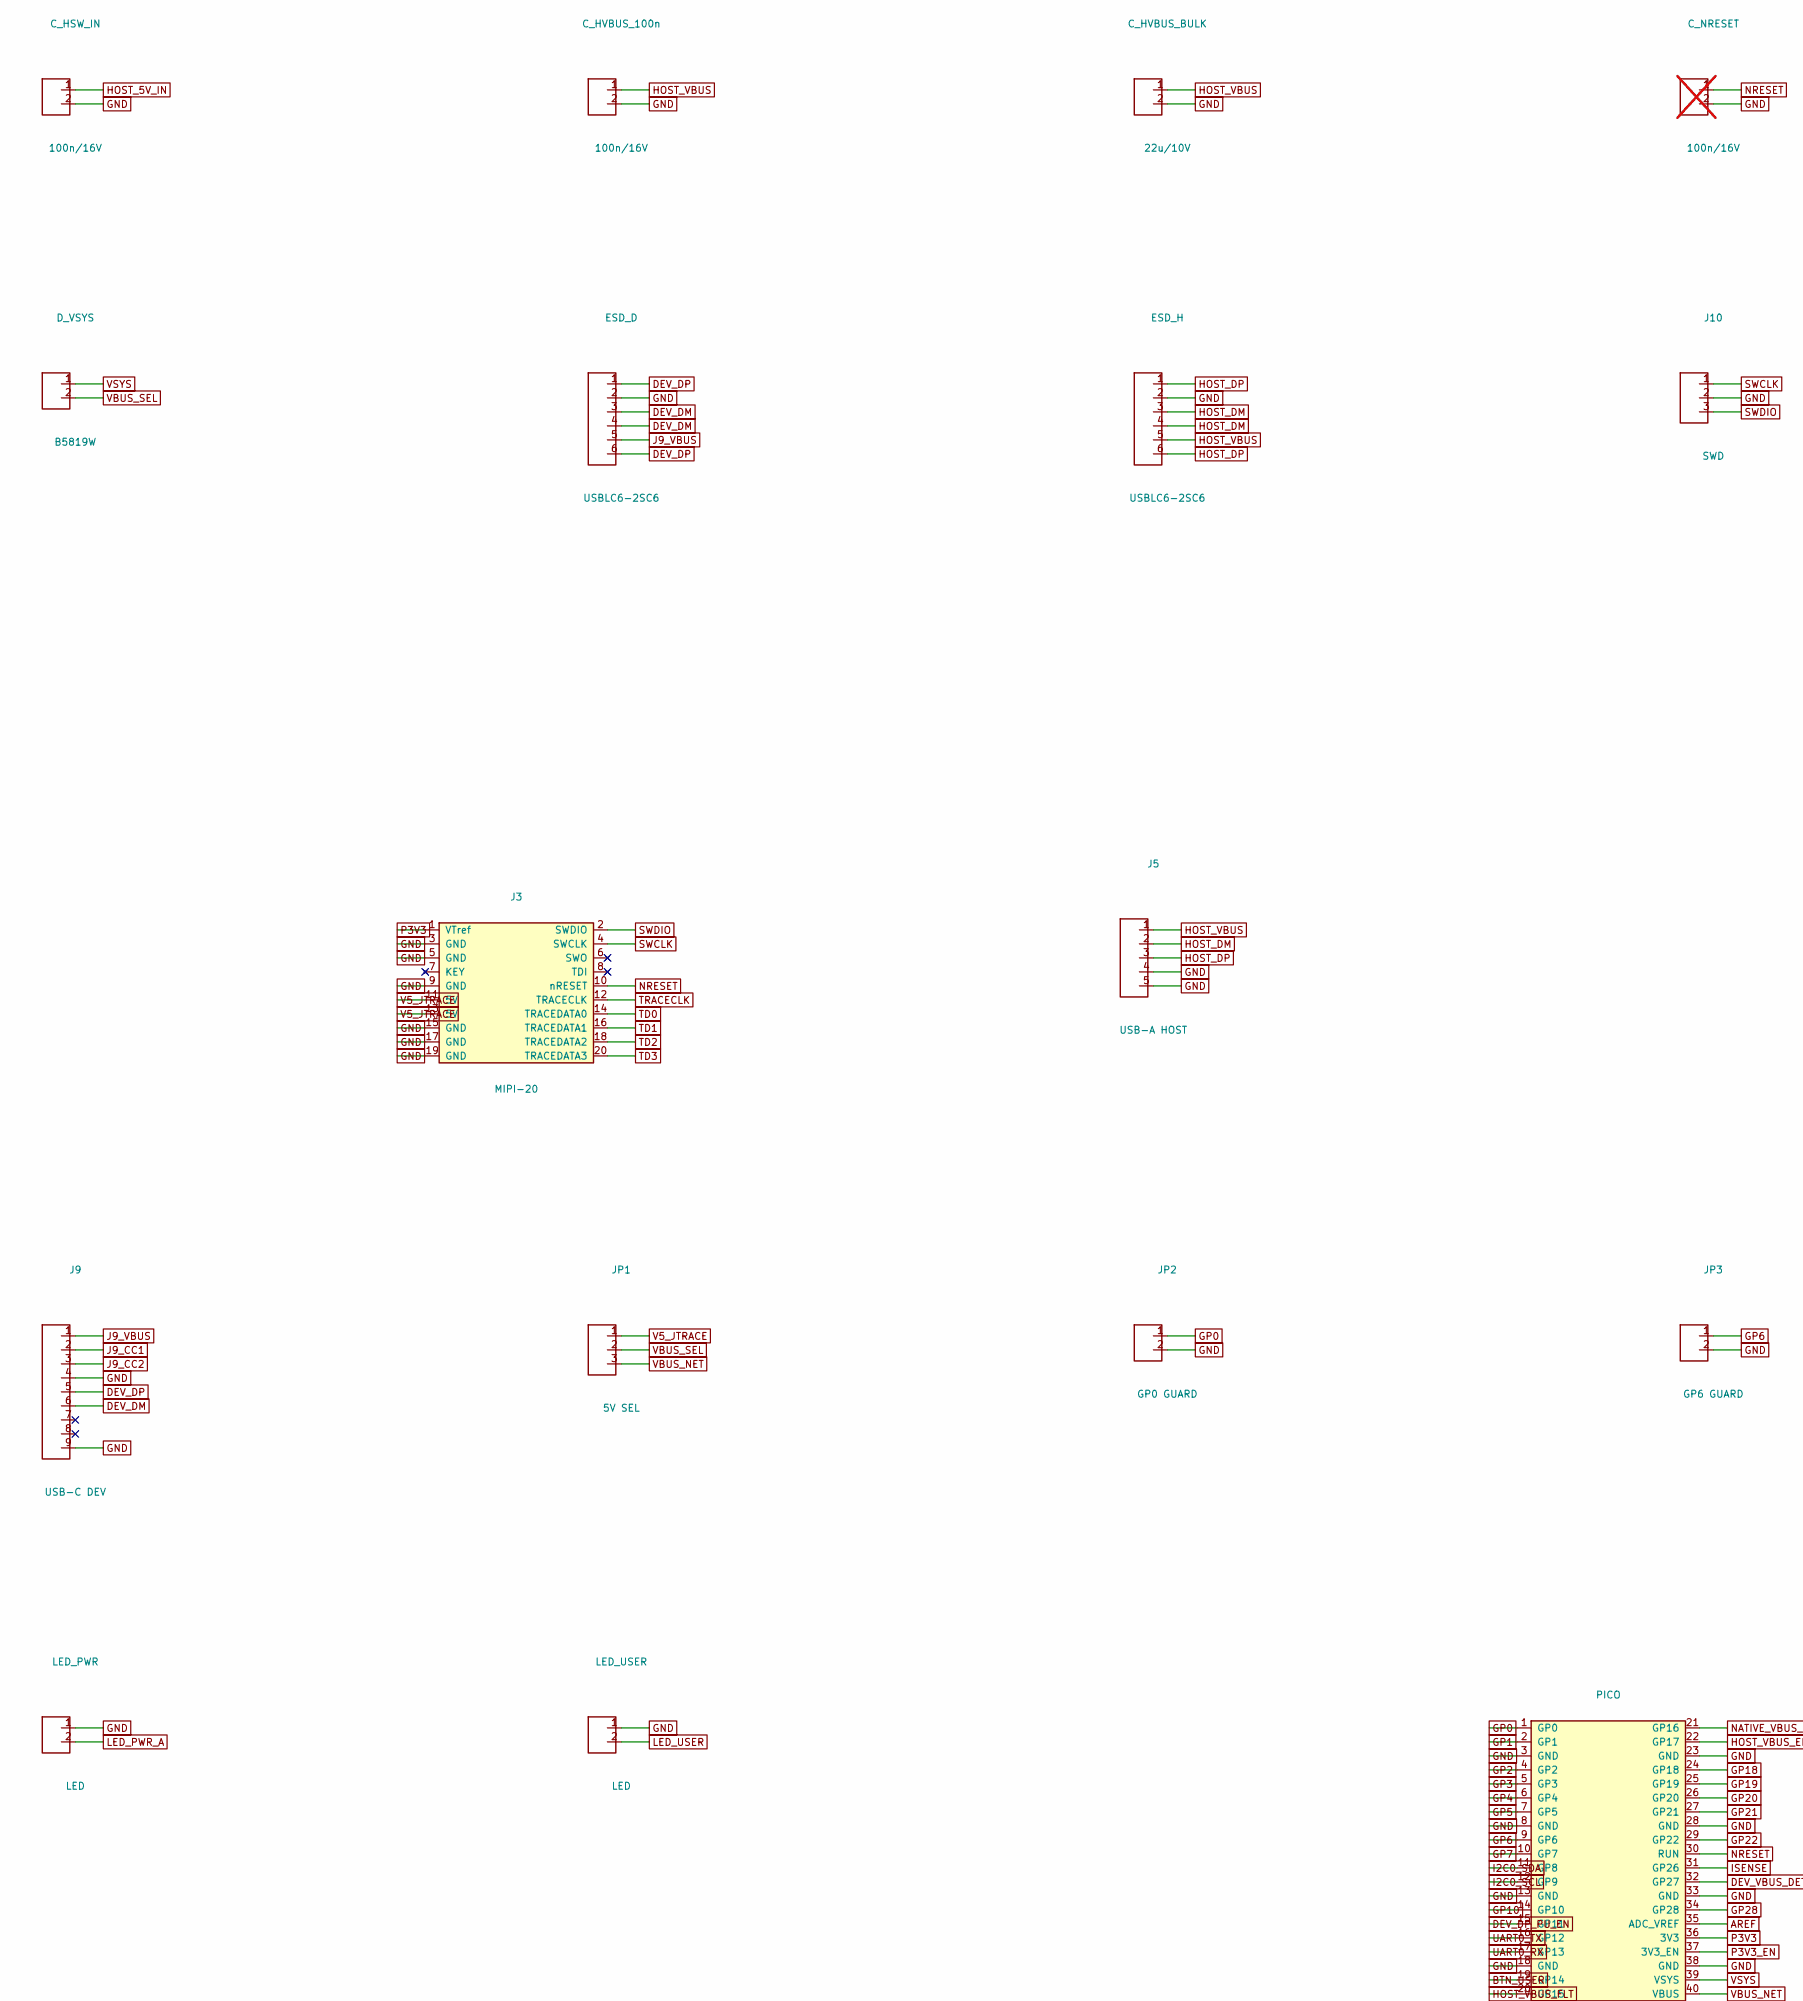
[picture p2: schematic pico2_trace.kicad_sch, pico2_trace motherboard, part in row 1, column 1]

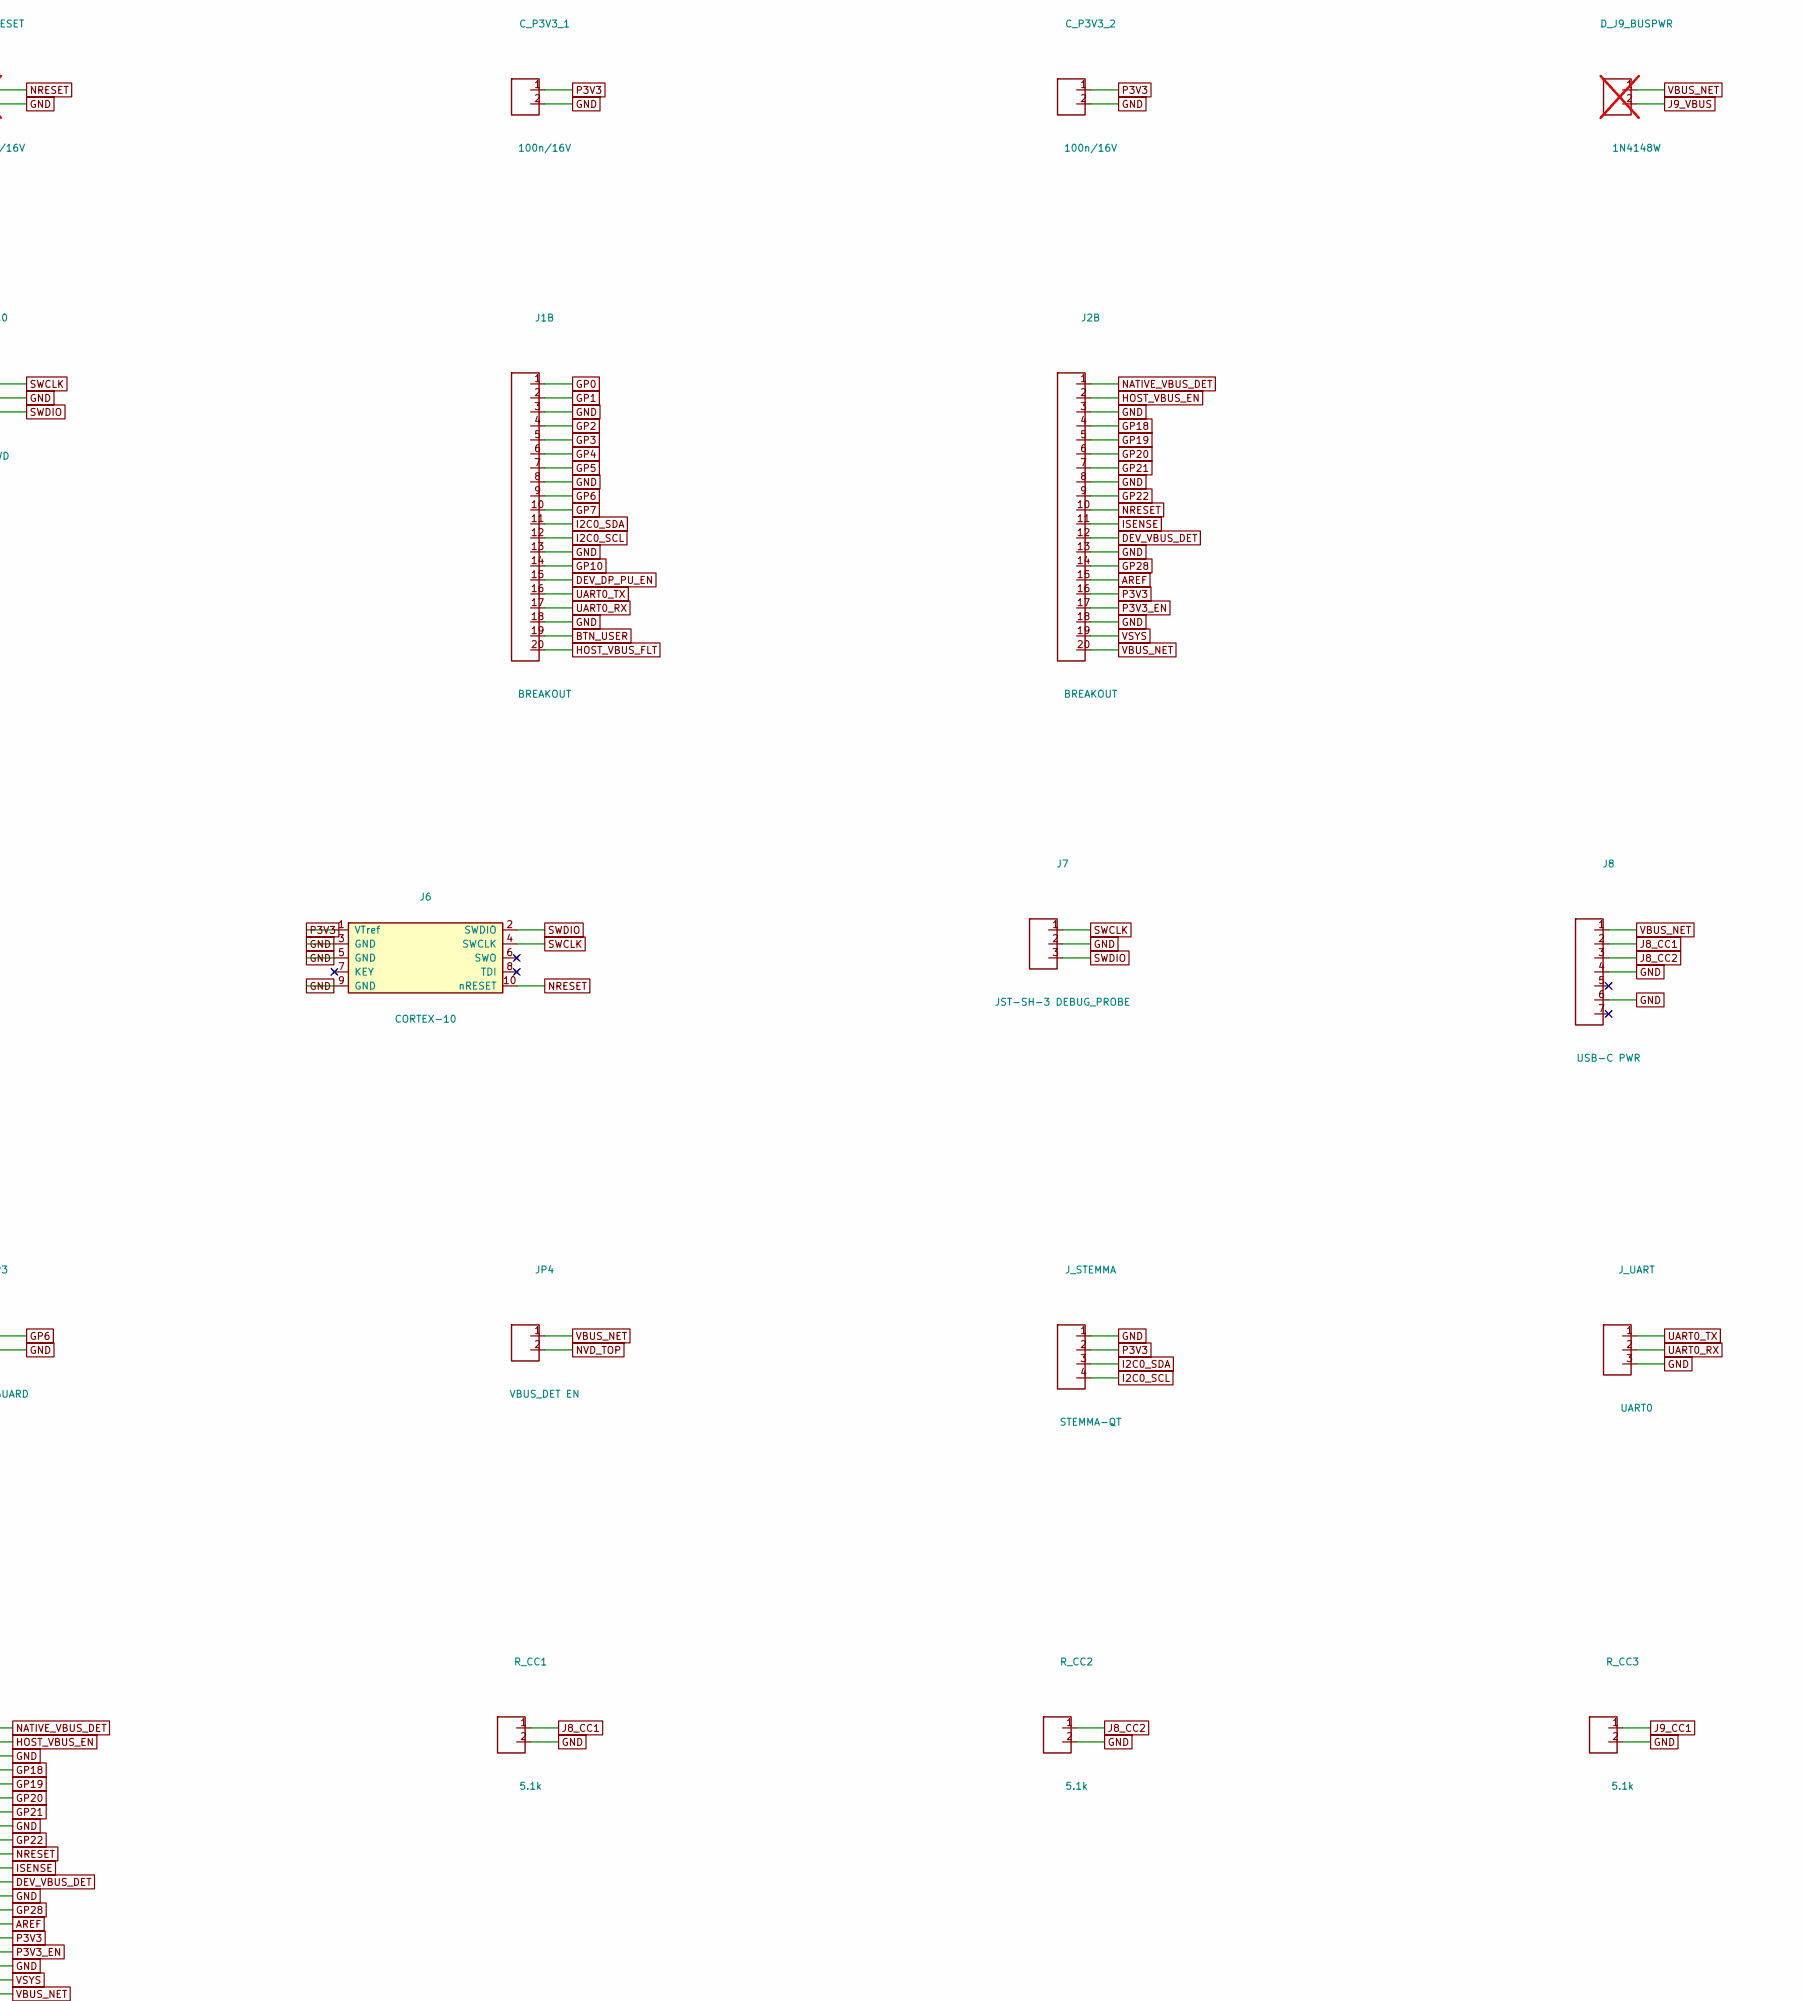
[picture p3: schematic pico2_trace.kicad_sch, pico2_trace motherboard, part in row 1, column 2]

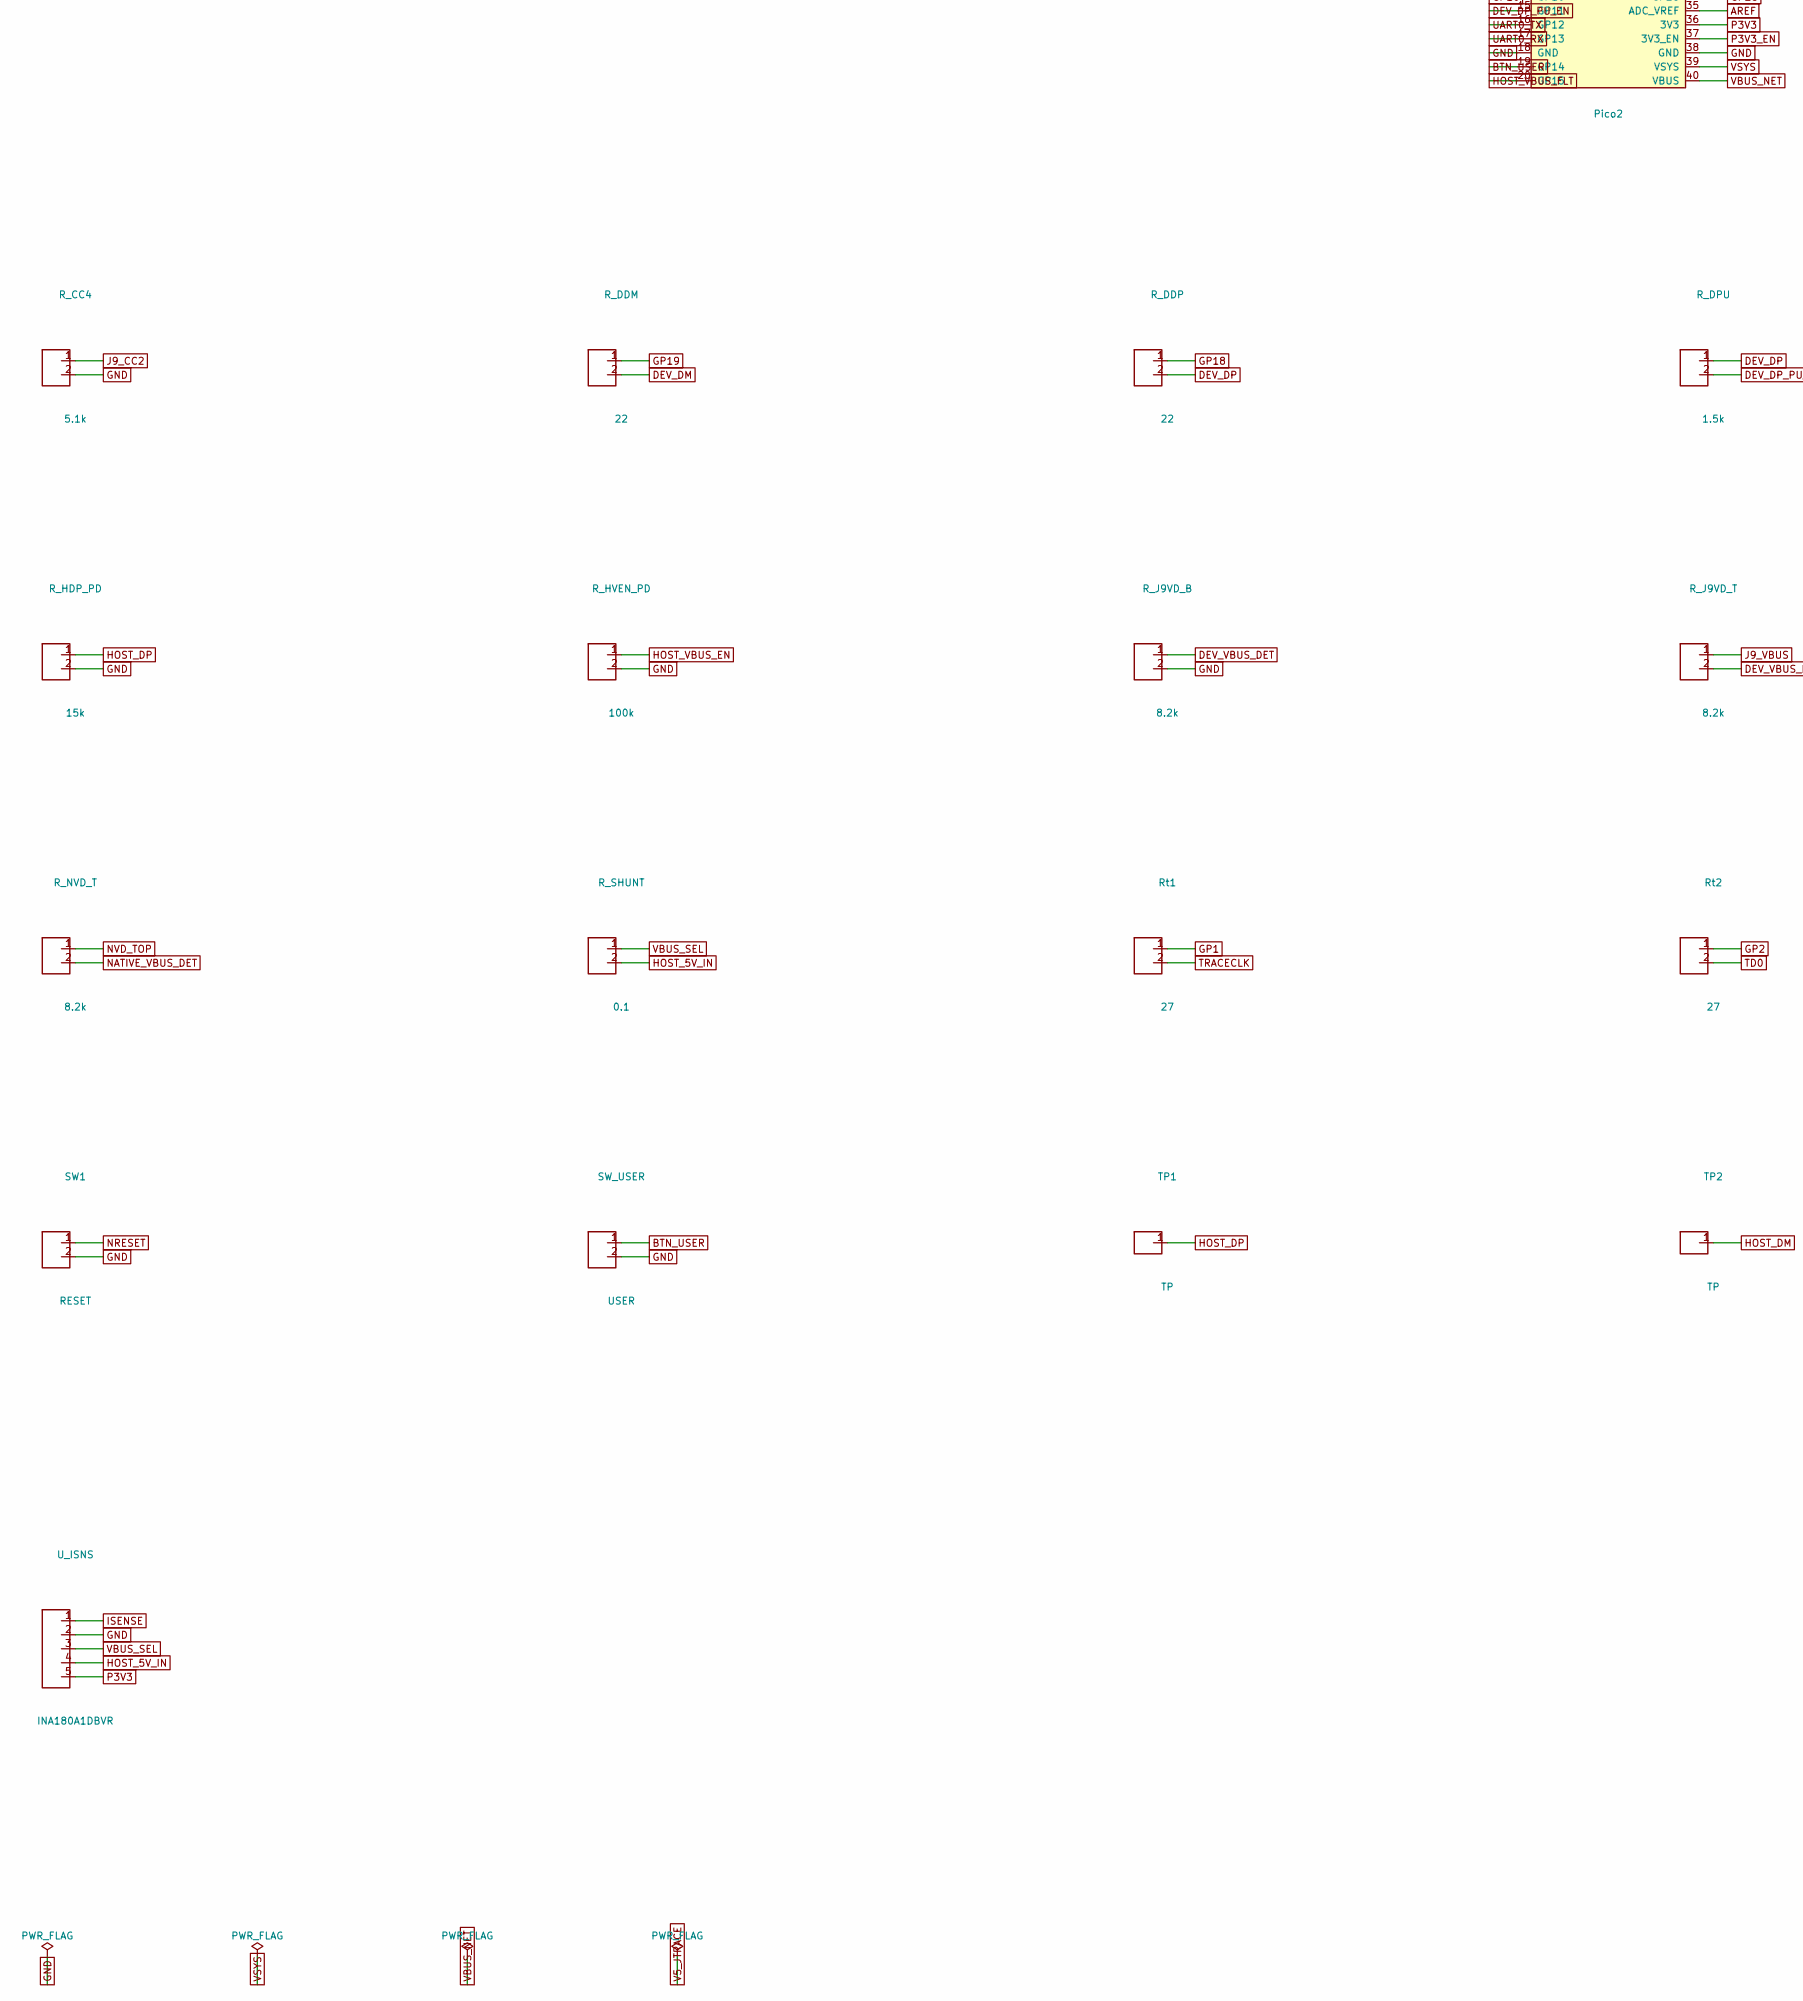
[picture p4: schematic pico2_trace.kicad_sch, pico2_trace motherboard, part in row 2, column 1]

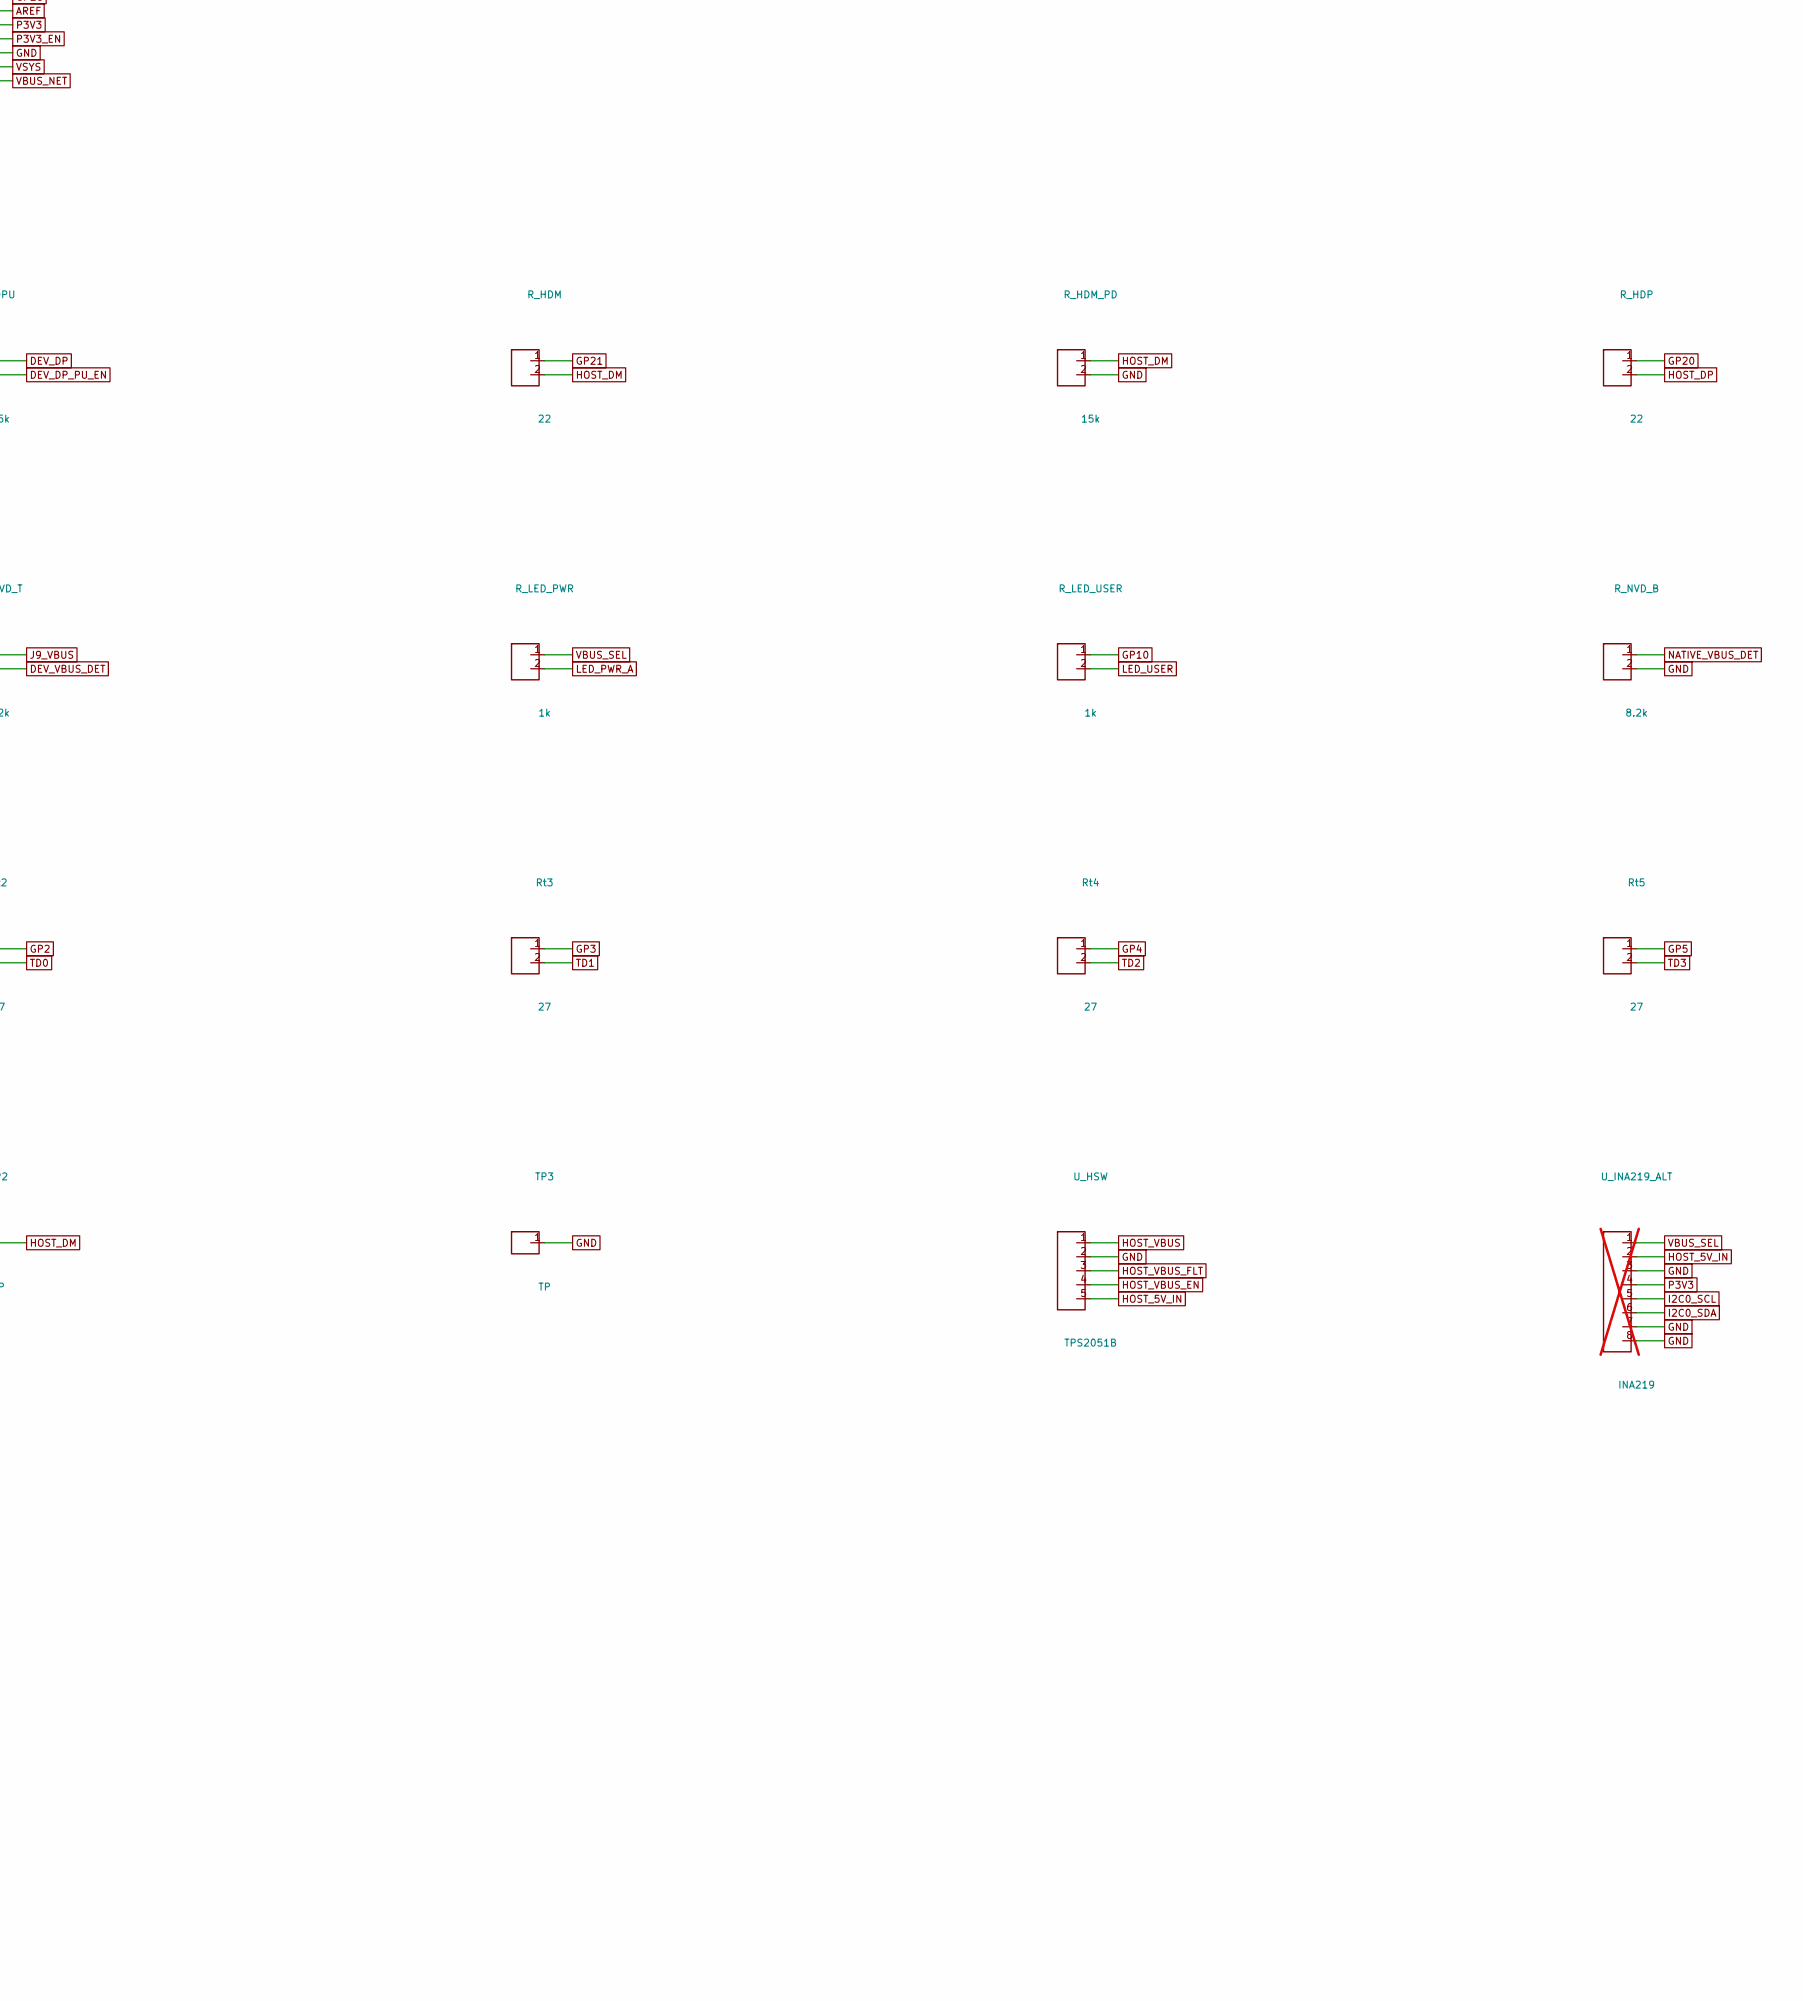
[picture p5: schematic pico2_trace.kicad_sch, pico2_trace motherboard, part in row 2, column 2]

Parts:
C_HSW_IN: 100n/16V; C_0402_1005Metric
C_HVBUS_100n: 100n/16V; C_0402_1005Metric
C_HVBUS_BULK: 22u/10V; C_0805_2012Metric
C_NRESET: 100n/16V; C_0402_1005Metric; not fitted
C_P3V3_1, C_P3V3_2: 100n/16V; C_0402_1005Metric
D_J9_BUSPWR: 1N4148W; D_SOD-123; not fitted
D_VSYS: B5819W; D_SOD-123
ESD_D: USBLC6-2SC6; SOT-23-6
ESD_H: USBLC6-2SC6; SOT-23-6
J1B, J2B: BREAKOUT; PinSocket_1x20_P2.54mm_Vertical
J3: MIPI-20; FTSH-110-01-DV
J5: USB-A HOST; USB_A_Receptacle_GCT_USB1046
J6: CORTEX-10; FTSH-105-01-DV
J7: JST-SH-3 DEBUG_PROBE; JST_SH_SM03B-SRSS-TB_1x03-1MP_P1.00mm_Horizontal
J8: USB-C PWR; USB_C_PWR_HRO_TYPE-C-31-M-12
J9: USB-C DEV; USB_C_DEV_HRO_TYPE-C-31-M-12
J10: SWD; PinHeader_1x03_P2.54mm_Vertical
JP1: 5V SEL; PinHeader_1x03_P2.54mm_Vertical
JP2: GP0 GUARD; PinHeader_1x02_P2.54mm_Vertical
JP3: GP6 GUARD; PinHeader_1x02_P2.54mm_Vertical
JP4: VBUS_DET EN; PinHeader_1x02_P2.54mm_Vertical
J_STEMMA: STEMMA-QT; JST_SH_SM04B-SRSS-TB_1x04-1MP_P1.00mm_Horizontal
J_UART: UART0; PinHeader_1x03_P2.54mm_Vertical
LED_PWR: LED; LED_0603_1608Metric
LED_USER: LED; LED_0603_1608Metric
PICO: Pico2; RaspberryPi_Pico_Common_THT
R_CC1, R_CC2, R_CC3, R_CC4: 5.1k; R_0402_1005Metric
R_DDM: 22; R_0402_1005Metric
R_DDP: 22; R_0402_1005Metric
R_DPU: 1.5k; R_0402_1005Metric
R_HDM: 22; R_0402_1005Metric
R_HDM_PD: 15k; R_0402_1005Metric
R_HDP: 22; R_0402_1005Metric
R_HDP_PD: 15k; R_0402_1005Metric
R_HVEN_PD: 100k; R_0402_1005Metric
R_J9VD_B, R_J9VD_T: 8.2k; R_0402_1005Metric
R_LED_PWR: 1k; R_0402_1005Metric
R_LED_USER: 1k; R_0402_1005Metric
R_NVD_B: 8.2k; R_0402_1005Metric
R_NVD_T: 8.2k; R_0402_1005Metric
R_SHUNT: 0.1; R_1206_3216Metric
Rt1, Rt2, Rt3, Rt4, Rt5: 27; R_0402_1005Metric
SW1: RESET; SW_SPST_B3S-1000
SW_USER: USER; SW_SPST_B3S-1000
TP1, TP2, TP3: TP; TestPoint_Pad_D1.5mm
U_HSW: TPS2051B; SOT-23-5
U_INA219_ALT: INA219; SOT-23-8; not fitted
U_ISNS: INA180A1DBVR; SOT-23-5

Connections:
AREF: J2B.15, PICO.35 (ADC_VREF)
BTN_USER: J1B.19, PICO.19 (GP14), SW_USER.1
DEV_DM: ESD_D.3, ESD_D.4, J9.6, R_DDM.2
DEV_DP: ESD_D.1, ESD_D.6, J9.5, R_DDP.2, R_DPU.1
DEV_DP_PU_EN: J1B.15, PICO.15 (GP11), R_DPU.2
DEV_VBUS_DET: J2B.12, PICO.32 (GP27), R_J9VD_B.1, R_J9VD_T.2
GP0: J1B.1, JP2.1, PICO.1 (GP0)
GP1: J1B.2, PICO.2 (GP1), Rt1.1
GP2: J1B.4, PICO.4 (GP2), Rt2.1
GP3: J1B.5, PICO.5 (GP3), Rt3.1
GP4: J1B.6, PICO.6 (GP4), Rt4.1
GP5: J1B.7, PICO.7 (GP5), Rt5.1
GP6: J1B.9, JP3.1, PICO.9 (GP6)
GP7: J1B.10, PICO.10 (GP7)
GP10: J1B.14, PICO.14 (GP10), R_LED_USER.1
GP18: J2B.4, PICO.24 (GP18), R_DDP.1
GP19: J2B.5, PICO.25 (GP19), R_DDM.1
GP20: J2B.6, PICO.26 (GP20), R_HDP.1
GP21: J2B.7, PICO.27 (GP21), R_HDM.1
GP22: J2B.9, PICO.29 (GP22)
GP28: J2B.14, PICO.34 (GP28)
HOST_5V_IN: C_HSW_IN.1, R_SHUNT.2, U_HSW.5, U_INA219_ALT.2, U_ISNS.4
HOST_DM: ESD_H.3, ESD_H.4, J5.2, R_HDM.2, R_HDM_PD.1, TP2.1
HOST_DP: ESD_H.1, ESD_H.6, J5.3, R_HDP.2, R_HDP_PD.1, TP1.1
HOST_VBUS: C_HVBUS_100n.1, C_HVBUS_BULK.1, ESD_H.5, J5.1, U_HSW.1
HOST_VBUS_EN: J2B.2, PICO.22 (GP17), R_HVEN_PD.1, U_HSW.4
HOST_VBUS_FLT: J1B.20, PICO.20 (GP15), U_HSW.3
I2C0_SCL: J1B.12, J_STEMMA.4, PICO.12 (GP9), U_INA219_ALT.5
I2C0_SDA: J1B.11, J_STEMMA.3, PICO.11 (GP8), U_INA219_ALT.6
ISENSE: J2B.11, PICO.31 (GP26), U_ISNS.1
J8_CC1: J8.2, R_CC1.1
J8_CC2: J8.3, R_CC2.1
J9_CC1: J9.2, R_CC3.1
J9_CC2: J9.3, R_CC4.1
J9_VBUS: D_J9_BUSPWR.2, ESD_D.5, J9.1, R_J9VD_T.1
LED_PWR_A: LED_PWR.2, R_LED_PWR.2
LED_USER: LED_USER.2, R_LED_USER.2
NATIVE_VBUS_DET: J2B.1, PICO.21 (GP16), R_NVD_B.1, R_NVD_T.2
NRESET: C_NRESET.1, J2B.10, J3.10 (nRESET), J6.10 (nRESET), PICO.30 (RUN), SW1.1
NVD_TOP: JP4.2, R_NVD_T.1
P3V3: C_P3V3_1.1, C_P3V3_2.1, J2B.16, J3.1 (VTref), J6.1 (VTref), J_STEMMA.2, PICO.36 (3V3), U_INA219_ALT.4, U_ISNS.5
P3V3_EN: J2B.17, PICO.37 (3V3_EN)
SWCLK: J3.4 (SWCLK), J6.4 (SWCLK), J7.1, J10.1
SWDIO: J3.2 (SWDIO), J6.2 (SWDIO), J7.3, J10.3
TD0: J3.14 (TRACEDATA0), Rt2.2
TD1: J3.16 (TRACEDATA1), Rt3.2
TD2: J3.18 (TRACEDATA2), Rt4.2
TD3: J3.20 (TRACEDATA3), Rt5.2
TRACECLK: J3.12 (TRACECLK), Rt1.2
UART0_RX: J1B.17, J_UART.2, PICO.17 (GP13)
UART0_TX: J1B.16, J_UART.1, PICO.16 (GP12)
VBUS_SEL: D_VSYS.2, JP1.2, R_LED_PWR.1, R_SHUNT.1, U_INA219_ALT.1, U_ISNS.3

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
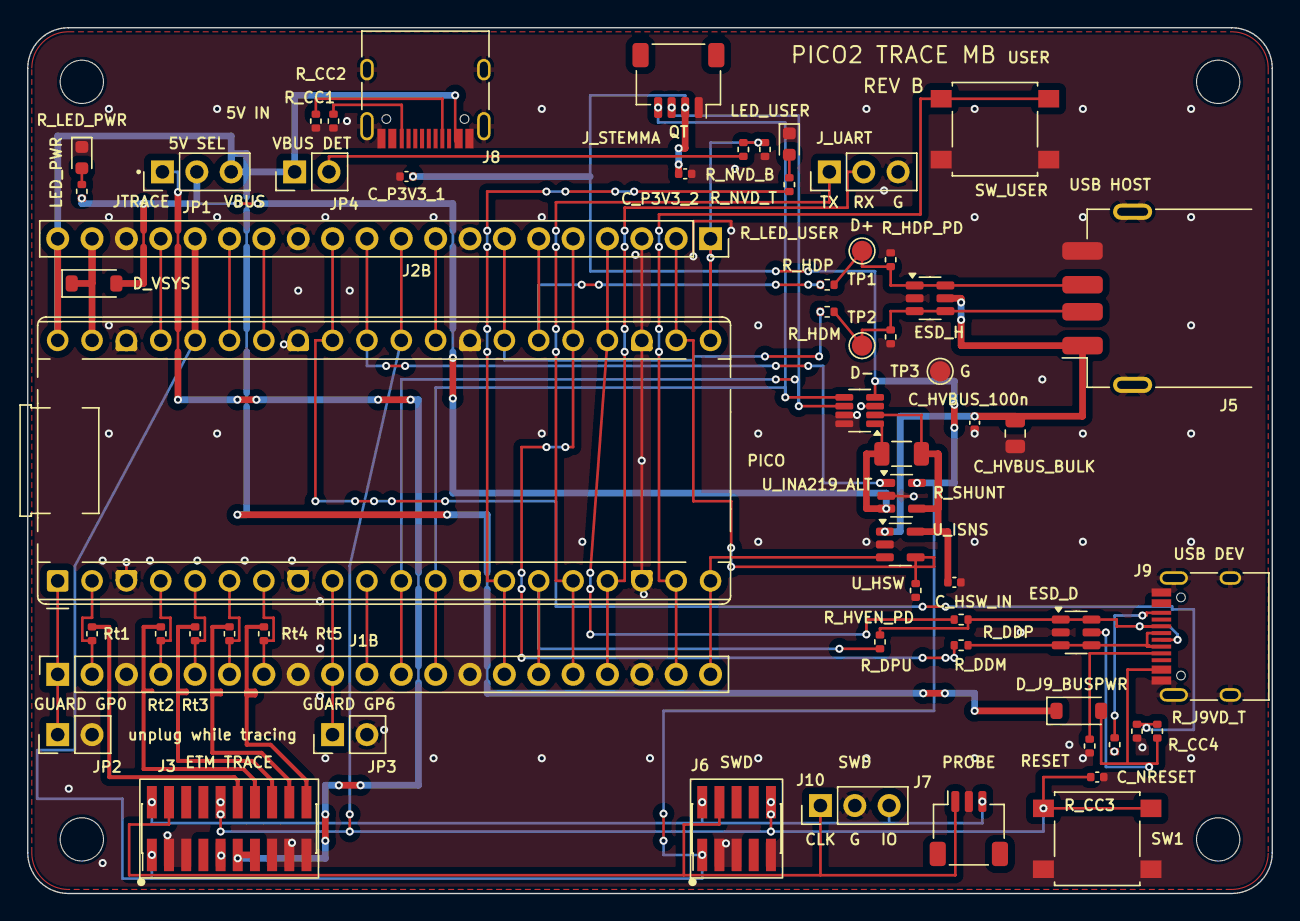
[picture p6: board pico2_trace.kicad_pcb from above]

Board: 2 copper layers, 92.0 x 64.0 mm, 64 parts (0 on the bottom side), 56 nets.

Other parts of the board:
MH1, MH2, MH3, MH4: MountingHole_3.2mm_M3

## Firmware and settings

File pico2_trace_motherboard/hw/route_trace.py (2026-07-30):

"""pcbnew driver: route the SI-critical trace bundle + the SWD/NRESET/VTref
tree (Task 13).

Run: python3 hw/route_trace.py

Routes, on the board saved by `hw/build_board.py --place`:

  - TRACECLK, TD0-3 (+ source-side GP1-5): F_Cu only, Trace-class width
    (0.3mm), no vias (SI rule -- DESIGN.md SS5.4). Each Rt->J3 run must
    cross the J1B breakout row's own THT pads (1.7x1.7mm at 2.54mm pitch,
    so only ~0.84mm gaps between columns) -- each net jogs sideways by one
    PICO-pin-pitch to land in an adjacent gap before descending. Rt1/
    TRACECLK jogs toward its nearer gap (the *shortest* natural Rt->J3
    run of the five, ~17.7mm); Rt2-5 deliberately jog the OTHER way (a
    "wrong-way" detour) to burn extra length and close most of the
    natural spread; a length-matching meander (see `_meander`) tops each
    up to Rt1's length exactly (spread ~0.0mm, see task-13-report.md).
    Each net's GP-segment jog direction is the OPPOSITE of its own TDx
    jog, so the two paths -- which share the ~1mm y-band between Rt's
    two pads -- diverge instead of crossing.

  - SWDIO, SWCLK: daisy chain J3-J6-J7 via a B_Cu trunk.
  - NRESET: PICO.30 -> J3.10 -> J6.10 -> SW1.1 via B_Cu.
  - P3V3 (VTref taps only -- the rest of this net is Task 14's job):
    PICO.36 -> J3.1 -> J6.1 via B_Cu, necked to Default width (0.2mm) for
    the PICO/J1B header-row crossing (0.5mm does not fit an 0.84mm
    pin-pitch gap with clearance to spare: 0.17mm < 0.2mm required; 0.2mm
    clears with margin, 0.32mm).

  B_Cu is used for all four of these because J3/J6/J7/SW1 are all SMD
  (F_Cu-only) -- B_Cu is unobstructed under them; only the THT parts
  PICO/J1B/J2B/JP2/JP3 carry B_Cu copper, and only PICO's own header row
  and J1B's breakout row lie on the NRESET/P3V3 descent from PICO (each
  crossed once, through an unused inter-pin gap, same technique as the
  trace bundle). SWDIO and SWCLK share the same 3 physical connectors, so
  a "shallower" net's full-width B_Cu trunk is unavoidably crossed by a
  "deeper" net's vertical pad-to-trunk run wherever their X ranges
  overlap (they mostly do, since all three connectors are shared) --
  `_spike_to_trunk` hops each such crossing onto F_Cu (clear in this
  region -- verified empty of copper except a mounting hole far to the
  west) for a short span and back, via two vias.

Idempotent: skip-if-already-routed -- before adding tracks/vias for a
net, check whether it already has any (BOARD.GetTracks() returns both
PCB_TRACK and PCB_VIA, since PCB_VIA subclasses PCB_TRACK), so re-running
is a no-op. Matches place.py/build_board.py's skip-if-present pattern;
never BOARD.Remove() (see build_board.py's docstrings for why).
"""

from __future__ import annotations

import os
import sys

if __name__ == "__main__":
    sys.path.insert(0, os.path.dirname(os.path.dirname(os.path.abspath(__file__))))

import pcbnew

BOARD_FILE = "pico2_trace.kicad_pcb"

# --- Trace bundle ------------------------------------------------------------
# rt_ref, gp_net, td_net, pico_pad (source), j3_pad (dest),
# jog_dir (+1 = jog toward the higher-numbered neighboring PICO pin,
# -1 = toward the lower), meander_passes (length-matching, see _meander).
_TRACE_CHAIN = [
    ("Rt1", "GP1", "TRACECLK", "2", "12", +1, 0),
    ("Rt2", "GP2", "TD0", "4", "14", -1, 1),
    ("Rt3", "GP3", "TD1", "5", "16", -1, 2),
    ("Rt4", "GP4", "TD2", "6", "18", -1, 3),
    ("Rt5", "GP5", "TD3", "7", "20", -1, 4),
]

_GP_JOG_MM = 0.72         # clears Rt's own sibling pad (half-width 0.32mm +
                          # 0.25mm Trace clearance + 0.1mm half of a *0.2mm*
                          # GP track = 0.67mm min) *and* stays clear of the
                          # neighboring Rt's TDx lane-jog 1.27mm away (needs
                          # <=0.77mm) -- see task-13-report.md "GP jog width"
_GP_WIDTH_MM = 0.2        # GP segments (the short pre-termination stub, not
                          # the length-gated Rt->J3 run) are necked to
                          # Default width -- 0.3mm leaves *no* room between
                          # the two constraints above (both resolve to
                          # exactly 0.72mm, a zero-margin knife-edge)
_GP_APPROACH_MARGIN_MM = 0.4  # above Rt's far pad before jogging sideways
                              # (0.25mm Trace clearance + 0.1mm GP-track
                              # half-width + a bit of rounding margin)
_MEANDER_W_MM = 0.635     # meander tooth half-width -- 2*N*W is the exact
                          # extra length needed per net, derived below from
                          # each net's natural (unmeandered) length
_MEANDER_STEP_MM = 0.04   # vertical step between meander rungs -- same net
                          # on both sides of each rung, so no DRC clearance
                          # requirement applies; just small enough that the
                          # densest meander (5 passes, TD3) still fits before
                          # its own net's _CONV_START_OFFSETS_MM turn
_J1B_CLEAR_MARGIN_MM = 0.35   # below J1B pads' bottom edge before turning
# Per-net "start the final convergence" depth, as an offset *above* J3's
# pad-row top edge, indexed by each net's position in _TRACE_CHAIN (0 =
# TRACECLK .. 4 = TD3). Deliberately in *reverse* of natural dx (TRACECLK,
# with by far the largest lane->dest dx, starts deepest/latest; TD3, with
# almost no dx, starts shallowest/earliest) -- this keeps the 5 converging
# 45-degree-ish polylines strictly ordered (source lane order == dest pad
# order, preserved throughout, per task-13-report.md "final convergence")
# so none of them cross each other.
_CONV_START_OFFSETS_MM = [0.65, 1.25, 1.85, 2.45, 3.05]
_ROW_SAFE_MARGIN_MM = 0.4  # above J3's pad-row top edge: every net's
                           # straight-then-diagonal convergence must finish
                           # its *horizontal* motion by here, landing
                           # exactly on its own dest_x, before a final pure
                           # -vertical drop into the pad. J3's pads are
                           # ~2.4mm tall (not just "at" y=62.05) -- an
                           # earlier design that let the diagonal run all
                           # the way to the pad while still sweeping in X
                           # clipped straight through neighboring columns
                           # on the same row.

# --- SWD / NRESET / P3V3 tree -------------------------------------------------
# Task-14f re-placement note: J3/J6's pads are 2.4mm TALL (not wide --
# footprint rotation swaps W/H), so the two pin rows sit at y 56.05-58.45
# (north: SWDIO/SWCLK/-/-/NRESET/[trace bundle]) and y 59.95-62.35 (south:
# P3V3/GND/GND/-/GND/V5_JTRACE...), only 1.5mm apart. The board is also
# only 64.1mm tall, so "stack all 4 trunks south of SW1" (the pre-Task-14f
# strategy) no longer fits at all (SW1's own bottom pad edge is at
# y=62.855, leaving under 1mm before the 0.5mm board-edge-clearance
# limit) -- and even 3 B_Cu trunks sharing the 1.5mm inter-row gap don't
# DRC-clean (a hopping net's via, clipped to land at its own trunk_y,
# needs 0.6mm clearance -- via radius 0.3 + track halfwidth 0.1 +
# clearance 0.2 -- from EVERY other trunk it's near, and 3-way stacking
# in 1.5mm can't provide that everywhere).
#
# New strategy: SWDIO and NRESET are the *only* B_Cu nets through the
# tight inter-row gap (NRESET hopping over SWDIO via `_spike_to_trunk`'s
# shallower-trunk machinery -- proven DRC-clean: 0.3mm row-edge margin +
# 0.6mm+ via-vs-track clearance + 0.5mm+ via-vs-south-row margin, all
# inside 1.5mm with a few hundredths of a mm to spare). A *third* net
# sharing this gap on either layer always collides with one of the two:
# 3-way B_Cu stacking needs 0.3+0.6+0.6+0.5=2.0mm (only 1.5mm exists),
# and a constant-y F_Cu net collides with NRESET's hop bridge -- which,
# to physically get past SWDIO's B_Cu line, must itself occupy B_Cu
# across a ~1.3mm y-span centered on SWDIO's trunk, which is most of the
# gap's own height.
#
# So SWCLK and P3V3 skip the gap entirely -- both plain F_Cu, which
# never needs clearance against SWDIO/NRESET's B_Cu (different layer);
# they only need to dodge the *pads* they pass on the way down (the
# south row's own GND/P3V3 pads share SWCLK's J3/J6 columns) via a
# sideways jog while still between the two rows (open, unconstrained by
# pad pitch there), landing in a south-of-south-row F_Cu band
# (_SWD_LANE_Y) where SWCLK and P3V3 in turn need only ONE mutual hop
# (SWCLK is shallow and spans wider -- J3/J6/J7 -- so keeping it
# shallow means P3V3, which only touches J3/J6, needs just a single hop
# where its J6 spike must pass SWCLK's line).
_SWD_TREE = {
    "SWDIO": [("J3", "2"), ("J6", "2"), ("J7", "3")],
    "SWCLK": [("J3", "4"), ("J6", "4"), ("J7", "1")],
    "NRESET": [("J3", "10"), ("J6", "10"), ("SW1", "1")],
    "P3V3": [("J3", "1"), ("J6", "1")],
}
_SWD_LANE_Y = {"SWDIO": 58.80, "NRESET": 59.42, "SWCLK": 62.65, "P3V3": 62.90}
_HOP_MM = 0.65            # F_Cu-hop half-span around a crossed shallower
                          # B_Cu trunk (NRESET hopping SWDIO) -- clears
                          # via radius (0.3) + track halfwidth (0.1) +
                          # clearance (0.2) = 0.6mm from the crossed
                          # track's centerline, with a hair of margin.
# NRESET's PICO descent: gap pins 9/10 (x=23.805) -- east of the whole
# trace-bundle corridor (lanes max x=16.185, J3 landings max x=20.605) AND
# with real margin from J3's TD3 pad (edge x=20.975): the nearer 8/9 gap
# (x=21.265) is only 0.29mm from that edge, not enough for the hop-via
# NRESET needs there (0.5mm: via radius 0.3 + clearance 0.2) even though
# a plain track fits fine.
_NRESET_PICO_GAP = ("PICO", "30", "9", "10")
# SWCLK's J3/J6 columns (10.445/51.13) sit directly above a south-row GND
# pad at the *same* x -- jog to a clear column before descending past it.
_SWCLK_ESCAPE_X = {"J3": 7.5, "J6": 48.5}  # WEST -- east would cross
                                           # NRESET's B_Cu-hop F_Cu bridge
                                           # (a single-point obstacle at
                                           # x=14.255/23.805/54.94, y
                                           # 58.15-59.42) which only
                                           # exists east of J3/J6's own
                                           # columns here
_ROW_CLEAR_Y = 58.90     # south of J3/J6/J7's north-row pad bottom
                         # edge (58.45) by 0.45mm -- SWCLK's safe y to
                         # jog sideways in before continuing down
# P3V3's PICO descent: gap pins 1/2 (x=3.485, PICO's own westmost gap),
# then a short dogleg WEST to x=0.7 -- east (as originally tried) crosses
# the trace bundle's own TRACECLK lane (x=6.025, occupied y~49.0-55.4).
# The dogleg happens south of JP2 (pad bbox bottom edge 53.105 at
# x=2.215; GP0's guard-net breakout runs J1B(47.8)->JP2(52.255) right
# through that column) but the deep run down to the south band only
# rejoins x=7.0 (not staying at x=0.7 the whole way) -- x=0.7 clips the
# board's rounded SW corner once y gets as deep as the south band (arc
# center (3,61) r=3mm; solving for the min x clearing r+0.5mm clearance+
# 0.1mm halfwidth at y=62.9 gives x>=6.15), so the path returns east to
# x=7.0 (clear of both the corner and MH3's NPTH hole -- pad bbox x
# 2.4-5.6, y 58.4-61.6, r=1.6mm center (4,60); needs center-to-track
# >=1.6+0.25+0.1=1.95mm, x=7.0 gives 3.0mm) at y=57.0, i.e. *after*
# TRACECLK's lane has already ended (conv_start ~55.4) so the return
# jog can't cross it either.
_P3V3_PICO_GAP = ("PICO", "36", "1", "2")
_P3V3_WEST_X_MM = 0.7
_P3V3_DOGLEG_X_MM = 7.0
_P3V3_DOGLEG_Y_MM = 57.0


def _mm(x, y):
    return pcbnew.VECTOR2I(pcbnew.FromMM(x), pcbnew.FromMM(y))


def _pad(board, ref, num, index=0):
    fp = board.FindFootprintByReference(ref)
    assert fp is not None, f"route_trace.py: no footprint {ref!r} on board"
    matches = [p for p in fp.Pads() if p.GetNumber() == num]
    assert matches, f"route_trace.py: {ref} has no pad {num!r}"
    return matches[index]


def _pos(pad):
    p = pad.GetPosition()
    return (pcbnew.ToMM(p.x), pcbnew.ToMM(p.y))


def _bbox(pad):
    bb = pad.GetBoundingBox()
    return (pcbnew.ToMM(bb.GetLeft()), pcbnew.ToMM(bb.GetTop()),
             pcbnew.ToMM(bb.GetRight()), pcbnew.ToMM(bb.GetBottom()))


def _gap_x(board, ref, pin_a, pin_b):
    """Midpoint x (mm) between two adjacent same-row pads on `ref` -- a
    safe vertical-crossing lane through a dense THT header row."""
    xa = _pos(_pad(board, ref, pin_a))[0]
    xb = _pos(_pad(board, ref, pin_b))[0]
    return (xa + xb) / 2.0


def _approach_above(board, ref, pins, margin=0.3):
    """y (mm) just above the topmost edge of the given pads -- a safe
    point to be at before turning to thread the row's gap."""
    tops = [_bbox(_pad(board, ref, p))[1] for p in pins]
    return min(tops) - margin


def _net(board, name):
    ni = board.FindNet(name)
    assert ni is not None, f"route_trace.py: no net {name!r} on board"
    return ni


def _net_has_tracks(board, ni):
    nc = ni.GetNetCode()
    return any(t.GetNetCode() == nc for t in board.GetTracks())


def _add_track(board, ni, layer, pts, width_mm):
    """Add PCB_TRACK segments through waypoints `pts` ([(x,y),...] mm);
    skips zero-length hops."""
    width = pcbnew.FromMM(width_mm)
    segs = []
    for (x0, y0), (x1, y1) in zip(pts, pts[1:]):
        if (x0, y0) == (x1, y1):
            continue
        t = pcbnew.PCB_TRACK(board)
        t.SetStart(_mm(x0, y0))
        t.SetEnd(_mm(x1, y1))
        t.SetLayer(layer)
        t.SetWidth(width)
        t.SetNet(ni)
        board.Add(t)
        segs.append(t)
    return segs


def _add_via(board, ni, xy, dia_mm, drill_mm):
    v = pcbnew.PCB_VIA(board)
    v.SetPosition(_mm(*xy))
    v.SetViaType(pcbnew.VIATYPE_THROUGH)
    v.SetLayerPair(pcbnew.F_Cu, pcbnew.B_Cu)
    v.SetWidth(pcbnew.F_Cu, pcbnew.FromMM(dia_mm))
    v.SetDrill(pcbnew.FromMM(drill_mm))
    v.SetNet(ni)
    board.Add(v)
    return v


def _straight_then_diag(p0, p1):
    """[p0, mid, p1] where p0->mid is a straight H or V run for the
    "excess" delta (whichever of dx/dy is larger) and mid->p1 is a pure
    45-degree diagonal for the rest, ending exactly at p1 -- unlike a
    diagonal-first hop, this never has an extended straight run sitting
    at p1's own y (or x), so it can't clip through a whole row of pads
    at that coordinate; only mid->p1 (a single point per row) touches it."""
    x0, y0 = p0
    x1, y1 = p1
    dx, dy = x1 - x0, y1 - y0
    if abs(dx) >= abs(dy):
        excess = abs(dx) - abs(dy)
        sx = 1 if dx >= 0 else -1
        mid = (x0 + sx * excess, y0)
    else:
        excess = abs(dy) - abs(dx)
        sy = 1 if dy >= 0 else -1
        mid = (x0, y0 + sy * excess)
    return [p0, mid, p1]


def _meander(x0, y_start, n_passes, w_mm, step_mm, direction=1):
    """Length-matching meander: `n_passes` there-and-back teeth of width
    `w_mm`, each adding exactly 2*w_mm of path length while progressing
    2*step_mm down the same lane (x0). Returns (points, y_end)."""
    pts = [(x0, y_start)]
    y = y_start
    for _ in range(n_passes):
        pts.append((x0 + direction * w_mm, y))
        y += step_mm
        pts.append((x0 + direction * w_mm, y))
        pts.append((x0, y))
        y += step_mm
        pts.append((x0, y))
    return pts, y


def _route_trace_bundle(board):
    ds = board.GetDesignSettings().m_NetSettings
    width_mm = pcbnew.ToMM(ds.GetEffectiveNetClass("TRACECLK").GetTrackWidth())  # 0.3mm

    j1b_bottom = max(_bbox(_pad(board, "J1B", str(n)))[3] for n in range(1, 10))
    j1b_clear_y = j1b_bottom + _J1B_CLEAR_MARGIN_MM
    j3_pad_top = min(_bbox(_pad(board, "J3", chain[4]))[1] for chain in _TRACE_CHAIN)
    conv_start = [j3_pad_top - off for off in _CONV_START_OFFSETS_MM]
    row_safe_y = j3_pad_top - _ROW_SAFE_MARGIN_MM

    def _final_leg(lane_x, j3):
        """From (lane_x, conv_start_i) into J3 pad `j3`: straight-then-
        -diagonal onto (j3.x, row_safe_y) -- landing exactly on the dest
        column while still above the pad row -- then one pure-vertical
        drop into the pad itself (never sweeping in X while inside the
        row's Y span, so it can't clip a neighboring column's pad)."""
        pts = _straight_then_diag((lane_x, conv_start[i]), (j3[0], row_safe_y))
        pts.append(j3)
        return pts

    # Pass 1: each net's natural (unmeandered) length from J1B-clear straight
    # down to its own conv_start, then the final leg into J3.
    lanes = {}
    natural_len = {}
    for i, (rt_ref, gp_net, td_net, pico_pad, j3_pad, jog_dir, _n) in enumerate(_TRACE_CHAIN):
        rt_b = _pos(_pad(board, rt_ref, "2"))
        pico_pin = int(pico_pad)
        pair = (pico_pin, pico_pin + 1) if jog_dir > 0 else (pico_pin - 1, pico_pin)
        lane_x = _gap_x(board, "J1B", str(pair[0]), str(pair[1]))
        lanes[i] = lane_x
        j3 = _pos(_pad(board, "J3", j3_pad))
        pts = [(rt_b[0], rt_b[1]), (lane_x, rt_b[1]), (lane_x, j1b_clear_y), (lane_x, conv_start[i])]
        pts += _final_leg(lane_x, j3)[1:]
        natural_len[i] = sum(
            ((b[0] - a[0]) ** 2 + (b[1] - a[1]) ** 2) ** 0.5
            for a, b in zip(pts, pts[1:])
        )

    target_len = max(natural_len.values())
    n_passes = {
        i: max(0, round((target_len - natural_len[i]) / (2 * _MEANDER_W_MM)))
        for i in range(len(_TRACE_CHAIN))
    }

    # Pass 2: actually route, with the length-matching meander inserted
    # between the J1B crossing and each net's own conv_start.
    for i, (rt_ref, gp_net, td_net, pico_pad, j3_pad, jog_dir, _n) in enumerate(_TRACE_CHAIN):
        gp_ni = _net(board, gp_net)
        td_ni = _net(board, td_net)
        if _net_has_tracks(board, td_ni) or _net_has_tracks(board, gp_ni):
            continue  # idempotent: already routed

        pico = _pos(_pad(board, "PICO", pico_pad))
        rt_a = _pos(_pad(board, rt_ref, "1"))  # GP side
        rt_b = _pos(_pad(board, rt_ref, "2"))  # TDx side
        b_top = _bbox(_pad(board, rt_ref, "2"))[1]
        j3 = _pos(_pad(board, "J3", j3_pad))
        lane_x = lanes[i]

        # --- GP segment: PICO -> Rt.pad1, detouring around Rt.pad2 -------
        gp_dir = -jog_dir
        approach_y = b_top - _GP_APPROACH_MARGIN_MM
        gp_pts = [
            pico,
            (pico[0], approach_y),
            (pico[0] + gp_dir * _GP_JOG_MM, approach_y),
            (pico[0] + gp_dir * _GP_JOG_MM, rt_a[1]),
            rt_a,
        ]
        _add_track(board, gp_ni, pcbnew.F_Cu, gp_pts, _GP_WIDTH_MM)

        # --- TDx segment: Rt.pad2 -> gap lane -> J1B row -> meander -> J3 -
        td_pts = [rt_b, (lane_x, rt_b[1]), (lane_x, j1b_clear_y)]
        mpts, y_after = _meander(lane_x, j1b_clear_y, n_passes[i], _MEANDER_W_MM, _MEANDER_STEP_MM, direction=1)
        td_pts += mpts[1:]
        assert y_after <= conv_start[i], f"{rt_ref}: meander ({y_after}) overruns conv_start ({conv_start[i]})"
        td_pts.append((lane_x, conv_start[i]))
        td_pts += _final_leg(lane_x, j3)[1:]

        _add_track(board, td_ni, pcbnew.F_Cu, td_pts, width_mm)


def _spike_to_trunk(board, ni, px, py, trunk_y, width_mm, via_dia, via_drill, shallower, x_offset=0.0):
    """B_Cu path from (px,py) down to (px+x_offset,trunk_y), hopping to
    F_Cu around any already-routed shallower trunk (a (y, x_min, x_max)
    tuple) that this vertical run would otherwise cross on B_Cu.

    `x_offset` shifts the whole descent sideways (via a short jog right
    at the start) -- for the rare case where two different nets' pads
    share the same x column (see _SWD_TREE) -- and returns the offset x
    the caller should use as this node's contribution to the trunk span.
    """
    pxo = px + x_offset
    pts = [(px, py)]
    if x_offset:
        pts.append((pxo, py))
    lo, hi = sorted((py, trunk_y))
    hits = sorted(oy for oy, x0, x1 in shallower if lo < oy < hi and x0 <= pxo <= x1)
    merged = []
    for oy in hits:
        a, b = max(oy - _HOP_MM, lo), min(oy + _HOP_MM, hi)
        if merged and a <= merged[-1][1]:
            merged[-1] = (merged[-1][0], max(merged[-1][1], b))
        else:
            merged.append((a, b))
    cur = py
    for a, b in merged:
        pts.append((pxo, a))
        _add_track(board, ni, pcbnew.B_Cu, pts, width_mm)
        _add_via(board, ni, (pxo, a), via_dia, via_drill)
        _add_track(board, ni, pcbnew.F_Cu, [(pxo, a), (pxo, b)], width_mm)
        _add_via(board, ni, (pxo, b), via_dia, via_drill)
        pts = [(pxo, b)]
        cur = b
    pts.append((pxo, trunk_y))
    _add_track(board, ni, pcbnew.B_Cu, pts, width_mm)
    return pxo
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

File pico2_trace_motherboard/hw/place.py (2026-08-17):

"""Placement coordinate table for Task 14g (revert to THT connectors:
pico_socket -> stock RaspberryPi_Pico_Common_THT (40 THT pads "1".."40",
ON-GRID at the nominal pin positions -- no more 1.65mm outward SMD offset),
breakout_1x20 -> stock PinSocket_1x20_P2.54mm_Vertical (THT, PIN-1-ANCHORED
-- unlike the SMD_Pin1Left variant it replaces, which anchored at the row's
geometric centre), hdr_1x02/hdr_1x03 -> stock PinHeader_1x0N_P2.54mm_Vertical
(THT, also pin-1-anchored). Every coordinate below was re-derived from the
*actual* on-board courtyard/pad geometry (queried via pcbnew, not guessed) --
see .superpowers/sdd/task-14g-report.md for the derivation. Coordinates for
parts whose footprint did NOT change and whose position does not depend on
PICO's own pad grid (Rt1-5 excepted -- see below) are carried over unchanged
from Task 14e's SMD-era table.

POS: dict[ref -> (x_mm, y_mm, rotation_deg)] for every PARTS ref except PICO
(placed by build_board.py's `_place_pico`); MH1-4 are placed by
`_add_mounting_holes` (inset from BOARD_W_MM/BOARD_H_MM).

Coordinate frame: origin (0,0) top-left, mm, Y-down. Built against
BOARD_W_MM=92, BOARD_H_MM=64 (build_board.py) -- PICO center y = 32. With the
reverted RaspberryPi_Pico_Common_THT, its own pad rows sit at y=40.89
(pads 1-20) and y=23.11 (pads 21-40), pad-grid x 2.215..50.475 (2.54mm pitch,
on-grid); courtyard x -1.0..52.94, y 20.415..43.585 -- this is *exactly* the
pre-Task-14d (Task 12/14c) THT geometry, since PICO's own footprint and
`_place_pico`'s courtyard-based placement formula were never touched by the
SMD detour. Re-derive POS if the board size or any footprint changes.

Vertical budget (bottom-side chain, PICO courtyard bottom 43.585 -> board
bottom 64): Rt row (courtyard 43.825..45.775, hard against PICO, UNCHANGED --
its X/Y values already land exactly on PICO's THT pad columns, 0.00mm error,
see the Rt note below) + J1B (courtyard 46.005..49.645, only 3.64mm
perpendicular-width now -- the *stock THT* footprint, not the SMD zigzag
Task 14e sized this budget around) + a 5.22mm gap (49.645..54.865) that now
comfortably fits the relocated JP2/JP3 guard jumpers (rot=90, 3.63mm tall)
plus the "unplug while tracing" silk text + the debug row's existing 54.865+
courtyard (J3/J6, unchanged, still at y=59.2). THT shrinks J1B enough that
the JP2/JP3-in-the-gap placement Task 14e's report ruled out for the fat SMD
footprint fits again. Board width unchanged at 92mm, under the 100mm JLC
tier.

Region notes (co-design against hw/route_trace.py, which reads all pad
positions at runtime -- the two files are a matched pair; 14f re-derives its
own lane constants against these coordinates):
  - Rt1-5: UNCHANGED (4.755/9.835/12.375/14.915/17.455, y=44.8, rot=90) --
    verified these already sit at EXACTLY the new THT PICO pad-grid X
    columns for pads 2/4/5/6/7 (0.00mm error) with the same "hard against"
    Y gap (~0.24mm from PICO's new courtyard bottom) as before. These
    coordinates were never touched by the SMD detour (Task 14e's own report:
    "Rt1-5 unchanged, hard against PICO") -- they were designed against this
    exact THT grid back in Task 12 and are simply correct again now that
    PICO is THT once more.
  - J1B/J2B: the reverted breakout footprint anchors at PIN 1, not the row
    centre -- so J1B's/J2B's POS *is* pad 1's world position outboard of
    PICO pad 1/pad 21 respectively (both stock parts share the identical
    2.54mm pitch and pad-1-first numbering convention as PICO's own THT
    grid, so every one of the 20 pads lands EXACTLY on its PICO partner's X,
    by construction -- not approximated). J1B = PICO pad "1" position
    (2.215, 40.89) + 6.91mm south -> (2.215, 47.8), rot=90 (row runs +X with
    increasing pad number, matching PICO pads 1->20 running west->east).
    J2B = PICO pad "21" position (50.475, 23.11) + 7.51mm north ->
    (50.475, 15.6), rot=270 (row runs -X with increasing pad number,
    matching PICO pads 21->40 running east->west). These are the exact
    values Task 12/14c's THT-era place.py used (git show 4fb3f47:hw/place.py)
    -- re-verified against fresh pcbnew geometry, not just copied blind.
  - JP1/JP4/J_UART (hdr_1x03/hdr_1x02, top power corner): Task 14e's SMD-era
    top-corner layout (J8/LED_PWR/MH1 arrangement) is kept as-is -- it fixed
    real stale-position defects (JP1 crowding the left edge/MH1) that were
    NOT caused by the SMD footprint and would reappear if this task blindly
    restored the pre-14d numbers. Only the header anchors move: the old
    _SMD_Pin1Left footprint anchored at the row's centre, so its pin "1" sat
    at a zigzag-offset world position; the new THT footprint's pin "1" *is*
    the anchor. New POS = old (Task 14e) pad-"1" world position exactly, so
    the row occupies the identical world rectangle as before (same pitch,
    same numbering direction), just without the SMD zigzag's perpendicular
    stagger (each row is now a straight, and physically slimmer, line) --
    verified this reproduces the old courtyard's L/R (row-direction) extent
    to the sub-mm, so no new collisions with MH1/J8/R_NVD/etc.
  - JP2/JP3 (GP0/GP6 guard jumpers): relocated into the J1B -> debug-row gap
    (now 5.22mm tall, see the vertical-budget note), rot=90 so each header's
    2.54mm pitch runs along X (3.63mm tall, fits the gap) instead of Y.
    Pin "1" (the guarded GPIO) anchors EXACTLY on its PICO partner's X: JP2 =
    PICO pad "1"/GP0's x (2.215), JP3 = PICO pad "9"/GP6's x (22.535), both
    at y=52.255 (vertically centred in the gap, 0.795mm clear of J1B above
    and the debug row below). Straight-line guard-trace runs collapse from
    the SMD-era's 42-50mm (JP2/JP3 relocated east of J1B's row-end, per Task
    14e's report) down to ~11.4mm (JP2) / ~11.9mm (JP3) -- see the gate
    report for the exact figures.
  - Debug row (J3/J6/J7, plus a second JST-SH DEBUG connector later removed
    in Task 14i leaving its slot empty): UNCHANGED (footprint untouched,
    not PICO-grid-dependent) -- still >=10mm courtyard-to-courtyard,
    y=59.2. J3 x=14.89
    keeps the PICO-pad-"2" -> J3-pad-12 span well under the 30mm hard limit
    (recomputed for the new PICO pad "2" position -- see the gate report).
    SW1/C_NRESET unchanged.
  - Top peripherals (JP1/JP4/J8/J_STEMMA/LED pairs/R_NVD/J_UART) live in
    y<=13.6 (above J2B's new courtyard top). J8/J_STEMMA (true cable
    receptacles) keep >=10mm clear of each other; JP1/JP4/J_UART (vertical
    pin headers, no rigid plug body) are not held to that rule but still
    non-overlapping. JP1 shifted off the left edge and clear of MH1 (both
    were a stale-position defect, not new-footprint growth).
  - Host cluster (R_HDP/R_HDM/TP1/TP2/PDs/ESD_H) re-aligned to J5's real
    pad rows (HOST_DP y=19.0, HOST_DM y=21.0 -- GCT1046's own pad geometry,
    different from the old Molex-based assumption of 15.55/17.45).
  - TP1/TP2 sit symmetrically in-line on the host D+/D- rows (no stubs on
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

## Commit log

2026-07-30 pcb: umbrella tree — docs, handoff brief, jlc-cdp ordering tooling
    Home for self-contained PCB board repos (first: pico2_trace_motherboard,
    ordered as JLCPCB W2026073018593887). Boards are nested independent git
    repos, gitignored here; this repo versions the tree-level docs and the
    JLCPCB CDP ordering driver + wizard playbook.
2026-07-30 tools: semantic board compare (pads/tracks/vias/zones) for regen-equivalence proofs
2026-07-30 org: reusable layout — docs (pipeline/facts/parts), shared footprint lib, tools
    - docs/pipeline.md: netlist-driven architecture + gate battery + board-#2
    bootstrap steps
    - docs/kicad-pcbnew-facts.md: verified KiCad 9 scripting landmines
    - docs/parts-palette.md: LCSC-verified parts with tiers + JLC fee behavior
    - lib/pcb.pretty/: audited USB-C (C165948 PWR/DEV renumbers) + FTSH-110/105
    lands, copied from the board repo (boards stay self-contained)
    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
2026-07-30 docs: design spec + markdown table aligner
    Squash of 11dfbe9, f58c6f4 (original history: branch archive/kicad-build).
    [pico2_trace-B_Courtyard.gbr, pico2_trace-B_Cu.gbl, pico2_trace-B_Fab.gbr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]
2026-07-30 docs: netlist-driven KiCad build plan (17 tasks, fable-reviewed)
    Squash of 8d34e2c, 3ad6523.
    [pico2_trace-B_Courtyard.gbr, pico2_trace-B_Cu.gbl, pico2_trace-B_Fab.gbr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]
2026-07-30 scaffold: KiCad project, footprint map, shroud footprints, symbols
    Squash of c3a9cff, 302087c.
    [pico2_trace.kicad_pcb]
2026-07-30 netlist: connectivity model, graph helpers, .net emitter
    All power/debug/trace/USB/peripheral nets + pin-map lock; review fixes
    (distinct guard nets, GP11 soft-connect replacing the D+ gate FET).
    Squash of 54b3342..3ca2631 (7 commits).
    [checks.py, fp_lib.py, netlist.py]
2026-07-30 sch: generated ERC-clean schematic + PDF
    Squash of 51375b2.
    [pico2_trace.kicad_sch]
2026-07-30 pcb: footprints, nets, outline, constrained placement + trace silk
    Squash of cd813c2, 6b1452c, 6e620d1.
    [pico2_trace.kicad_pcb]
2026-07-30 pcb: trace bundle, SWD tree, power/USB routing; DNP realization
    Length-matched trace bundle; edge connectors rotated to face edges;
    INA219 option, EN pulldown, cap ratings. Squash of 5ebbf61..2de5eea (4).
    [pico2_trace.kicad_pcb, pico2_trace.kicad_sch]
2026-07-30 pcb: compact to 92x64; SMT-socket detour reverted to THT
    Co-designed placement + routing rewrite; hand-inserted connectors back
    to THT after the SMD experiment. Squash of 4fb3f47..d5493a2 (5).
    [pico2_trace.kicad_pcb, pico2_trace.kicad_sch]
2026-07-30 pcb: complete routing, GND pours + stitching, power widening
    All copper 0 non-GND unconnected; J10 SWD dupont added, redundant J4
    removed, antenna keepout cleared; VBUS_NET widened; both-layer GND
    zones + stitching vias. Squash of 0dd589d, 7224fb8, 98ee5bf, 9fa26b4.
    [pico2_trace.kicad_pcb, pico2_trace.kicad_sch]
2026-07-30 pcb: DFM + pre-fab review fixes; fab package + BRINGUP
    Via sizes, silkscreen legend, refdes/label clamping; diode direction
    fix, J5 shell ground, VSYS diode-OR feed + decoupling, V5_JTRACE
    widening; V2 trace-rate claim corrected; gerbers/BOM regenerated.
    Squash of 93dd81b, 978ebdd, 41a4014, 6d67559, 0d99a43. Board copper
    frozen here (= original 6d67559 geometry).
    [BOM.csv, BOM_jlc.csv, pico2_trace.kicad_pcb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]
2026-07-30 docs: JLC BOM/CPL, ordering walkthrough, sourcing + assembly config
    Verified LCSC numbers, CPL placement file, full-assembly rework,
    cost-reduction passes (measured 1.27mm bare headers, Basic swaps),
    order-time decision + substitution tables, THT deselect experiment.
    Squash of 2e80fbf..770745e (8 commits).
    [BOM.csv, BOM_jlc.csv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]
2026-07-30 pcb: J8 micro-B -> USB Type-C power input (C165948) + CC Rd
    usb_c_pwr renumbered footprint, R_CC1/R_CC2, VBUS corridor re-derived,
    pour stitch moved; fab regenerated. Squash of 5bdcdeb, 829f8fc.
    [BOM.csv, BOM_jlc.csv, pico2_trace.kicad_pcb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]
2026-07-30 pcb: J9 micro-B -> USB Type-C device port (C165948) + CC Rd
    usb_c_dev footprint (D+/D- pad pairs bridged, two-layer weave),
    R_CC3/R_CC4, detect divider relocated south, DEV_VBUS_DET tail
    re-derived; fab regenerated. Squash of c040a93, 558b722.
    [BOM.csv, BOM_jlc.csv, pico2_trace.kicad_pcb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]
2026-07-30 docs: note history consolidation (originals on archive/kicad-build)
    [pico2_trace.kicad_sch]
2026-07-30 review + order: pre-order audit fixes; JLCPCB W2026073018593887
    Three-reviewer audit (footprints/wiring/fab package) -- no fab-blocking
    defect; doc staleness fixed, CC-net regression guards added; order
    logged (Y14, 5 PCB / 2 assembled, $81.27). Squash of 0218f22, 51fec76.
    [pico2_trace.kicad_pcb]
2026-07-30 org: fold pico2_trace_motherboard into the monorepo
    Boards now live inside this single repo (Adafruit MBAdafruitBoards
    style) instead of nested independent repos. The board's folded
    15-commit history was replayed under its prefix; the original
    50-commit standalone history is preserved verbatim on branch
    archive/pico2-original (root-level paths). Zip artifact carried over,
    sha256-verified against the manifest.
2026-08-17 pcb(revb): J5 USB-A mouth flush to the board edge + edge-mouth guard
    REV A (fabricated, tag rev-a-pico2) shipped with J5's USB-A opening
    recessed 6.61mm inside the x=92 edge -- a cable overmold fouls on the
    ledge in front of it. Its anchor came from the pad rows and the
    mouth-to-edge dimension was never asserted; J8/J9 had explicit flush-lip
    arithmetic, J5 predated that convention.
    - place.py: J5 anchor 78.615 -> 85.225 (mouth now exactly 92.00);
    BOARD_REV_TEXT REV A -> REV B so the two are distinguishable in hand
    - pour.py: stitch via (78.0,22.0) -> (75.0,26.0), 1.0mm from J5's
    relocated HOST_DM pad (DRC clearance + hole_clearance)
    - checks.py: new test_edge_connector_mouths asserts ev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
    [pico2_trace.kicad_pcb, pico2_trace.kicad_sch]
2026-08-21 bringup: trace validated — 180 MHz core default, 120 MHz TRACECLK ceiling (V2 limit)
    First bring-up on the assembled board: 180 MHz core / 90 MHz TRACECLK
    width 4 passes the cdc_msc enumeration burst 3/3 with zero overflow,
    needing +5 ns data sampling (loaded eye +4000..+5000 ps, <= +3000 dead).
    Ceiling ladder: 240 MHz core / 120 MHz TRACECLK is the maximum (TD
    +3500); >= 125 MHz TRACECLK fails at every sample delay, trace width,
    and pad drive — the J-Trace PRO V2 at its documented limit (Arm spec
    100 MHz in-spec; SEGGER's tuned-V2 best is 120 MHz; the 150 MHz figure
    is V3/V4 hardware). Board SI exonerated: the wall is razor-sharp and
    the J1B return-path gaps never surfaced. Results in d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
2026-08-21 bringup: fly-wire-era workarounds re-validated on the PCB — DBGPAUSE + fast pads removed, clock-switch truncation confirmed
